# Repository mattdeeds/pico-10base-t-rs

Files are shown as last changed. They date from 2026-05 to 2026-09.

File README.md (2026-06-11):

# pico-10base-t-rs

**Software 10BASE-T Ethernet (PIO bit-bang TX *and* RX) and wireless
router on the Raspberry Pi Pico 2 W**. Uses the dual **Hazard3 RISC-V** cores with pure Rust (`no_std`).
A `~$5` micro talks 10 Mbit Ethernet to a real
network with PIO, DMA, a RS-485 transceiver, and magnetics.

Rust port of [C project](https://github.com/mattdeeds/Pico-10BASE-T), which extended
[kingyoPiyo/Pico-10BASE-T](https://github.com/kingyoPiyo/Pico-10BASE-T) (the
original C/PIO Manchester **TX-only** design) with a **RX** path — Manchester
decode over an RS-485 transceiver. This Rust rewrite runs on `rp235x-hal`, exposes
the NIC as a [smoltcp](https://github.com/smoltcp-rs/smoltcp) `phy::Device`, then
grows into a NAPT router with a cyw43 Wi-Fi AP.

## Two builds

The build features give you either layer with no code changes:

- **A standalone software 10BASE-T NIC** (default build): the bit-bang PHY +
  smoltcp. A static-IP host that does ARP / ICMP / UDP / a tiny HTTP server.
- **A wireless router** (`--features router`): the same 10BASE-T as the WAN, a
  cyw43 2.4 GHz AP as the LAN, with L3 forwarding + NAPT between them, a DHCP
  server, and a status page.

## What to expect (performance)

Full detail + method in **[`docs/performance.md`](docs/performance.md)**. Headlines
(measured on real hardware):

| Path | Throughput | Note |
|---|---|---|
| 10BASE-T **TX** (device→host, TCP) | best **~0.95–1.0 MB/s**, typical ~0.4–0.7 | near line rate when clean; half-duplex collision variance |
| 10BASE-T **RX** (host→device, TCP bulk) | **~310 KB/s** @ 0.2% wire loss | stock MTU; ACK-pacing + decode-out-of-IRQ fixes (2026-06) |
| 10BASE-T latency | **~2.6 ms**, 0% loss | |
| Wi-Fi LAN (cyw43 AP) | **~909 down / ~716 up KB/s** | router build |

> **It's a fun software-PHY NIC and a working router, not a
> fast router.** The bit-bang TX is near line rate; RX bulk runs ~310 KB/s
> (the long-suspected "decode/PHY ceiling" turned out to be a fixable
> DMA-starvation bug — see `docs/rx-bulk-ceiling.md` §10). Latency is great;
> ideal for low-rate / IoT-scale traffic.

## Hardware

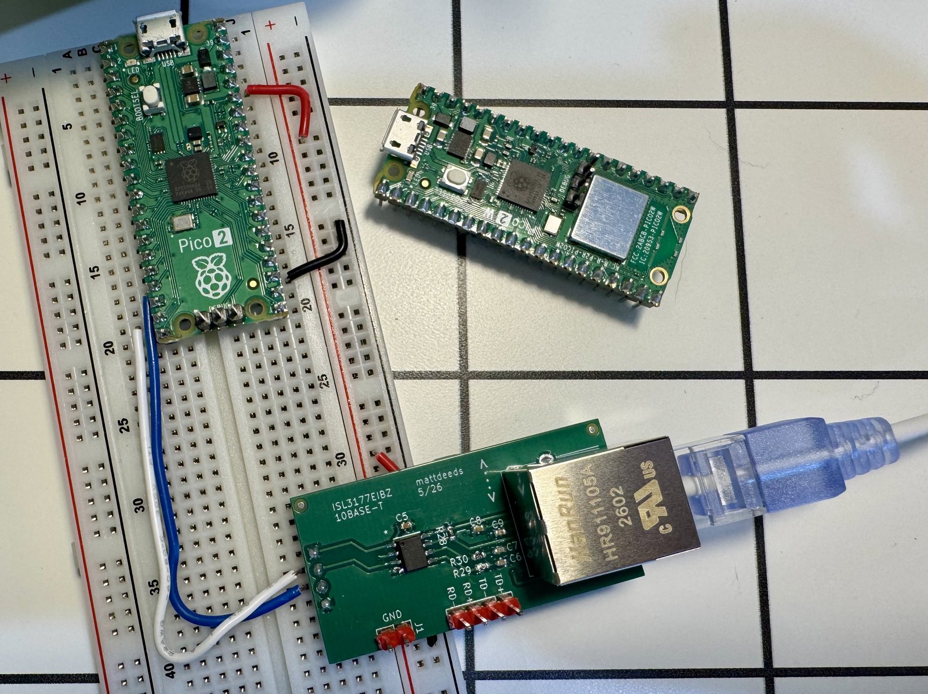
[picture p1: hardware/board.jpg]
The 10BASE-T front-end board (ISL3177E + HR911105A) on a breadboard with a Pico 2, a Pico 2 W alongside, and an Ethernet cable plugged in


- **Raspberry Pi Pico 2 W** (RP2350). The plain 10BASE-T NIC build also runs on a
  non-W Pico 2; the Wi-Fi/router builds need the W (cyw43).
- **External 10BASE-T front end:** an **ISL3177E** transceiver + **HR911105A** RJ45
  magnetics. KiCad board design + gerbers/BOM are in [`hardware/`](hardware/).

| Signal | Pico 2 pin |
|---|---|
| ISL3177E `RO` (receiver out → MCU) | GP13 |
| ISL3177E `DI` (driver in ← MCU) | GP14 |
| Onboard LED (heartbeat, NIC build) | GP25 |
| SWD debug probe | SWCLK / SWDIO / GND |

## Toolchain

- Rust ≥ 1.82, target `riscv32imac-unknown-none-elf`
  (`rustup target add riscv32imac-unknown-none-elf`).
- Flashing: [picotool](https://github.com/raspberrypi/picotool) (USB), or OpenOCD
  over SWD:
  `openocd -f interface/cmsis-dap.cfg -f target/rp2350-riscv.cfg -c "program <elf> verify reset exit"`.

## Build & flash

```bash
# Standalone 10BASE-T NIC (static IP 192.168.37.24) — the default build
cargo build --release
cargo run   --release            # flashes via the .cargo/config.toml runner

# Other variants
cargo build --release --features wan-dhcp    # NIC as a DHCP client (WAN-style)
cargo build --release --features wireless    # cyw43 AP only (no wired side)
cargo build --release --features router      # WAN(10BT) + LAN(Wi-Fi) + NAPT router
```

The device logs status over **USB CDC** (assert DTR to read it): `[R2b]` heartbeat,
`[Rx]` decode stats, and on the router build `[Cyw43]` / `[Wan]` / `[Fwd]` / `[Nat]`
/ `[Perf]` lines.

### Wired host setup (10BASE-T peer)

The device emits Normal Link Pulses only (no auto-negotiation), so force the peer
NIC to 10 Mbit half-duplex:

```bash
sudo ethtool -s <iface> speed 10 duplex half autoneg off
sudo ip addr add 192.168.37.19/24 dev <iface>
```

### Router credentials

The cyw43 AP SSID/passphrase are **compile-time placeholders** in
`src/wireless.rs` (`AP_SSID` / `AP_PASSPHRASE = "change-me-please"`). **They should be changed.**

## How it works

- **PIO0** drives the 10BASE-T PHY: **SM0** = 20 MHz Manchester TX (256-entry
  lookup table → single-ended on GP14), **SM1** = 60 MHz RX sampler (`in pins, 1`,
  3 samples/half-bit), **SM2** = a carrier-detect SM for the half-duplex CSMA/CA
  TX gate.
- **DMA** ferries the RX sampler into a double-buffer; **core 1** owns the
  `DMA_IRQ_0` handler running an **edge-tracking DPLL Manchester decoder** + FCS
  (re-anchors to each mid-bit transition to cancel clock drift).
- **core 0** runs smoltcp (the control plane) and, on the router build, an
  **embassy executor** hosting the cyw43 `Runner`, the LAN/WAN net tasks, and the
  custom L3 forwarding + NAPT data path. **PIO1** is a custom gSPI transport to the
  cyw43 radio.
- An **RP2350 hardware watchdog** auto-reboots + recovers the device if the loop
  ever wedges (a known intermittent hang under sustained full-MTU inbound).

## Repo layout

The package is **a library + a binary**: the transport core is a reusable
library crate that other projects can take as a Cargo dependency (e.g.
[pico-remote-probe](https://github.com/mattdeeds/pico-remote-probe), a
network-attached SWD debug probe, uses it as its NIC); the router application
in `src/main.rs` is the in-tree consumer.

- `src/lib.rs` — the **library**: `eth_tx`, `eth_rx`, `eth_rx_dpll`, `eth_mac`,
  `manchester`, `crc` (the **10BASE-T bit-bang NIC**, PHY + MAC), plus
  `multicore_riscv` (Hazard3 core-1 launch), `pico_reset` (picotool USB reset),
  `pio_util`, and — behind the `cyw43-phy` feature — `cyw43_phy` (a smoltcp
  `phy::Device` over the cyw43 radio, no executor required).
- `src/main.rs`, `src/wireless.rs`, `src/forward.rs`, `src/conntrack.rs`,
  `src/dhcp_server.rs`, `src/wan.rs` — the **router** (cyw43 + forwarding + NAPT).
- `docs/` — a thorough **engineering log** (how this was built + characterized).
  Start with [`docs/README.md`](docs/README.md).
- `tools/` — host-side measurement scripts.

## Limitations

Half-duplex (by MAC policy; the transceiver is FD-*capable* but FD only helps
contended traffic); no auto-negotiation; RX bulk ~310 KB/s (next bounds:
decode CPU time and the DMA half-fill ACK-latency floor — see
`docs/rx-bulk-ceiling.md` §10). A hardware watchdog guards against hangs
(the old full-MTU-inbound wedge stopped reproducing after the 2026-06 RX
restructure, but the watchdog stays).
Just an educational project, please don't replace your home router with this.

## Credits

- [kingyoPiyo/Pico-10BASE-T](https://github.com/kingyoPiyo/Pico-10BASE-T) — the
  original C/PIO 10BASE-T **TX** design (MIT, Copyright © 2022 kingyo). This project
  is a Rust port of the author's own
  [C project](https://github.com/mattdeeds/Pico-10BASE-T), which extended
  kingyoPiyo's work with the **RX** path (Manchester decode over an RS-485
  transceiver).
- [Niccle](https://github.com/timonvo/niccle) — a reference for the
  Manchester RX decode approach and circuit design.
- [embassy](https://github.com/embassy-rs/embassy) `cyw43` driver + firmware blobs
  (Infineon permissive binary license — see `cyw43-firmware/`).
- [smoltcp](https://github.com/smoltcp-rs/smoltcp), [rp235x-hal](https://github.com/rp-rs/rp-hal).

## License

Dual-licensed under either **MIT** ([LICENSE-MIT](LICENSE-MIT)) or
**Apache-2.0** ([LICENSE-APACHE](LICENSE-APACHE)), at your option. The cyw43
firmware blobs in `cyw43-firmware/` carry their own (Infineon) permissive license.

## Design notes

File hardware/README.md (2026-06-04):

# Hardware — 10BASE-T front-end board

KiCad project for the **10BASE-T analog front end** used by this project (and by
its [C ancestor](https://github.com/mattdeeds/Pico-10BASE-T)). It breaks an
**ISL3177E** RS-485 transceiver and an **HR911105A** RJ45 jack (integrated
magnetics) out to single-ended GP13 (RX) / GP14 (TX) on a Raspberry Pi Pico 2, so
the Pico's PIO can both drive and receive a real 10BASE-T differential line.

The circuit is based on the [Niccle](https://github.com/timonvo/niccle) reference
design. This is `v2` — a small prototype/test board, not a product.

> ⚠️ **Do not connect this to PoE equipment.** It's an educational software-PHY
> front end with no isolation guarantees beyond the magnetics.

## How it works

The ISL3177E is an RS-485 transceiver repurposed as a 10BASE-T line driver +
slicer:

- **TX:** Pico `GP14` → `DI` (driver input) → differential `Y`/`Z` → AC-coupling →
  HR911105A magnetics → RJ45 TX pair.
- **RX:** RJ45 RX pair → magnetics → differential `A`/`B` → `RO` (receiver output,
  single-ended Manchester) → Pico `GP13`, where the PIO sampler + software DPLL
  decode it.

See the repo's top-level [`README.md`](../README.md) ("How it works") for the
firmware side and the exact Pico pin map.

## Bill of materials

| Ref | Value | Footprint | Role |
|---|---|---|---|
| U1 | **ISL3177EIBZ** | SOIC-8 | RS-485 transceiver (TX driver + RX slicer) |
| J6 | **HR911105A** | RJ45 (Hanrun, horizontal) | jack + integrated magnetics |
| C5, C8, C9 | 100 nF | 0603 | supply decoupling |
| C6, C7 | 10 nF | 0603 | AC-coupling to the line |
| R28 | 100 Ω | 0603 | differential line termination |
| R29, R30 | 50 Ω | 0603 | source termination |
| J1 | 1×02 header | 2.54 mm | power (3V3 / GND) |
| J2, J3 | 1×04 header | 2.54 mm | signal / Pico connections |

(Source of truth: [`production/bom.csv`](production/bom.csv).)

## Files

- `10BASE-T_Test-v2.kicad_pro` / `.kicad_sch` / `.kicad_pcb` — the KiCad 10 project
  (schematic + PCB). Open `.kicad_pro` in KiCad.
- `production/` — fabrication outputs:
  - `10BASE-T_Test-v2.zip` — Gerbers + drill files (2-layer board), ready to send
    to any board house.
  - `bom.csv` — bill of materials.
  - `positions.csv` — pick-and-place / centroid (for assembly).
  - `designators.csv`, `netlist.ipc` — supporting fab data.

## Fabricating it

Upload `production/10BASE-T_Test-v2.zip` to a PCB fab (JLCPCB, PCBWay, OSH Park,
etc.) as a standard 2-layer board. For assembly, supply `bom.csv` + `positions.csv`.
To regenerate any of these, re-run the export from KiCad (the
[Fabrication Toolkit](https://github.com/bennymeg/Fabrication-Toolkit) settings
used are in `fabrication-toolkit-options.json`).

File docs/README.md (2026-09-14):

# docs/ — engineering log & design notes

This folder is the project's **engineering log**: how the software 10BASE-T NIC and
the router were designed, built, and characterized — including the dead ends and
the honest limits. It's deliberately kept (not pruned) because the "how we got
here" is half the value of a project like this.

## Start here

- **[performance.md](performance.md)** — *what to expect*: measured throughput,
  latency, CPU, and the honest limits. Read this first.
- **[router-plan.md](router-plan.md)** — overall router architecture: the "Option-A"
  decision (keep Hazard3 RISC-V, port the cyw43 transport — no embassy-rp), the
  PIO/DMA/core layout, the data path.

## Key findings (the interesting bits)

- **[rx-bulk-ceiling.md](rx-bulk-ceiling.md)** — the RX-of-bulk investigation. Its
  "PHY limit at ~100 KB/s" verdict was later overturned: the cause was DMA-starved
  sample loss, and RX now runs ~310 KB/s (see [performance.md](performance.md)).
- **[full-duplex-analysis.md](full-duplex-analysis.md)** — the ISL3177E is
  full-duplex-*capable* (half-duplex is a MAC policy). Forced-FD on-wire experiment:
  FD helps only contended traffic and is still RX-decode-bounded → not worth the
  auto-negotiation work.
- **[cpu-dpll-plan.md](cpu-dpll-plan.md)** + **[clock-recovery-decoder-plan.md](clock-recovery-decoder-plan.md)**
  — the RX Manchester decoder: an edge-tracking DPLL on core 1 that cancels clock
  drift; the offline corpus bench; and the §9d "residual is PHY-limited" verdict (since overturned).
- **[pio-dpll-report.md](pio-dpll-report.md)** — retrospective on the *PIO-side*
  decoder attempt (capped ~40% full-MTU → pivoted to the CPU DPLL on core 1).

## The build log (roughly chronological)

- **[pio-decoder-plan.md](pio-decoder-plan.md)** — the PIO clock-recovery decoder plan.
- **[r15-plan.md](r15-plan.md)** — WAN-as-DHCP-client + unifying both interfaces under one executor.
- **[r16-plan.md](r16-plan.md)** — L3 forwarding (LAN↔WAN transit).
- **[r17-plan.md](r17-plan.md)** — NAPT / conntrack (the router milestone).
- **[r18-plan.md](r18-plan.md)** — DNS relay + management status page.
- **[r19-plan.md](r19-plan.md)** — cold-start gateway-ARP fix.
- **[perf-characterization-plan.md](perf-characterization-plan.md)** — the perf track:
  the cyw43 LAN isolation + the gSPI 2→15 MHz fix, the routed-throughput rig.
- **[low-power-plan.md](low-power-plan.md)** — low-power roadmap (scoped, backburnered;
  gated on a power meter).

## Meta

- **[release-checklist.md](release-checklist.md)** — the open-source prep checklist.
- **[log.md](log.md)** — raw notes: history and lessons moved out of code comments.

> Note: some docs reference internal "R-numbers", "gotcha #N", and session notes
> (`RESUME.md`, not published) — that's the raw lab notebook.

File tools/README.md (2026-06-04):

# tools/

Host-side scripts for testing and characterizing the firmware. Most are plain
Python/bash with no dependencies beyond `iperf3`/`nc`/`ethtool` where noted.

## Measurement / telemetry
- **`cdc_read.py`** — read the device's USB-CDC telemetry for N seconds
  (`python3 tools/cdc_read.py 12`). Auto-detects the Pico CDC by product string;
  asserts DTR. The workhorse for reading `[R2b]`/`[Rx]`/`[Perf]`/… lines.
- **`rx-decode-sweep.py`** — RX FCS-fail rate vs frame size (UDP to a closed port =
  pure decode, no TCP). Drives the `docs/rx-bulk-ceiling.md` size curve.
- **`lan_upload.py`** — cyw43 Wi-Fi LAN upload throughput (client → device `:9999`
  sink); pairs with `curl http://<ap>/bulk` for download.

## Offline decoder bench
- **`clock-recovery/`** — develop the RX Manchester decoder without flashing:
  a captured raw-sample corpus + `harness.py` (scores per-byte error bins + FCS-OK)
  + `noise_compare.py` (matched-filter vs single-sample noise robustness). See its
  own README and `docs/clock-recovery-decoder-plan.md`.
- **`dpll-rust/`** — a small standalone Rust crate mirroring the decoder for offline
  iteration.
- **`conntrack_selftest.rs`** — host self-test of the NAPT conntrack logic
  (`rustc -O tools/conntrack_selftest.rs && ./conntrack_selftest`).

## Router / routed-throughput rig (needs root for setup)
- **`wan-test-host.sh`** — turn this host into the device's WAN upstream gateway
  (dnsmasq DHCP+DNS on the wired NIC + nftables masquerade out your uplink).
- **`rig-env.sh`** — shared config for the rig (sourced; override via env). ⚠️ set
  `AP_SSID`/`AP_PSK` to match your firmware AP creds (`src/wireless.rs`).
- **`router-rig-up.sh`** (root) → **`router-measure.sh`** (no root, iperf3 through
  the NAT) → **`router-rig-down.sh`** (teardown); **`router-throughput.sh`** is the
  all-in-one wrapper. See `docs/perf-characterization-plan.md`.
- **`r18-lan-validate.sh`** — LAN join + DNS-through-NAT + mgmt-page check.

## Misc
- **`99-pico-rust.rules`** — udev rules so the Pico CDC + CMSIS-DAP probe are
  accessible without root (`sudo cp tools/99-pico-rust.rules /etc/udev/rules.d/`).

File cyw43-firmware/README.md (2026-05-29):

# CYW43439 firmware blobs (vendored)

Binary blobs for the CYW43439 wireless chip on the Pico 2 W, vendored from the
[embassy](https://github.com/embassy-rs/embassy) project's `cyw43-firmware/`
directory (which in turn sources them from
<https://github.com/georgerobotics/cyw43-driver/tree/main/firmware>).

| File | Purpose |
|---|---|
| `43439A0.bin` | WiFi firmware (231077 B) |
| `nvram_rp2040.bin` | Board NVRAM for the Raspberry Pi Pico-W-family module (used on the Pico 2 W) |
| `43439A0_clm.bin` | CLM (country/regulatory) blob — loaded by `Control::init` |

Loaded 4-byte-aligned via `cyw43::aligned_bytes!`. See `src/wireless.rs`
(`cyw43_new_blocking`) and `docs/router-plan.md` §11. Licensed under the
Infineon permissive binary license — see the `LICENSE-*.txt` here.

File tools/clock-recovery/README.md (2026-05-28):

# Clock-recovery offline bench (Phase 0)

Offline platform for developing the clock-recovery decoder without flashing the
device per iteration. See `docs/clock-recovery-decoder-plan.md` for the full
plan and A1 for why this is needed (open-loop `F+4+6k` sampling drifts off over
a long frame; full-MTU RX is ~1.7% FCS-ok).

## What's here

- `corpus/*.bin` — raw RX **sample** buffers (packed sample bits, LSB-first,
  8 samples/byte) of full-MTU frames captured off the device. Each is one
  active run (~9155 bytes) for a frame whose payload is `payload[i] = i & 0xFF`.
  These carry the *real* ppm drift + jitter, so a decoder tested against them
  faces exactly what the device faces.
- `harness.py` — runs a candidate decoder over the corpus and scores it:
  per-byte payload error rate binned by frame position (shows drift) + FCS-ok
  count (the acceptance metric). Ships with `decode_current`, a faithful model
  of the on-device open-loop decoder.
- `capture.py` — host side of corpus collection (needs the capture firmware).
- `pio_dump.py` — host side of the **Phase 2b live PIO-decoder bring-up** (see
  below). Validates the real PIO decoder's decoded-byte output off the wire, and
  has an offline `--selftest` that needs no hardware.

## Baseline (current open-loop decoder)

```
$ python3 harness.py
... FCS-ok 0/N ...
  bin 0 frame-bytes   42-225     0.0%
  bin 1 frame-bytes  226-409     0.0%
  bin 2 frame-bytes  410-593     0.0%
  bin 3 frame-bytes  594-777     ~0-3%
  bin 4 frame-bytes  778-961    ~14-24%
  bin 5 frame-bytes  962-1145   ~17-50%   <- ~50% = sample point on a bit boundary
  bin 6 frame-bytes 1146-1329   ~35-74%
  bin 7 frame-bytes 1330-1513   ~82-89%
```

Perfect for ~575 bytes, then a monotonic ramp = clock drift.

## Phase 1 result — clock recovery (DONE)

`decode_edge_track` re-anchors to each per-bit Manchester transition (recurs
~6 samples apart at `F+5+6m`) and samples one sample before it (= `F+4+6m`), so
drift can't accumulate. On the corpus it drives **every bin to 0% and FCS-ok to
N/N** (robust across window W=1–3) — see `harness.py` output. This is the
algorithm to take to firmware (Phase 2); the per-bit edge search makes a CPU
port borderline vs the IRQ budget, so PIO-side recovery is the likely
production path (see `docs/clock-recovery-decoder-plan.md`).

## Workflow

1. Develop a candidate `decode_X(buf) -> (F, frame_bytes)` in `harness.py`,
   set `DECODER = decode_X`, run `python3 harness.py`, iterate to flat/N-of-N.
2. Port the validated algorithm into `src/eth_rx.rs` (Phase 2) and re-run the
   on-device acceptance tests (Phase 3).

## Phase 2b — live PIO decoder bring-up (`pio_dump.py`)

`src/eth_rx_pio.rs` is the production decoder: a PIO program (PIO1 SM0) that
re-syncs to every Manchester edge in hardware (the `decode_pio_model` algorithm,
SM @ 150 MHz, `[8]`-cycle boundary-skip). The TEMP scaffolding in `main.rs`
(Phase 2b) runs it **in parallel** with the working RX so the device stays
functional, drains its decoded-byte FIFO into a 2048-byte window, and dumps that
window over UDP broadcast `:1234` in 512-byte chunks
(`dec_id|seq|cap_len | data[512]`).

The decoded bytes ARE the decoded bitstream, LSB-first per byte (PIO `in`
shift-right + autopush(32) + `to_le_bytes`) — the exact bit order
`harness.sample_bit` uses — so `pio_dump.py` reassembles a window, finds the SFD,
extracts the frame, checks FCS, and scores the same per-byte error bins.

```
# Offline first — proves the host pipeline (model -> pack -> reassemble -> FCS)
# end-to-end without flashing. Expect FCS-ok N/N, flat bins, "self-test PASS".
$ python3 pio_dump.py --selftest

# On-wire (after flashing the Phase 2b firmware; SWD-flash the first time per
# docs/pio-decoder-plan.md §8). Blasts known-pattern full-MTU frames at the
# device and validates the dumped windows.
$ python3 pio_dump.py
#   dec_id 0: frame 1518B  sfd@bit 61  inv=False  FCS OK
#   ... FCS-ok N/N, flat bins  => PIO decoder works, D=8 is in the window.
```

Reading the result: **flat bins + FCS-ok** = the PIO decoder produces correct
full-MTU bytes and the `[8]` skip delay lands in the working window. A **drift
ramp** (like the open-loop baseline) = the skip delay is slightly off (resample
straying toward a bit boundary) — nudge the `[8]` in `eth_rx_pio.rs`. **No SFD /
garbage** = polarity or gross timing wrong. The valid `[n]` range is ~6–12
cycles (resample at `n+2`, between the boundary edge ~7.5 and the next mid-bit
~15); `8` targets the centre.

## Re-collecting / expanding the corpus

The corpus here is enough to start Phase 1, but the plan calls for more ppm/
jitter variation (capture across reboots / warm-up). To re-capture you need the
**temporary capture firmware** (kept out of `main` to keep it shippable):

- `src/eth_mac.rs` — add to `EthRxShared`: `cap_buf: [u8; CAP_MAX]`, `cap_len`,
  `cap_id`, `cap_armed` (`CAP_MAX = 10240`). In `process_completed_half`, after
  the `mac_accept` check, when `cap_armed && dst == our_mac && len > 8000`, copy
  `bytes[off..off+len]` into `cap_buf`, set `cap_len`, bump `cap_id`, clear
  `cap_armed`. Add `arm_capture()`, `cap_status() -> (id, len)`,
  `cap_copy(off, &mut [u8]) -> usize`.
- `src/main.rs` — every 20 ms send one chunk over `send_udp_broadcast` with the
  header `cap_id|cap_len|n_chunks|chunk_idx` + up to 512 data bytes, cycling
  `chunk_idx`; re-arm every ~200 chunks (~4 s); `arm_capture()` once at startup.

Then `python3 capture.py` (sends test frames + reassembles chunks into
`corpus/`). Revert the firmware before shipping.

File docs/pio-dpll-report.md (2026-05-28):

# PIO DPLL — what we tried, why it stops at ~40 % full-MTU

A retrospective on the Phase 2b–2d attempt to build a Manchester clock-recovery
decoder entirely in PIO on the RP2350. Companion to `pio-decoder-plan.md`
(detailed plan + iteration log) and the `pio-decoder-phase2b-onwire` memory.

Written 2026-05-28 after deciding to pivot to a CPU DPLL on the 2nd Hazard3
core.

## TL;DR

**Best PIO-only result: ~40 % full-MTU FCS-OK** (v1+180 MHz: `eth_rx_pio.rs`
at commit `d72360f`), with 6/6 FCS-OK at 512 B / flat 0 % bins on successful
decodes. **Ceiling is structural, not a tuning miss**: PIO has no arithmetic
for a real loop-filtered DPLL, the 2-cycle input synchronizer forces a
mutual-exclusion between "polls land on the edge" and "loop = bit period," and
mid-bit vs boundary Manchester edges are both real, validated transitions —
distinguished only by *phase*, which PIO can't track. CPU DPLL on the unused
2nd Hazard3 core is the path to ≥95 %.

## Goal (locked acceptance criteria, see `pio-decoder-plan.md` §11)

- **P1**: Full-MTU (1518 B frame) FCS-OK **≥ 95 %** at low rate, OR — if a
  residual floor remains — that floor is *PHY-limited* (flat per-byte error
  bins, no drift ramp, no slip cascade), not decoder-limited.
- **P2**: No loss-of-lock cascade. A single bit/edge error stays local; no
  frame may show the `0xaa`/`0x55` cascade signature.
- **S1**: small frames (≤512 B) no worse than baseline.
- **S2**: zero CPU decode cost (the Finding-2 payoff).

A1 baseline (open-loop CPU decoder, what we were trying to beat): ~575 B clean
then a drift ramp through 50 % to ~89 % errors at full MTU; full-MTU FCS-OK
~1.7 %.

## What we tried (iterations)

| Phase | Approach | Result | Why it didn't clear the bar |
|---|---|---|---|
| 2b — fixed `[8]` delay (`b863651`) | After mid-bit edge, blind delay D ≈ 0.67 bit, resample level, repeat | Clean to ~554 B (single-edge slip past that) | Wait catches *any* edge after the coast — a jittered boundary edge or noise becomes the new phase reference, slipping the loop |
| 2c — interval classifier (offline + PIO) | Measure inter-edge interval; classify ~T (mid-bit) vs ~T/2 (boundary); track at-mid/after-boundary state | Same slip rate as `[8]` | Inside runs of identical bits the Manchester signal is a clean square wave (edges every T/2); *every* interval is T/2, so interval gives no discrimination. The mid/boundary state alternation is then the entire decode — and a single bad edge flips it forever |
| 2d v1 — sample-by-pin (`5148c8a`) | 7 PIO instr: `nop[2] + in pins,1 [7] + jmp_pin + wait`. Bit value comes from `in pins, 1` (line level) not from state | 56–141 B @150 MHz; **926+ B with ~40 % full-MTU @180 MHz** (`d72360f`) | Sample-by-pin breaks bit-level cascade (a mis-tracked edge doesn't propagate to all subsequent bits via the LOW/HIGH state). But the **wait still has no phase qualification** — a single noise/jittered edge becomes the new phase and the SM slips into the half-bit boundary stream, producing the `0xaa`/`0x55` cascade |
| 2d v2 — windowed counter polling (`02bc710`) | Replace `wait` with `set x` + `jmp x--, poll` for a counter-driven window | Decoded 1 full 512 B payload byte-perfect once! But full-MTU drift +9 cyc/missed-window, desync within bits | Pre-poll (10) + polling fall-through (7) + jmp coast (1) + nop[4] coast (5) + jmp sample (1) = **24 cycles on the no-edge path** vs the **15-cycle bit period at 150 MHz**. The counter overhead doesn't fit |
| 240 MHz overclock + v1 (`8845a38`) | Same v1 PIO, just sysclk 180 → 240 MHz ⇒ 24 SM cyc/bit | Boots clean (ping 1.7–5.7 ms RTT), TX/RX dividers integer (TX÷12, RX÷4), no fractional jitter | Auto-adjusting `wait` still works at the new bit period. Useful infra but the structural blockers below don't change |
| 2d v3 — unrolled hard window (per GPT-5.5 review) | Trade instruction space (we have 25 free slots) for cycles — unroll `set x` + `jmp x--` into explicit `jmp pin, edge` polls; miss-coast via `.wrap` for 0-cyc return | Produced mostly idle `0xff` reads (1608 / 2048 bytes per window). No preamble visible | The math is *mutually exclusive*: to land polls on the synchronizer-delayed expected edge (PIO cyc 18 at 180 MHz) needs pre-poll = 17 cyc, leaving 1 cyc for the entire polling window — no fit. Keeping miss-coast = bit period forces polls to cyc 15-16, *before* the edge, so polls never catch → no acquisition |
| **2-SM clock+data split** (analyzed) | SM1 owns edge detection + windowing + IRQ at validated mid-bit; SM2 waits IRQ + samples at calibrated delay | Not implemented; analysis says won't break the ceiling | Same boundary-edge ambiguity. Glitch validation (delay + recheck after wait) filters noise but **not** boundary edges (which are real, validated line transitions). Distinguishing mid-bit from boundary requires phase tracking → arithmetic → PIO can't |

## The structural blockers (root cause analysis)

**Why no PIO design we tried clears ≥95 % full-MTU.** Three independent
constraints all hit at the same ceiling:

### 1. PIO has no arithmetic — can't do a loop-filtered DPLL

A real DPLL maintains a fractional phase accumulator and nudges it by a small
fraction of the edge error each iteration. The averaging is what gives
*single-edge ride-through* (P2): one bad edge moves phase by a tiny fraction,
not a whole bit period.

PIO has only **decrement** (`jmp x--`/`jmp y--`) — no add, no subtract, no
shift-by-N, no fractional arithmetic. The best PIO can do is *fully* re-anchor
to each detected edge — which is exactly the single-edge-sensitivity v1 has.
The offline-validated `decode_dpll_model` uses Python arithmetic; that
algorithm doesn't port to PIO.

### 2. The 2-cycle input synchronizer creates a structural cycle-budget mutual-exclusion

PIO sees pin transitions 2 SM cycles after the real-world edge (synchronizer
delay, in PADS). For a windowed DPLL where the polling lands on the expected
edge AND the loop period equals the bit period, the math requires *both*:

- Pre-poll cycles (sample + direction-decide) + N polls + return ≤ bit period
- First poll cycle ≥ bit period (so poll sees the synchronizer-delayed edge)

These are mutually exclusive: if first poll is at the bit period, you've
consumed the whole budget with pre-poll, leaving 0 cycles for the polling
window. Going to 180 MHz (18 cyc/bit) or 240 MHz (24 cyc/bit) doesn't change
this — the structural ratio is the same. Synchronizer bypass via
`PIOx.INPUT_SYNC_BYPASS` saves 2 cyc absolute but doesn't change the
relative cycle math inside a self-clocked loop, and adds metastability risk
on the irreversible phase decisions.

### 3. Mid-bit vs boundary edges are distinguished only by phase

In a Manchester signal during a run of identical bits, the line is a clean
square wave at the half-bit rate. *Every* edge is a real, validated line
transition (the line really does flip and stay flipped for ≥ a half-bit).
The only thing distinguishing a mid-bit edge (= data event) from a boundary
edge (= clock-only artifact) is **absolute phase relative to the bit clock**.

- Glitch validation (delay + recheck) filters only *noise glitches* (line
  blips back) — not boundary edges.
- Interval classification (T vs T/2) fails inside identical-bit runs (every
  interval is T/2 — see Phase 2c).
- Per-edge-decision designs (`wait`-based, polling-based) all catch boundary
  edges as if they were mid-bit edges, half-bit-slipping the phase forever
  after (the `0xaa`/`0x55` cascade signature).

The only fix is *absolute phase tracking* — which needs arithmetic (blocker #1).

### 4. Single-edge sensitivity → cascade slips

Once a wrong edge captures the phase reference, the `in pins, 1` sample lands
in the *wrong* half-bit forever after — the SM is decoding the half-bit
boundary stream of the same data. Output is a steady `0xaa`/`0x55` to
end-of-frame. This is what failed P2.

Sample-by-pin (v1's win over the `[8]` edge-tracker) helps because the bit
value comes from the line level, not from a LOW/HIGH state code path that
would also flip. But it doesn't help with phase capture — once phase is
half-a-bit off, sample-by-pin still reads the wrong half.

## What we did achieve

- **10× improvement over the A1 open-loop ceiling.** Open-loop CPU decoder
  capped at ~575 B with a 50 % drift ramp. v1+180 MHz reaches 926–1472 B
  with ~40 % full-MTU FCS-OK and a *flat* 0 % bin profile on every successful
  decode (no drift signature — the DPLL effect *is* real, just below 100 %).
- **Clean small-frame decode**: 6/6 FCS-OK at 512 B with flat 0 % bins.
- **S2 (zero CPU decode cost) achieved** for the bring-up. v1 PIO does all
  the Manchester decoding; CPU sees decoded bytes. (Frames still need SFD +
  FCS in CPU but those are far cheaper than the per-bit sample decode.)
- **Sample-by-pin is a genuine architectural insight.** Worth keeping in any
  future PIO Manchester work — bit-from-line-level beats bit-from-state for
  cascade resistance.
- **240 MHz overclock validated as safe** on this board (flash QMI handles
  60 MHz QSPI SCK; TX/RX dividers become integer; CPU 33 % faster). Useful
  infrastructure regardless of decoder direction.

## Useful artifacts to keep

- `src/eth_rx_pio.rs` — v1 sample-by-pin + wait PIO program (committed at
  `d72360f`). The reference PIO Manchester decoder for this PHY.
- `tools/clock-recovery/harness.py` — offline decoder bench. Contains
  `decode_current` (open-loop reference), `decode_edge_track` (CPU DPLL,
  FCS-OK N/N), `decode_pio_model` (validated for v1), `decode_pio_interval_model`
  (the failed interval classifier — useful negative reference),
  `decode_dpll_model` (the windowed-phase algorithm we couldn't fit in PIO).
- `tools/clock-recovery/pio_dump.py` + `analyze.py` — live on-wire validator
  and dump analyzer. Reusable for any future PIO RX work.
- `tools/clock-recovery/corpus/*.bin` — captured raw sample buffers from the
  real PHY. Carries the wire's real ppm + jitter.
- `docs/pio-decoder-plan.md` — full plan with all iteration logs, cycle math,
  and the GPT-5.5 design review corrections.

## Lessons learned (carry forward)

1. **Statistics: need ≥100 frames per measurement point.** Our N-sweep used
   3–5 windows per point and back-to-back identical-code runs went 40 % → 0 %.
   Most of the apparent N-sweep signal was statistical noise.

2. **Flat bins on successful decodes ≠ P2 met.** P2 is about *failure* mode —
   our failures cascade with `0xaa`/`0x55` to end-of-frame, so P2 was never
   actually satisfied at the v1+180 MHz baseline (one of GPT-5.5's catches).
   Always look at the failure pattern, not just the success rate.

3. **Synchronizer bypass doesn't save cycle budget** in a self-clocked PIO
   loop. The 2-cycle synchronizer is a constant offset, not freed cycles.

4. **PIO `wait` is the wrong primitive when the failure mode is "wrong edge
   captured."** `wait` has no phase qualification; once it completes, you're
   committed. Polling allows windowing but has its own structural-budget
   problems.

5. **Verify on hardware with ≥100 windows before claiming a design works.**
   Cycle math on paper is necessary but not sufficient — small effects
   (synchronizer behaviour, PHY edge jitter) can invalidate a design that
   looks clean.

6. **Get a second opinion when you're hitting a wall.** GPT-5.5's review
   caught two real errors in my reasoning (P2 metric, synchronizer cycle
   accounting) and pushed v3 (which didn't work, but for *informative*
   reasons we now understand structurally).

## Path forward — CPU DPLL on the 2nd Hazard3 core

The validated `decode_edge_track` algorithm (Phase 1, offline FCS-OK N/N on
the corpus) runs on a CPU core. Dedicate the unused 2nd Hazard3 core to the
NIC RX path. Sidesteps PIO's lack of arithmetic and synchronizer constraints;
also addresses A1 Finding 2 (single-core load collapse) via core separation.

Plan in `pio-decoder-plan.md` §9 (Fallback). Bigger refactor than the PIO
attempts (smoltcp glue + IRQ migration + DMA into the second core's RAM
region) but it's the design that has the **arithmetic and state needed for
a real DPLL with loop filter**, which is what ≥95 % full-MTU requires.

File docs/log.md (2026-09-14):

# Engineering log

Raw notes: history, experiments, lessons learned. Code comments describe the
current state only; the "why it got this way" lives here. Sections are by
module. Dates are when the change or finding happened, where known.

Much of this was moved out of source comments on 2026-09-14. Git history
before that date has the original wording.

## Open issues

- **`cpu1=` under-reads core-1 load.** `CORE1_BUSY` wraps only `DMA_IRQ_0`
  (`eth_mac.rs`). Perf step 2 added it when the IRQ ran the whole ≤2.57 ms
  decode. Since the 2026-06-10 restructure (`212662d`), decode runs in
  `drain_rx_images` on core 1's thread, outside the span, so `[Perf] cpu1=`
  counts only capture + re-arm. Fix: also bracket `drain_rx_images`.
- **`EthRxStats::frames_filtered` doc was wrong.** It said "runs that
  peek_dst_mac accepted but couldn't decode". The code counts MAC-filter
  rejects. Doc fixed 2026-09-14; the code was not changed.
- **`StatsDelta::carry` is never incremented.** Carry caps are merged
  separately in `process_completed_half`. Harmless, but dead.
- **Mislabeled CPU readouts.** The mgmt page prints `core1(rx-decode)=` and
  `[Perf]` prints `cpu1=`, but both come from `CORE1_BUSY` (IRQ only; see above).
- **`nb` dependency looks unused.** Nothing in `src/` references it.

## Transport history (RX)

- **Port origin.** `eth_rx.rs` ports `rx_10base_t.pio` and the decoder from
  `eth_rx.c` in the C reference repo (`../Pico-10BASE-T`). The 60 MHz sampler
  (3 samples per half-bit) matches the C version.
- **R6:** RX became IRQ-driven (`DMA_IRQ_0`).
- **R10:** the edge-track DPLL (`eth_rx_dpll`) replaced the open-loop
  locked-once decoder. The stated reason was clock drift: open-loop per-byte
  errors ramped from byte ~575 to ~89% at the tail of full-MTU frames (the
  "A1 ramp-from-575 B" failure mode). The open-loop decoder came back behind
  `decoder-openloop` for the FCS-ceiling A/B against Niccle's fixed-stride
  pipeline. Note: the 2026-06-10 finding below suggests much of the
  full-MTU "cliff" was DMA starvation, not drift.
- **R12c:** RX decode moved to core 1. `RX_SHARED` locks are never held across
  the decode, so core 1's decode can't starve core 0 (the point of the move).
  `Spinlock<0>` is used because `critical_section` reserves `Spinlock<31>`.
- **2026-06-10, `212662d`: decode moved out of the IRQ.** Scan + decode used
  to run inline in `DMA_IRQ_0`, ahead of the DMA re-arm. Under load that took
  longer than one half-fill (~2.18 ms), the chain completed with nothing
  armed, and the 8-word PIO RX FIFO overflowed ~200×/s, silently truncating
  frames in flight. This was misread for weeks as a clock-drift "decode
  cliff". Now the IRQ only captures the image and re-arms (~0.6 ms worst);
  core 1's thread decodes from a 6-slot image ring. Result: RX ~310 KB/s at
  ~0.2% loss at stock MTU. The `rxstall` and `img_drop` counters watch it.
  Lesson: the DMA must always be serviced, even on overload (discard slot),
  or the HAL Transfer desyncs and RX dies permanently.
- **`BUF_WORDS` (16 KB halves):** the half-fill time is a latency floor under
  every RX→response cycle. With decode out of the IRQ there's no decode
  deadline, so smaller halves are viable if the per-half overhead is worth
  it. `poll_into` handles frames longer than a half via carry accumulation.
  Not tested at other sizes since the restructure.
- **`MAX_CARRY_BYTES`:** raised from 12 KB to 16 KB after post-R5 telemetry
  showed some frames getting their preamble clipped at the cap.
- **`find_active_run_from`:** walks every run in an image, not just the
  longest. That fixed loss when two frames landed in the same DMA half.
- **Open-loop packer optimizations:** single pass with no intermediate bit
  `Vec`; the sample bound is hoisted out of the loop; the offset strides by 6
  instead of recomputing `f + 4 + 6k`; unchecked reads over a proven range;
  decode capped at the header-declared length. Dropping a partial trailing
  byte matches the old `avail / 8` truncation.
- **`sample-rate-20mhz`** (FCS-ceiling triage, experiment 5): 1 sample per
  half-bit, matching Niccle's pipeline. This is the Nyquist minimum, so edge
  tracking can't work and the feature forces open-loop.
- **`mss-clamp`** (`docs/rx-bulk-ceiling.md` §5/§9/§10): clamped MTU to 1000
  to dodge the "decode cliff". Obsolete as a lever since 2026-06-10: full-MTU
  RX now beats any clamped value. Kept only as an experiment knob.
- **`INBOX_SLOTS = 4`:** covers two concurrent flows (e.g. ping + UDP echo)
  landing several frames in the same DMA half.
- **`FRAME_SNAP_BYTES = 128`:** dst/src MAC + EtherType + IPv4 header + a few
  payload bytes, matching the `main.rs` hex-dump width.

## DPLL decoder (`eth_rx_dpll.rs`)

- Phase 3b CPU DPLL port of `decode_edge_track` from
  `tools/clock-recovery/harness.py`. Validated against the corpus: FCS-OK N/N
  with flat per-byte error bins.
- The naive port cost ~3–9 ms/frame on the wire, a problem while decode ran in
  the IRQ. Second pass: `get_unchecked` after proving the bound, `find_edge`
  inlined and unrolled for W=1, and a decode-length cap from the IP header.
- Third pass (2026-06-10): the W=1 window for `next_center = tr+6` is 4
  contiguous samples (`tr+4..=tr+7`), and the resynced data bit (`new_tr - 1`)
  always lands inside it. So each bit needs one two-byte load, an XOR, and an
  8-entry table, replacing 5 separate sample reads per bit.
- Window sweep: W=1/2/3 all gave the same ~50% full-MTU FCS-OK, so failures
  weren't jitter beyond ±W. W=1 is the cheapest. (Measured before the
  DMA-starvation fix, so the 50% was mostly sample loss.)
- Tie-break and boundary coasting match Python `find_edge` (strict `<`,
  `hi = min(ns-1, center+W)` clamp).

## MAC (`eth_mac.rs`)

- **`max_burst_size`** (2026-06-10, wired rig, immediate-ACK sink in
  `main.rs`): smoltcp clamps the advertised TCP window to
  `max_burst_size × MSS` (`iface/packet.rs`), so this is the RX-of-bulk
  pipelining knob. It does not limit TX.
  - `Some(1)`: ~135 KB/s. Serialized, one segment per ACK round trip.
  - `Some(2)`: ~183 KB/s. The host pipelines full-MTU segments; ~27% decode
    loss is absorbed by TCP fast retransmit.
  - `Some(4)`: ~178 KB/s. No gain, more loss (~32% FCS-fail).
  - `Some(2)` is BDP-matched for half-duplex 10BASE-T.
- **TX token clamp:** smoltcp's own egress is capped at the IP MTU, but R17
  NAPT forwarded frames pass raw frame lengths up to `MAX_FRAME_BYTES`. The
  old `[u8; MTU]` buffer overflowed on a 1514 B forwarded frame and halted.
- **Perf span in `DMA_IRQ_0`:** perf step 2 bracketed the IRQ so core-1 RX
  load showed in `mcycle`. The NIC build omits it to keep the proven hot
  path unchanged. See the open issue above.

## TX (`eth_tx.rs`)

- **Port origin:** `ser_10base_t.pio` and `udp.c` from the C reference repo.
  `MANCHESTER_TABLE` is copied verbatim from `udp.c`.
- **CRC before PIO writes:** computing the bitwise CRC mid-flight (~27 µs
  between the body and FCS pushes) underran the 8-deep TX FIFO (~6 µs to
  drain). The line stalled mid-frame and the host saw bad FCS.
- **Critical section around FIFO writes:** added at R6, when the RX decoder in
  `DMA_IRQ_0` could preempt the TX loop for ~100 µs. Since R12c that IRQ runs
  on core 1, but the section still blocks other core-0 interrupts. Cost is
  ~50 µs for a max-size frame.
- **IFG padding (12 idle words ≈ 9.6 µs):** without it, back-to-back smoltcp
  egress (queued ARP→ICMP, or ICMP reply then UDP) left < 9.6 µs between
  frames and the host scored the second as bad FCS. This was a regression
  versus polled mode.
- **NLP padding:** if `iface.poll` sends a frame right after the NLP tick, the
  preamble lands in the host's post-NLP/IFG window and fails FCS.
- **Phase 3d carrier sense:** Phase 3c's multicore RX removed the implicit
  carrier sense (gotcha #10), exposing collisions (idle TCP 596 → 45 KB/s).
  A PIO SM now watches RO; the TX gate is in software.
- **Phase 3e CSMA/CA:** after carrier sense, the main residual was a
  synchronized start. The Pico finishes a segment, the wire frees, and the
  Pico's next segment and the host's ACK start together. A random 0–15 µs
  backoff per TCP frame breaks the tie. Curl's TCP segments go through
  `send_raw_frame`, so collisions concentrated there.
- **`raw_frame`** was a `static mut`; now owned by `EthTx` (no aliasing hazard,
  no Rust 2024 hard error).
- **Dividers at 150 MHz sys_clk:** TX ÷7.5 and RX ÷2.5, each ±3.3 ns jitter,
  within 10BASE-T tolerance. Integer at 240 MHz.
- **`full-duplex`:** see `docs/full-duplex-analysis.md` §7. Only correct
  against a peer forced to 10M full duplex.

## Multicore (`multicore_riscv.rs`)

- The first Phase 3a attempt used `rp235x-hal` 0.4's `Multicore::spawn`. It
  pokes `ICB.ACTLR` (`enable_actlr_extexclall`) and reads `PPB.VTOR`. On
  Hazard3 the Cortex-M PPB is powered down, so VTOR reads garbage and the
  ACTLR write faults. Core 0 hung in `read_blocking()`
  (`docs/cpu-dpll-plan.md` §9a).
- RISC-V specifics come from pico-sdk `pico_multicore/multicore.c`. The
  bootrom protocol is `[0, 0, 1, vector_table, sp, entry]` (RP2350 datasheet
  §5.3 / §5.5.5). The trampoline mirrors pico-sdk byte for byte.
- The stack guard (`stack_bottom`) was skipped for the Phase 3a bring-up.
- Core reset reads `frce_off` back, as in HAL `spawn` and pico-sdk
  `multicore_reset_core1`, which also fences buffered APB writes.

## CPU counters (`cycles.rs`)

- Perf characterization step 2 (`docs/perf-characterization-plan.md` §2).
  `FWD_BUSY` is the fraction of core-0 wall clock spent forwarding, not total
  core-0 load (executor, smoltcp, and cyw43 SPI are outside the spans). This
  is the "cycles/sec in the routing path" from `docs/router-plan.md` §8.3.
- LAN-isolation step 4 (§3.5) added `CYW43_SPI_BUSY` and `LAN_NET_BUSY`.
  `spi0 + net0` ≈ core-0 load in a LAN-only test. The gSPI busy-poll was the
  prime suspect (decision matrix row 3 → gSPI DMA, §4-G); the 2→15 MHz gSPI
  fix came out of this.
- `permille_over` divides by measured µs because on the first LAN run core 0
  saturated, `Timer::after(1ms)` slipped, the `n % 1000` window stretched to
  several seconds, and a fixed 1 s divisor read >100%.
- `enable_mcycle` was verified not to fault on RP2350. `mcycle` wraps every
  ~18 s at 240 MHz, ~28 s at 150 MHz.

## cyw43 adapter (`cyw43_phy.rs`)

- R14.3. cyw43's `NetDriver` implements only the async
  `embassy_net_driver::Driver`. The sync `try_rx_buf`/`try_tx_buf` API lives on
  the producer-side `ch::Runner`, which cyw43's `Runner` owns and never
  exposes. This corrected `docs/router-plan.md` §12.1, which assumed otherwise.
- No `embassy-net` dependency: one smoltcp stack serves both interfaces.
- `CYW43_TX_BUSY` (LAN-isolation step 3, §3.5): a high count under `/bulk`
  download means cyw43 TX buffering or the gSPI Runner is the wall, not the
  radio. Near-zero TX-busy with low throughput points at the air.
- No RX-drop counter: cyw43's `runner.rs` drops inbound frames silently
  (`try_rx_buf()→None`, only a defmt `warn!`). At the smoltcp boundary
  `receive()→None` just means idle. RX loss is inferred: low sink KB/s with
  low `net0`/`spi0` means the radio; with core 0 pinned means we can't drain.
- `link_up` was folded back from pico-remote-probe's copy when the module
  moved into the library.

## DHCP server (`dhcp_server.rs`)

- R14.4. smoltcp ships only a DHCP client; the server reuses smoltcp's
  `DhcpRepr`/`DhcpPacket` codec (`proto-dhcpv4`) instead of hand-rolled BOOTP.
- R18 added the DNS option. No DNS relay needed: R17 NAPT forwards LAN→WAN
  UDP, so queries to the offered resolver are NAT'd like any flow
  (`docs/router-plan.md` §6.4). The default 8.8.8.8 lets resolution work
  before the WAN lease lands.
- `POOL_LEN` is public so the R18 mgmt page can't silently undersize its body.

## WAN client (`wan.rs`)

- R15a: blocking `main_10bt` loop (`--features wan-dhcp`). R15b: the
  executor's `wan_task` (`--features router`), beside the cyw43 LAN. Same
  functions drive both. Design: `docs/r15-plan.md` §5/§6.
- Ping to 8.8.8.8 and resolving `example.com` were the R15 acceptance checks
  (#3 is DNS). NAPT/forwarding came later (R16/R17).

## Small modules

- **`pico_reset.rs`:** R0–R8 flashing needed a manual BOOTSEL press or OpenOCD
  (RESUME.md gotcha #4). picotool sends a Class-type request
  (`bmRequestType=0x21`) to the vendor interface. TinyUSB's vendor driver
  dispatches both types, so pico-sdk works either way; usb-device routes
  strictly, so we accept Class and Vendor.
- **`crc.rs`:** bitwise, no table. At <1K frames/s it costs ≈100 µs/s at
  150 MHz.
- **`lib.rs`:** the DPLL was productized in Phase 3b; `cyw43_phy` (R14.3) is
  behind the narrow `cyw43-phy` feature so consumers skip the full wireless
  stack.

## Conntrack (`conntrack.rs`)

- R17. The incremental checksum helpers (`add1c`, `checksum_incr`) were
  verified offline against full recompute before landing: a known IPv4
  vector, 250k random rewrites, and one's-complement carry edges
  (`docs/r17-plan.md` §5).

## Forwarding (`forward.rs`)

- R16 added L3 forwarding (design: `docs/r16-plan.md`). smoltcp silently
  drops frames to our gateway MAC with a foreign dst IP, and its neighbor
  cache is private, so forwarding lives beside the two `Interface`s.
- R17 added NAPT in the same device. `WAN_CT` is a static, not an
  `Option<Conntrack>` field, so the LAN device carries no cost.
- Neighbor learning uses ARP as well as IPv4 sources because the useful IPv4
  traffic (ping replies) has off-subnet source IPs.
- R19 cold-start fix: the first forwarded LAN→WAN frame was dropped
  (`[Fwd] drop`) while `WAN_NEIGH` was empty. `wan_task` now ARPs the gateway
  as soon as a lease provides one, then once a second until learned (robust to
  a reply lost on the half-duplex wire), then stops.
- `critical_section` also covers the TIMER0 IRQ (time driver).

## Firmware entry (`main.rs`)

- Build history: R4.4 smoltcp, R4.6 UDP echo, R7 HTTP server, R12c/R12e
  production loop, R14.1 split `main_10bt` out so `wireless` can replace the
  data path, R15a `wan-dhcp`, R15b router dispatch. Host test recipes for the
  static IP live in RESUME.md.
- **Watchdog** (`docs/rx-bulk-ceiling.md` §6): the device wedged under
  sustained full-MTU inbound (link drops, no NLPs, CDC silent, only SWD could
  recover it). A 6 s hardware watchdog fed from the core-0 loop or an executor
  task gives ~12× margin over legitimate stalls (TX critical section ~50 µs,
  cyw43 gSPI bursts ~ms). The root cause of the hang is still open.
- **240 MHz overclock** (Phase 2d v3): integer PIO dividers remove fractional
  jitter. Flash corruption at the higher QMI SCK is recoverable via SWD.
  `clock-150mhz` was FCS-ceiling triage experiment 6.
- `CORE1_TICKS` (Phase 3a) proved core 1 launched and that SRAM is coherent
  across cores: plain atomic store/load (`sw`/`lw`), no lr/sc reservations.
- **Bulk-test 32 KB send window** (Phase 3e): residual carrier-sense-gap
  collisions (no true collision detect) trigger fast retransmit (~ms) instead
  of an RTO stall (~200 ms), which was what drove throughput variance.
- **fd-bench sink immediate ACK** (branch `rx-ack-pacing`): with the small
  advertised window, the 10 ms delayed-ACK timer dominated the per-segment
  cycle (~15 ms → ~96 KB/s). Worse, its fixed phase sat on Linux's tail-loss
  probe timer (`max(2·srtt, 10 ms)`): host probe retransmits and our delayed
  ACKs collided on the half-duplex wire, a 27–33% FCS-fail floor that fell to
  3–5% (1-segment window) once ACKs went immediate. Coalescing
  (`ack_delay = 1 ms`) was strictly worse (~54–78 KB/s, 43% fail): a
  timer-fired ACK lands mid-stream of the next inbound segment.
- **USB serial = chip ID** (gotcha #4): with a static string, `picotool -f`
  rebooted the chip into BOOTSEL but couldn't match the BOOTSEL device and gave
  up.
- **`http-bulk-test`** (FCS-ceiling triage, experiment 4): 1 MB over HTTP to
  compare against Niccle's 620 kB/s at "0 invalid CRC". The 0x55 payload
  matches `/tmp/blast_udp_full_mtu.py` so per-byte error scans share a basis.
  An old comment claimed an 8 KB TX buffer; it is 32 KB.
- fd-bench's loop-iteration counter separates a loop/`max_burst` rate cap
  (iters/s ≈ frames/s) from a TCP-level cap. The `mcycle` counters stay
  router-only.

## Wireless (`wireless.rs`)

- **R13 "Option A":** keep Hazard3 + `rp235x-hal` and bridge to embassy with a
  time driver, the RISC-V executor, and our own PIO1 gSPI (no `embassy-rp`, no
  `cyw43-pio`). The module was first written as a compile-only milestone
  before the Pico 2 W arrived.
- **Bring-up sequence (R13):**
  1. Bit-bang probe of TEST_RO (expect 0xFEEDBEAD), logged over the existing
     10BT CDC/UDP telemetry.
  2. PIO1 probe, since a CPU bit-bang can't match the timing the chip's input
     synchronizer expects.
  3. The PIO probe also read floating data on a MicroPython-verified board, so
     a pin self-test confirmed the pads could be driven.
  4. Gotcha #11: a floating CLK/DATA during WL_ON power-up can latch the CYW43
     into the wrong gSPI mode. Holding the bus idle before power-up (as
     embassy does) was "the one thing we got wrong vs the driver".
  5. Step 2: real `cmd_read`/`cmd_write`. Step 3: bring-up via `block_on`.
  6. R14.1: a persistent executor with a continuous Runner, which `block_on`
     couldn't provide once it returned.
- **gSPI clock:** bring-up ran at 2 MHz (PIO 4 MHz). The LAN-isolation run
  (`docs/perf-characterization-plan.md` §3.5) showed that 2 MHz bus (≈250 KB/s
  raw), not the radio, capped throughput (download 168 KB/s). Raised to 15 MHz
  gSPI (30 MHz PIO; ÷8 at 240 MHz, ÷5 at 150 MHz): download 168 → 909 KB/s,
  upload 30 → 716 KB/s. embassy runs the same 2-cycle program at ~33 MHz;
  30 MHz gSPI is an optional next step.
- `wait_for_event` still actively polls; the host-wake IRQ isn't wired (idle
  `spi0` ~72%).
- **`cdc_write_all`** (R16): `serial.write` returns a partial count. The longer
  `[Wan]` line overflowed the ~128 B usbd-serial IN buffer and truncated
  counters. This was also the long-standing "CDC drops bytes under load".
- **Measured rate windows:** on the first LAN run core 0 saturated,
  `usb_task`'s 1 ms cadence slipped, and fixed-1 s rates over-read
  (`spi0` > 100%).
- Milestones: R14.2 AP, R14.3 LAN `Interface` (acceptance: a client at
  192.168.4.2 pings .1), R14.4 DHCP, R14.5/R18 mgmt page, R15b router, R16
  forwarding, R17 NAPT, R18 DNS offer, R19 gateway pre-ARP.
- The mgmt HTTP 32 KB TX buffer at a 5 ms poll gives a ~6.4 MB/s ceiling,
  above any 2.4 GHz rate, mirroring the 10BT `http-bulk-test` window.
- The standalone `wireless` image doesn't start 10BASE-T
  (`docs/router-plan.md` §11/§12). Gotcha #5: the host must assert DTR to see
  CDC output. Gotcha #9: NLP keepalive.

- **Removed 2026-09-14:** the unused R13 bring-up code: the bit-bang probe
  (`probe_cyw43`, `bitbang_cmd_read`, `PHASE`, `gpio_read`), the PIO probe
  (`probe_cyw43_pio`, `pio_cmd_read32`), the pin self-test (`pin_selftest`,
  `CYW43_PIN_LO/HI`), the `CYW43_PROBE*` statics, `cmd_word`, `swap16`,
  `PIN_PWR`, and `cyw43_bringup_blocking` (the `block_on` bring-up) with its
  `embassy-futures` dependency. Also the `[Cyw43]` block in `main.rs`'s
  `log_status`, which could never run. Recover them from git history before
  that date.

## Build features (`Cargo.toml`)

- **`diag`:** off by default to keep the log short and the binary small. The
  `[R2b]` heartbeat and `[Rx]` summary always print.
- **`decoder-openloop`** (FCS-ceiling triage, post-R10): swaps the DPLL for the
  pre-R10 open-loop decoder at the same call site, for on-wire comparison with
  Niccle's fixed-stride pipeline. The default binary is byte-identical.
- **`sample-rate-20mhz`** (experiment 5): tests whether 60 MHz oversampling
  exposes transient noise that a 20 MHz fixed-stride pipeline can't see.
- **`clock-150mhz`** (experiment 6): rules out supply-noise or VREG-margin side
  effects of the overclock. Combined with the decoder features it maps the
  6-cell decoder × clock matrix.
- **`http-bulk-test`** (experiment 4): replaces the R8 info page with a 1 MB
  stream to compare against Niccle's 620 kB/s at "0 invalid CRC". If throughput
  matched while our FCS counter read 30–70% fail, hypothesis #4 (their counter
  masks silent SFD-lock failures) would make the gap paper-only.
- **`full-duplex`:** the ISL3177E is full-duplex capable; half duplex is a MAC
  policy. A duplex mismatch is worse than half duplex.
- **`fd-bench`** (`docs/full-duplex-analysis.md` §7.3, Tier 2): push bulk into
  the device while `http-bulk-test` streams out, to measure the concurrent
  aggregate (H3) and the core-1 decode ceiling (H4). Used for both the
  HD-bidir control and the FD-bidir run.
- **`mss-clamp`** (`docs/rx-bulk-ceiling.md` §5): kept inbound frames under the
  supposed ~600 B clock-drift decode cliff. That cliff was later found to be
  DMA starvation.
- **`wan-dhcp`** (R15a) and **`router`** (R15b): `wan-dhcp` leaves the static-IP
  NIC build and its R4–R8 host recipes unchanged. Design: `docs/r15-plan.md`.
- **`cyw43-phy`:** exists so pico-remote-probe's `wifi` build can reuse the
  adapter with its own runtime.
- **`wireless`** (R13): "Option A", keeping Hazard3 and porting the cyw43 SPI
  transport (`docs/router-plan.md` §4/§5). `embassy-executor` is decoupled
  from `embassy-time` and has the riscv32 backend Hazard3 needs.
- **`embassy-time` `generic-queue-16`:** a fixed-capacity queue that works with
  any waker, independent of the executor's timer storage. It is the robust
  choice for a hand-rolled driver outside embassy-rp.
- **`embassy-net-driver` 0.2.0** must match cyw43 0.7.0 exactly, or the
  `Driver` trait is a different type (R14.3 wraps it with a no-op waker).

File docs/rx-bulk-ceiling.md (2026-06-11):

# RX-of-bulk decode ceiling — characterization

**One-liner:** the device receives bulk TCP at only **~100 KB/s** (vs ~970 KB/s for
TX) because at full-MTU **~30 % of inbound frames fail FCS from clock drift**, which
collapses the host's TCP congestion window to 1–2 segments (`ss`: cwnd 10→1–2,
ssthresh→2, thousands of retransmits, RTT a healthy 3 ms). It is **loss-limited**,
**not** loop/`max_burst` (the main loop runs ~107 K iters/s), RTT, inbox, or DMA.
A **secondary receive-window ceiling** (~1–2 segments in flight) surfaces once loss
is removed. **The intuitive MSS-clamp fix was tested and REFUTED** (§5) — small
frames decode clean but hit the window ceiling at *lower* throughput (34 KB/s).

**Status:** characterization + MSS-clamp + frame-rate-ceiling + decode-fix
experiments done (2026-06-03). Follow-on from the full-duplex experiment
(`docs/full-duplex-analysis.md` §7.9 / H4), which surfaced the ~102 KB/s figure.
**The decode loss is PHY-limited (§8) — the firmware decoder is near its floor;
the durable fix is a hardware PHY**, not more decoder work
(`docs/cpu-dpll-plan.md` §9d).

> **DECISION (2026-06-03): ACCEPTED — track closed.** RX-of-bulk stays ~100 KB/s;
> this is a PHY limit, not a firmware bug worth more decoder effort. The device is
> solid for low-rate / small-frame traffic; bulk RX is the documented ceiling. The
> durable fix (a real Ethernet PHY) is **deferred to a future board revision**, not
> scheduled. Still open (firmware, separate): the sustained-full-MTU **hang** (§6) →
> add the RP2350 watchdog. The optional load-dependence re-check (§7) was not run —
> we accepted the PHY-limited verdict on the existing §9d + §8 evidence.

---

## 1. Why this matters

The FD experiment found device **TX of bulk ≈ 970 KB/s** but **RX of bulk
≈ 102 KB/s** — a ~9× asymmetry, and the binding constraint on bidirectional
throughput (the upload direction, never benchmarked before). TX is cheap
(Manchester-encode + PIO out); RX is the expensive path (60 MHz PIO sample → DMA →
core-1 DPLL decode + FCS). This characterizes *what* caps RX.

## 2. Method

- Build: `--features "http-bulk-test fd-bench diag"` (NIC build; `diag` lights up
  the `[Mac]` line with `inbox_drop`/`inbox_hwm`/`carry_cap`; `fd-bench` adds the
  port-9999 TCP sink + `[Sink]` rate). No new firmware — existing counters.
- Host = the 10BT NIC `enp1s0f0` (10M, duplex matched to firmware), device static
  `192.168.37.24`. Bulk upload = `dd | nc … :9999`. Pure-decode size sweep =
  `tools/rx-decode-sweep.py` UDP to a **closed port (1239)** → frames are decoded +
  FCS-counted on core 1 *before* smoltcp drops them (no socket, no ICMP in this
  build) → isolates RX decode from TCP/ACK/echo entirely.
- Read `[Rx] dec/ok/fail`, `[Mac] inbox_drop/hwm/carry_cap`, `[Sink] rx KB/s` over
  CDC.

## 3. Findings

### 3.1 It is decode FCS-failure, not handoff or DMA

Sustained bulk upload (device RX, ~100 KB/s):
`[Rx] dec≈190/s ok≈137/s fail≈53/s` (**~28 % FCS fail on full-MTU TCP**), with
`[Mac] inbox_drop=0  inbox_hwm=1  carry_cap=0`.

| Hypothesis | Verdict |
|---|---|
| **D** core-0 can't drain the inbox | ❌ ruled out — `inbox_drop=0`, `inbox_hwm=1` |
| **E** decode-per-DMA-half > 2.18 ms half-fill | ❌ ruled out — `carry_cap=0` (wire ~idle at 100 KB/s) |
| **C** TCP window / ACK cadence | ❌ not the cause — pure-UDP decode (no TCP) fails the same |
| **B** FCS-fail / clock-drift at full-MTU | ✅ **confirmed** (see 3.2) |

### 3.2 The size cliff (pure RX decode, random payload)

| frame size | 64 | 512 | 700 | 850 | 1000 | 1150 | 1300 | 1472 |
|---|---|---|---|---|---|---|---|---|
| **RX FCS-fail %** | ~4 | ~3 | 29 | 49 | 41 | 16\* | 42 | **72** |

\* clock-offset (δ) noise — see 3.3. **Knee ≈ 600–700 B.** Clean below it,
catastrophic above. This is the textbook clock-drift signature: bit errors
accumulate with frame length, so P(≥1 bit error → FCS fail) climbs with size — the
same mechanism `docs/clock-recovery-decoder-plan.md` §1 models (50 % errors at
~byte 1050 for δ≈60 ppm; this device's knee sits a bit earlier → higher current δ).

### 3.3 Caveats

- **Payload content matters.** An all-`0x55` payload (preamble-like) inflated the
  mid-size points (64→7.7 %, 512→35 %) vs **random** payload (64→~4 %, 512→~3 %).
  The random/representative curve above is the one to trust; `0x55` is an artifact.
- **δ-variance noise.** Each ~4 s window samples a different instantaneous oscillator
  offset (temperature/warm-up), so near-threshold fail% swings run-to-run
  (e.g. 1150 B read 16 % between 1000 B@41 % and 1300 B@42 %). Trend is robust; point
  values are noisy.
- **Rate matters too.** Sustained UDP full-MTU at ~400 pps read ~72 % vs ~28 % under
  real TCP bulk — tighter inter-frame spacing likely starves the decoder's per-frame
  re-acquire. Both confirm "full-MTU fails badly"; the exact % is size × rate × δ.

## 4. Why this caps RX-of-bulk at ~100 KB/s — `ss`-grounded

Diagnosed with the host TCP state (`ss -tino` of the upload connection) + an
on-device main-loop counter (`[Sink] loop=/s`). Two facts kill the candidate
explanations and pin the real one:

- **Not the loop / `max_burst_size`.** The main loop runs **~140 K iters/s idle,
  ~107 K/s under upload** — with `max_burst_size = Some(1)` that's ~107 K frames/s
  of capacity, ~700× the actual ~150 frames/s. The earlier "~150 frames/s is a
  per-poll rate cap" hypothesis is **refuted**.
- **Not RTT.** `ss` RTT is **2–5 ms** throughout (healthy LAN).

**Full-MTU (the real case) is LOSS-limited.** During a full-MTU upload, `ss` shows
the host's **cwnd collapse 10 → 1–2, ssthresh 64076 → 2, with thousands of
retransmits** — the textbook signature of a high-loss path. The 32 % FCS decode
failures (§3) make TCP treat the link as congested; cwnd pins at 1–2 segments →
~100 KB/s. **Decode reliability is the binding constraint for full-MTU RX-of-bulk.**

**A second, lower ceiling lurks underneath: receive-window / in-flight.** With the
MSS clamp (small frames, 0 % loss) `ss` shows **cwnd 10 (idle), 0 retrans, but only
unacked 1–2** — the host has cwnd headroom yet keeps ~1–2 segments outstanding, i.e.
the device's advertised window (or app pacing) caps in-flight depth. That's why the
clamp's clean-decode run still only reached 34 KB/s.

## 5. Mitigations — MSS clamp TESTED and REFUTED

**TCP MSS clamp (the intuitive "cheap fix") does NOT work — it makes throughput
worse.** `mss-clamp` feature lowers `eth_mac::MTU` → smaller advertised MSS → peer
sends sub-knee frames; bulk upload into the :9999 sink:

| device MTU | on-wire frame | RX FCS-fail | upload goodput | `ss` limit |
|---|---|---|---|---|
| 500  | ~526 B | ~0 % | **34 KB/s** | rwnd/in-flight (cwnd idle) |
| 1000 | ~1026 B | ~1–13 % | **68 KB/s** | mixed |
| 1500 | ~1526 B | ~32 % | **99 KB/s** | loss (cwnd collapse) |

Clamping removes decode loss but trades it for the receive-window ceiling at *lower*
absolute throughput (smaller frames). **Conclusion: do not clamp MSS.**

Real levers, in priority order:
1. **Fix full-MTU decode — but it's PHY-limited (firmware near-exhausted; see §8).**
   Eliminating the FCS loss would stop the cwnd collapse, but `cpu-dpll-plan.md` §9d
   already showed the residual is **analog PHY noise** (flat per-byte error profile,
   ~5.8e-5/bit), and the §8 offline experiment confirms a noise-robust (matched-
   filter) bit decision gives no net gain. **The durable fix is hardware** (a real
   Ethernet PHY / better analog front-end), not the firmware decoder.
2. **Then raise the receive-window / in-flight depth.** Once loss is gone, the
   ~1–2-segment in-flight cap (rwnd or app pacing) becomes the limit — investigate
   smoltcp's advertised window vs the 32 KB sink buffer (and whether window scaling
   is off). Only worth chasing after lever 1.
3. **Not the loop** — `max_burst_size`/main-loop is not a bottleneck (107 K/s); do
   not spend effort there.

## 6. Robustness bug found (separate)

A **sustained full-MTU inbound stream hung the device** — first seen under a
max-rate UDP flood, then **again during a full-MTU TCP bulk upload** (the MTU-1500
baseline run): link dropped (no NLPs → host `Link detected: no`), CDC went silent,
but USB stayed enumerated and SWD still worked; a reflash/reset recovered it
cleanly. Rate-limiting (~400 pps UDP) and small frames (the clamp runs) avoided it,
so it correlates with **sustained full-MTU inbound volume**, not a specific size.
No `inbox_drop`/`carry_cap` preceded it → the hang is elsewhere (decode/IRQ
livelock or a panic). DoS-shaped, but full-MTU bulk RX is normal traffic, so this
matters.

**RECOVERY DONE (2026-06-03): RP2350 hardware watchdog added** (`main.rs`
`WDT_TIMEOUT_US` = 6 s; fed from the core-0 poll loop on the NIC build and a
dedicated `watchdog_feed_task` on the router/wireless executor). The device now
**self-reboots + recovers** if the loop/executor wedges, instead of needing a
manual SWD reflash. Validated on-device: (a) **no false-trip** — `t`/`hb` climb
continuously past the timeout under idle + heavy flood/upload stress (NIC and
router builds); (b) **fires + recovers** — a deliberate-stall test build (stop
feeding after 15 s) rebooted ~6 s later (USB re-enumerated, `t` reset to 1). The
intermittent hang itself did **not** reproduce across three flood/upload attempts
this session, so it wasn't observed being recovered directly — but the watchdog is
armed and the firing path is proven. **Still OPEN: root-cause the hang** (it's a
recovery, not a fix) + a reliable repro (backlog §4-F).

## 7. Next steps

- **Decode is PHY-limited (§8) — the durable fix is HARDWARE** (a real Ethernet PHY
  / better analog front-end). The firmware edge-track decoder is near its floor.
- **One rigorous check before fully closing the firmware door:** the on-device fail
  rate varies (≈50 % at light load §9d vs 28–72 % this session) — if part is
  *load-dependent* (not pure PHY) it'd be firmware-addressable. Confirm by re-running
  the §9d per-byte-error dump **under sustained bulk load** (instrumentation
  recoverable from commits `ab72c89..f0253c8`); a flat profile = pure PHY, a
  ramp/cliff = a firmware-fixable load component.
- **Receive-window / in-flight depth** (§4) — secondary; only matters once loss is
  gone (i.e. after a PHY fix). Cheap to check smoltcp's window vs the 32 KB buffer.
- **The sustained-full-MTU hang (§6): RP2350 watchdog DONE** (recovery validated).
  Still open: a reliable repro + root-cause (the watchdog recovers it, doesn't fix it).
- **Ruled out, don't pursue:** `max_burst_size`/main-loop (107 K iters/s), RTT
  (3 ms), MSS clamp (§5), and a naive matched-filter decision (§8).

## 8. Decode-fix investigation — PHY-limited (firmware near-exhausted)

The full-MTU FCS loss that drives the §4 cwnd collapse is **analog PHY noise**, not
a decoder bug:

- **Prior (`cpu-dpll-plan.md` §9d):** the edge-track DPLL is offline-validated
  perfect (FCS N/N on the corpus) and fits the IRQ budget. On-device it gets ~50 %
  full-MTU; a failed-frame **per-byte error dump was FLAT** (~0.1–1.1 %, ~5.8e-5/bit),
  matching iid noise statistics — verdict *"as good as it can get against this PHY."*
- **This session (offline `tools/clock-recovery/noise_compare.py`):** tested the one
  untried firmware lever — a **matched-filter (integrate-both-half-bits) bit
  decision** vs the current single-sample (`tr-1`) — by injecting per-sample noise
  into the corpus. At the operating point it gives **no net gain** (p=3e-4: edge 33 %
  vs MF 31 %) and is *worse* on clean for some frames (66 % vs 100 %) because half-bit
  integration needs precise half-bit phase that varies frame-to-frame, while `tr-1`
  sits robustly at the half-bit centre. (iid noise is an upper bound — real
  correlated/baseline-wander noise helps the MF even less.)

**Conclusion:** firmware decode is near its floor. The remaining firmware avenue (a
full NCO-phase-tracked matched filter) is complex and §9d predicts marginal returns.
The high-value lever for full-MTU RX is a **hardware PHY** — ties to the
`docs/full-duplex-analysis.md` "real PHY" option and any board respin.

## 9. RX-of-bulk: ACK pacing + window + MTU sweep — 96 → ~200 KB/s (2026-06-10)

Branch `rx-ack-pacing`. Three coordinated changes, each A/B'd on the wired rig
(`/tmp/rx_bench.sh`-style: `cat /dev/zero | nc <dev> 9999`, flow control =
device RX rate, 3-5 runs per config; FCS% from `[Rx]` lines with dec>50):

| config | mean RX | FCS-fail |
|---|---|---|
| baseline: `Some(1)` + 10 ms delayed-ACK | 93–96 KB/s | 27–33 % |
| immediate ACK, `Some(1)` | 129–141 | 3–5 % |
| immediate ACK, `Some(2)` (full MTU) | 163–198 | ~27 % |
| immediate ACK, `Some(4)` (full MTU) | 163–186 | ~32 % |
| **immediate ACK, `Some(2)`, `mss-clamp` MTU=1000** | **174–208** | **1–3 %** |

1. **`set_ack_delay(None)`** on the :9999 sink (main.rs). At a 1-segment
   advertised window smoltcp's immediate-ACK rule (>1 MSS unacked) can never
   fire, so every segment paid the full 10 ms delayed-ACK timer — and that
   fixed 10 ms phase sits exactly on Linux's tail-loss-probe timer
   (`max(2·srtt, 10 ms)` = 10 ms at our sub-5 ms srtt), so host probe
   retransmits and our delayed ACKs repeatedly transmitted into each other on
   the half-duplex wire. Most of the "27–33 % decode loss" at baseline was
   actually this collision storm (device decoded 2–3× more frames than
   goodput). Immediate ACKs ride the post-frame quiet gap. ACK *coalescing*
   (1 ms delay ≈ ACK every 2nd segment) is strictly worse (54–78 KB/s, 43 %):
   a timer-fired ACK lands mid-stream of the next inbound segment.
2. **`max_burst_size = Some(2)`** (eth_mac.rs). smoltcp clamps the advertised
   window to `max_burst_size × MSS` (iface/packet.rs; RX-window-only — TX
   verified unaffected at 505–941 KB/s). With ACK pacing fixed, 2 segments
   in flight lets the host pipeline; `Some(4)` adds loss with no gain
   (PR #1 regressed mainly because it opened the window *without* fixing
   ACK pacing).
3. **`mss-clamp` MTU 500 → 1000** (eth_mac.rs). The decode cliff (§5/§8) is
   sharp and sits just above 1004 B on-wire: 1004 B → ~1 % fail, 1104 B →
   12 %, 1204 B → ~25 %, 1504 B → ~30 %. MTU=1000 rides just under it.
   §5's refutation of MTU=500 still stands — and is now explained: at the
   old serialized 15 ms/segment regime, small segments just meant less data
   per cycle; under pipelining, tripling the frame/ACK rate explodes
   post-frame-gap contention (44 % fail). Bigger-but-sub-cliff wins.

The §4 "track CLOSED at ~100 KB/s" verdict is superseded: ~200 KB/s with the
clamp feature on, ~180 KB/s at stock MTU. The decode cliff itself (§8,
PHY-limited) still stands and is the binding constraint again.

### 9.1 Tried and rejected: DMA-half latency attacks

The per-segment cycle still carries the DMA half-fill latency (a frame can't
decode until the 16 KB / 2.18 ms half containing its end completes — also why
idle RTT is ~2.5 ms). Three attempts to cut it, all benched, none kept:

- **8 KB halves** (with carry accumulated across swaps — that fix IS kept in
  `poll_with`): decode (~1.7 ms for a 1 kB frame) runs inline in `DMA_IRQ_0`,
  so the half-fill time is also the decode deadline; 1.09 ms halves overran
  it and clipped the following back-to-back segment. 128–157 KB/s @ 50 %
  fail. Don't shrink `BUF_WORDS` without first moving decode out of the
  re-arm path.
- **Core-1 busy-poll live decode** (scan the in-flight half via the DMA write
  cursor, decode each frame as its run terminates): cut idle RTT to ~1.1 ms
  but regressed bulk. Root cause of the regression was never pinned —
  the UDP "discriminator" used to chase it was confounded (see below).
- **In-IRQ live scan piggyback** (one early scan at the end of each
  `DMA_IRQ_0`): clean, but a wash (161–198 KB/s) — at `Some(2)`/MTU-1000 both
  in-flight segments usually land in the *same* half and decode together, so
  the boundary case it accelerates is rare. Removed; not worth the unsafe
  cursor-aliasing complexity.

Next lever for the cycle time is **decode CPU cost** (~1.7 ms/kB-frame on the
240 MHz Hazard3): the DPLL inner loop, not more TCP/window tuning.

### 9.2 Methodology gotchas (so the next session doesn't repay this tuition)

- **UDP-to-closed-port is NOT a "no device TX" RX test**: smoltcp answers
  every datagram with ICMP port-unreachable (~160/s measured) and those
  replies collide with subsequent inbound frames. A whole bisect tree
  ("busy core 1 corrupts sampling") was built on this confound before the
  `tx_icmp` counter exposed it. Use **UDP broadcast** (no ICMP reply,
  `tx_icmp=0`) for a true zero-TX RX test.
- **Open question (pre-existing, NOT from this session's changes):** even on
  production builds, an unsynchronized 250 f/s × 996 B UDP broadcast blast
  fails ~50 % FCS while flow-controlled TCP at the same frame size fails ~1 %.
  Candidates: NLP TX landing mid-frame, the 4 ms cadence vs 2.18 ms half
  cadence, host NIC burst behavior. Worth its own investigation.

## 10. The "decode cliff" was DMA-starvation sample loss — decode out of the IRQ → ~310 KB/s at stock MTU (2026-06-10)

Follow-up to §9, chasing decode CPU time. The optimization work surfaced a far
bigger find: **the full-MTU FCS-fail "cliff" (§3-§5, §8) was never clock
drift or analog noise — it was silent sample loss from the RX DMA being
starved while the decode ran in front of the re-arm.**

### 10.1 The mechanism (instrumented, not inferred)

- PIO FDEBUG `RXSTALL` (RX FIFO overflow, checked per half) fired **~200×/s**
  under a 250 f/s broadcast blast on the pre-fix code, and 0 at idle.
- `mcycle` timing showed the `DMA_IRQ_0` handler peaking at **2.9-4.6 ms,
  exceeding the 2.18 ms half-fill period** under load. The double-buffer
  chain then completed with nothing armed; the 8-word PIO RX FIFO (4.3 µs)
  overflowed; whole stretches of samples vanished mid-frame.
- A truncated frame followed by genuine idle is exactly what captured failing
  runs showed (clean periodic Manchester, then early cut, then idle).
- The loss concentrated on *straddling* frames because a frame straddles a
  half boundary ⟺ the (long) handler runs during its flight. Flow-controlled
  TCP at 16 KB halves accidentally phase-locks frame arrivals to the half
  cadence (host sends right after our ACKs, which fire right after a half
  completes) — few straddlers, so the loss hid for months and only blast
  tests / large frames / small halves exposed it.

This retroactively re-explains most of the §3-§5 matrix: the sharp
1004→1504 B "cliff" tracks when a 2-segment TCP burst outgrows what fits
inside one half between handler runs, not a per-frame decode property. §8's
"PHY-limited" verdict is superseded for this failure mode (the offline corpus
always decoded clean — consistent with sample loss, not noise). The
sustained-full-MTU device wedge (§6) also stopped reproducing after the fix
below (plus an overload path that must still service the DMA — see
`eth_mac::process_completed_half`).

### 10.2 The fix: bounded IRQ, decode in thread context

- `EthRx::poll_into` (was `poll_with`): the IRQ now only builds the
  processing image — `carry ++ settled-half`, one continuous sample stream,
  no stitched/in-place split — into a slot of a 6-deep image ring, updates
  the carry, and **re-arms the DMA, all in bounded ~0.6 ms**.
- Core 1's thread loop (`eth_mac::drain_rx_images`, between WFIs) scans +
  decodes the ring with **no deadline coupling to the DMA** at all.
- Overload (ring full) degrades to counted whole-image drops (`img_drop` on
  the diag log) via a discard slot — the DMA is *always* serviced; skipping
  service desyncs the HAL Transfer's channel accounting and kills RX
  permanently (found the hard way).
- Two supporting fixes from the same investigation: the trailing
  not-yet-terminated run is excluded from the scan (it used to decode as a
  truncated head, fail FCS, and decode again via the carry — inflating
  fcs_fail by the straddle rate); and the DPLL hot loop reads each bit's
  4-sample edge window + data bit from ONE two-byte load (~2× decode
  speed, bit-exact vs the old decoder over 200k fuzz inputs + corpus).

### 10.3 Results (wired rig, immediate-ACK + 2-seg window from §9)

| metric | before (§9 best) | after |
|---|---|---|
| RX-of-bulk, stock MTU 1500 | ~180 KB/s @ ~30% FCS-fail | **~310 KB/s @ 0.2%** |
| RX-of-bulk, mss-clamp 1000 | ~200 KB/s @ ~1% | ~300-324 KB/s @ 0.2% |
| 250 f/s broadcast blast | ~52% FCS-fail | **0.7-1.6%** |
| RXSTALL (FIFO overflows) | ~200/s under load | 0 |
| sustained full-MTU blast | device wedge (watchdog) | no wedge observed |

`mss-clamp` is now obsolete as a performance lever (kept as an experiment
knob). Health counters to watch on the diag build: `rxstall` (must stay 0 —
any nonzero means samples were lost) and `img_drop` (decode backlog).

Remaining levers if more RX speed is wanted: decode CPU cost is still the
cycle's biggest term (~1-1.5 ms/frame keeps the ring shallow under blast);
smaller DMA halves are now viable again (the decode-deadline coupling is
gone) and would cut the ~2.2 ms ACK-latency floor; and the §9 ACK/window
tuning could be revisited against the now-clean link.

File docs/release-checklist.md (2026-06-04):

# Release / open-source prep checklist

**Progress:** Phase 1 ✅ (`b2c8d99`) · Phase 2 ✅ (`f910d0b`) · Phase 3 ✅ (`6ef58b8`) ·
Phase 4 ✅ (committed `cdc_read.py`/`lan_upload.py` + `tools/README.md`; scrubbed the
old AP creds from `rig-env.sh`/`r18-lan-validate.sh`; CI deferred — optional) ·
Phase 5 ✅ (fresh-clone build of all 4 configs passes; Cargo.lock now committed for
reproducibility; tagged v0.1.0). **Remaining: owner flips the repo public.**

Wrapping the project for public sharing (2026-06-03). Decisions locked:

- **Structure:** one binary, feature-gated — default build = standalone software
  10BASE-T NIC; `--features router` = full wireless router on top. No crate split
  (documented layering instead; a future "extract the PHY as a crate" is optional).
- **Performance:** fresh on-device re-run of the 10BASE-T headline numbers →
  `docs/performance.md` + a README table; cite the established cyw43-LAN / routed
  numbers with dates/conditions.
- **License:** dual **MIT OR Apache-2.0** (Rust standard). Upstream
  kingyoPiyo/Pico-10BASE-T is **MIT, Copyright (c) 2022 kingyo** — compatible;
  preserve its notice (this is a port).
- **Dev docs:** keep all 14 (the engineering log is a selling point) + add an index.

## Phase 1 — legal / safety (blocking)
- [ ] `LICENSE-MIT` (our copyright + upstream kingyo attribution) + `LICENSE-APACHE`.
- [ ] `Cargo.toml` metadata: license, repository, authors, keywords, categories, readme.
- [ ] **Scrub hardcoded AP creds** (`wireless.rs` `AP_SSID`/`AP_PASSPHRASE`) → obvious
      placeholders + "change me" warning. (Was a real WPA2 passphrase.)
- [ ] cyw43 blobs: confirm the Infineon permissive-binary license stays + is referenced
      (already in `cyw43-firmware/`).
- [ ] Credits: kingyoPiyo/Pico-10BASE-T (port source) + Niccle (reference) in README.

## Phase 2 — final performance characterization
- [ ] Fresh on-device (10BT NIC, the centerpiece): TX, RX-bulk, small/idle, full-MTU
      FCS reliability, latency, CPU. (Current host↔Pico-10BT rig.)
- [ ] Cite (recent committed runs): cyw43 LAN down/up (909/716, §3.5), routed/NAPT,
      the full-duplex finding, the decode/PHY ceiling, the watchdog.
- [ ] One digestible `docs/performance.md` ("what to expect") + README summary table +
      honest caveats + how-to-reproduce.

## Phase 3 — README + docs index
- [ ] Rewrite `README.md`: what it is → the two layers → hardware + wiring → build/flash
      + toolchain → performance summary → architecture overview → limitations → credits
      → license.
- [ ] `docs/README.md` index framing the 14 dev-log docs as "how we got here"; point to
      the key ones (architecture, performance, full-duplex, rx-bulk-ceiling).
- [ ] Decide RESUME.md fate (internal session-pointer — keep as dev notes or tuck).

## Phase 4 — tooling tidy
- [ ] Commit the `/tmp` measurement scripts that matter (`cdc_read.py`, the upload/blast
      helpers) into `tools/` with a `tools/README.md` so the characterization reproduces.
- [ ] Keep `full-duplex` / `fd-bench` / `mss-clamp` features (off by default), documented
      as "measurement/experiment features."
- [ ] Optional: CI (GitHub Actions) building all 4 feature configs.

## Phase 5 — publish
- [ ] Fresh-clone build test (toolchain instructions actually work).
- [ ] Tag `v0.1.0`.
- [ ] Flip the repo public (owner action).

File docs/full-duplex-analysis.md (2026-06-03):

# Full-duplex 10BASE-T — feasibility analysis

**One-liner:** the board is **full-duplex-capable hardware** running a
**half-duplex MAC by policy**. Going full-duplex is a firmware + link-negotiation
exercise, **not** a board respin. The headline win is killing the half-duplex
collision/RTO collapse on bidirectional TCP (gotcha #10), not a clean 2× of line
rate.

**Status:** analysis only — nothing implemented. Written 2026-06-03 after a
hardware-fact correction (see §2). Sits in the §4 backlog next to radio
modularization (`docs/perf-characterization-plan.md` §4-B).

---

## 1. Why this matters

Today the 10BASE-T (WAN) link runs **half-duplex**: TX carrier-senses the RX line
and defers, then does CSMA/CA random backoff (`eth_tx.rs` — `wait_carrier_idle`
:237, `csma_acquire` :208). That's the correct MAC behaviour for a link both ends
treat as half-duplex, but it's also the root of the dominant bidirectional-TCP
limiter: **gotcha #10** — the Pico's TX colliding with the host's ACKs, each
collision costing a TCP RTO (`docs/cpu-dpll-plan.md:665`; the 596 → 45 kB/s cliff
that Phase 3d/3e carrier-sense + CSMA/CA only partially patch).

Full-duplex removes collisions *by definition*. The question is what it would take.

---

## 2. Hardware verdict: full-duplex-CAPABLE (corrected)

**Prior misconception (now corrected).** An earlier read assumed "ISL3177E =
RS-485 transceiver = single shared differential pair = half-duplex, hears its own
TX." That is **wrong for this part.**

Per the Renesas/Intersil datasheet, the ISL317xE family — ISL3170E, ISL3171E,
ISL3173E, ISL3174E, ISL3176E, **ISL3177E** — is **configured for full duplex
(separate Rx-input and Tx-output pins)**: a separate driver pair and receiver
pair (four bus pins), *not* a shared A/B node. Mouser's line description confirms:
"RS-422/RS-485 … FL DUPLX." Combined with the **HR911105A** RJ45 magnetics
(standard separate TX and RX transformer windings), the analog front end supports
**simultaneous bidirectional** signalling.

**The collision problem is NOT evidence of a shared physical medium.** In
half-duplex 10BASE-T a "collision" is a *MAC-policy definition* — transmitting
while RX carrier is present — even on a link whose TX and RX pairs are physically
independent. Gotcha #10 happens because *both ends run half-duplex CSMA/CD*, not
because the wire forces it. The pairs never physically interfere; the half-duplex
peer simply declares a collision and jams/aborts → lost frame → RTO.

Corroborating evidence the pairs are separate: the carrier-detect SM watches RO
(GP13) to sense the **peer's** carrier (`eth_tx.rs:149`). If RO echoed the Pico's
own TX, that gate would read "busy" on every one of its own frames and be
nonsensical. It senses the peer ⇒ separate pairs.

> **One thing still worth confirming from the schematic** (not in-repo): that the
> board wires the driver pair and receiver pair to *separate* magnetics windings
> (near-certain given an FD transceiver + standard module). Only `DI`←GP14 and
> `RO`→GP13 reach the MCU (`README.md:30-31`); DE/RE are tied permanently enabled,
> so the driver always drives the TX pair and the receiver always listens on the
> RX pair — exactly the full-duplex wiring.

---

## 3. What's already in place (digital datapath)

The silicon side is ~80% ready — TX and RX are fully disjoint resources:

| Resource | TX | RX |
|---|---|---|
| PIO state machine | PIO0 **SM0** (`eth_tx.rs:119`) | PIO0 **SM1** (`eth_rx.rs`) |
| GPIO | GP14 (DI) | GP13 (RO) |
| Clock | 20 MHz Manchester | 60 MHz sampler |
| DMA | none | CH0/CH1 double-buffer |
| CPU | **core 0** (`send_raw_frame`) | **core 1** (`DMA_IRQ_0` decode) |

`main.rs:303` notes "SM3 + PIO1 are free." The chip can clock out a frame on
SM0/GP14 while SM1/GP13 samples an inbound frame into DMA and core 1 decodes it —
concurrently, on a different core. Nothing in the datapath serializes the two
directions.

**Cross-core concurrency is already safe.** TX wraps its FIFO writes in
`critical_section::with` (`eth_tx.rs:310`), but the rp-hal critical-section impl
masks only the *local* core's interrupts + holds `Spinlock<31>`. Core 1's RX
decode IRQ keeps running during a TX frame, and RX shared state uses `Spinlock<0>`
(`eth_mac.rs:142`) — a different lock, no contention. TX-on-core-0 and
RX-decode-on-core-1 do not block each other today.

---

## 4. What full-duplex actually requires

| Requirement | Status | Effort |
|---|---|---|
| Analog: separate TX/RX pairs | ✅ already capable (FD transceiver + separate-winding magnetics) | none |
| Disjoint PIO SMs / DMA / cores | ✅ already (SM0 TX, SM1 RX, core 0/1) | none |
| Cross-core TX↔RX-decode concurrency safe | ✅ already (CS masks core 0 only; RX uses `Spinlock<0>`) | none |
| Drop CSMA/CD MAC policy | gate carrier-sense + `csma_acquire` behind a `full-duplex` mode | easy |
| **Both ends agree full-duplex** | ❌ we emit only NLPs → peer defaults to HALF | **the real work** |
| Sustain bidirectional rate | bounded by core-1 RX decode (existing limit), not by FD | see §5 |

### 4.1 The real blocker: duplex agreement

We send **Normal Link Pulses** every 16 ms (`main.rs:566`) and nothing else. NLPs
carry no duplex info, so a switch/NIC parallel-detects us as **10BASE-T half**.
Run FD on our side without the peer agreeing and you get a **duplex mismatch**
(one end late-collisions, the other FCS-errors → *worse* than half-duplex). Two
paths:

1. **Forced config (pragmatic — do this first to prove it).** Force both ends to
   10M-FD: on a Linux peer `ethtool -s <if> speed 10 duplex full autoneg off`, or a
   managed switch port set to "10 full." Zero negotiation code; lets us measure FD
   immediately behind the firmware mode flag.
2. **FLP auto-negotiation (proper, interoperable).** Replace NLPs with Fast Link
   Pulse bursts advertising 10BASE-T-FD and parse the partner's 16-bit link code
   word. This is the only genuinely new subsystem: generate/decode the FLP
   clock+data pulse train (PIO or software), implement the negotiation state
   machine. Moderate effort; required to interoperate with an unconfigured switch.

`docs/r15-plan.md:318` already flags that real switches usually won't negotiate
with us at all today — auto-neg (path 2) is what fixes that more generally.

### 4.2 Firmware MAC mode (easy)

Gate the half-duplex policy behind a `full-duplex` feature / runtime mode that
no-ops:
- `wait_carrier_idle()` (`eth_tx.rs:237`) — transmit regardless of RX carrier.
- `csma_acquire()` (`eth_tx.rs:208`) — no backoff.
- the carrier-detect SM2 (`eth_tx.rs:149`) — no longer needed to gate TX; frees a
  state machine (keep only if you still want RX-activity stats).

**Keep** the IFG padding + TP_IDL (`eth_tx.rs:331-345`): 802.3 still mandates
≥ 9.6 µs inter-frame gap between *your own* frames even in full-duplex.

Make it a *mode*, not a deletion — the half-duplex MAC must stay for hubs / shared
segments / un-negotiated links.

---

## 5. The real ceiling: core-1 RX decode (not FD itself)

Full-duplex does **not** add RX decode load — RX cost is set by the inbound rate
regardless of duplex. TX is on a different core and cheap (FIFO writes + a
precomputed CRC). So FD lets each direction run at its *own* per-direction limit,
simultaneously:

- **TX:** near line rate (10 Mbps), as today.
- **RX:** bounded by core-1 decode reliability at full MTU — the standing limiter
  (the PIO-DPLL retro capped ~40% full-MTU; the CPU-DPLL on core 1 is the current
  approach; ≤ 2.57 ms worst-case decode IRQ; ambient decode already ~42% busy).

So the aggregate is **additive over today's "one direction at a time,"** but it is
*not* a clean 2× of line rate — the RX decode ceiling that already exists is
inherited unchanged. FD widens the pipe to "TX-at-line-rate **and**
RX-at-decode-limit at once," which is a real gain for the router's bidirectional
workload (download = RX data + TX ACKs; upload = TX data + RX ACKs).

Clock drift is **orthogonal** to duplex mode — it persists on a full-duplex link
too (`docs/clock-recovery-decoder-plan.md` §1). FD is not a workaround for the
decoder's clock-recovery requirement.

---

## 6. What full-duplex actually buys

1. **Eliminates the half-duplex collision/RTO collapse** (gotcha #10) — the
   documented dominant bidirectional-TCP limiter. No collisions in FD by
   definition, so the 596 → 45 kB/s cliff and the RTO stalls disappear. This is
   the headline win, larger in practice than raw bandwidth.
2. **Concurrent bidirectional throughput** at per-direction limits (§5) instead of
   the half-duplex alternation + CSMA/CA backoff overhead.
3. **Lower TX latency** — no carrier-sense deferral / backoff before each frame.

Not bought: a 2× line-rate ceiling (capped by RX decode), nor any fix to clock
drift or full-MTU decode reliability.

---

## 7. Forced-FD experiment spec

Prove §2 (half-duplex is policy, not a hardware wall) and quantify the gain by
forcing both ends to 10M-FD and flipping a firmware FD mode that disables
carrier-sense/CSMA. Grounded in the default-NIC build (static `192.168.37.24/24`;
`http-bulk-test` already provides the download source; `CORE1_BUSY` already
accumulates at `eth_mac.rs:342`; RX `fcs_fail` is the device-side collision proxy).
Two tiers so the core hypothesis costs near-zero new code.

### 7.0 Hypotheses

| # | Hypothesis | Pass signal |
|---|---|---|
| **H1** | Collisions are MAC-policy, not physical | FD build → host `colls` ≈ 0, device `fcs_fail` drops to no-collision floor |
| **H2** | FD removes turnaround/backoff on a single flow | FD download kB/s ≥ HD, no RTO variance |
| **H3** | FD enables concurrent bidirectional throughput | FD (down+up at once) aggregate ≫ HD aggregate |
| **H4** | The real ceiling is core-1 decode, not FD | `cpu1` saturates / `fcs_fail` climbs under sustained RX before line rate |

### 7.1 Topology & prerequisites

```
[Linux host NIC] ──RJ45 (10BASE-T)── [HR911105A] ── ISL3177E ── Pico 2 (GP13/14)
   192.168.37.x                                                  192.168.37.24
```

- **Use the NIC that the R4–R8 recipes already link at 10BASE-T.** Verify it
  advertises full: `ethtool <if> | grep -A2 "Supported link modes"` lists
  `10baseT/Full`.
- **Top risk / hard prerequisite:** many modern NICs won't go to 10M at all.
  Confirm a working 10M-FD-capable port (known-good NIC, USB-100M dongle, or a
  managed switch port set "10 full") *before writing firmware.*
- Forcing autoneg **off** can disable auto-MDIX — if link won't come up, try a
  crossover cable or `ethtool -s <if> mdix on`.

### 7.2 Firmware — Tier 1 (the MAC-mode gate; only variable under test)

`Cargo.toml [features]`:
```toml
full-duplex = []   # disables carrier-sense + CSMA/CA; ONLY safe vs a forced-10-FD
                   # peer (mismatch = worse than HD); default off → NIC binary byte-identical
```
Three gates in `src/eth_tx.rs` (transmit unconditionally in FD mode):
- `csma_acquire()` in `send_raw_frame` → `#[cfg(not(feature = "full-duplex"))]`
- `wait_carrier_idle()` in `send_udp_broadcast` → same gate
- `wait_carrier_idle()` in `send_nlp` → same gate

**Keep** NLPs (link integrity for the forced-10 link), IFG/TP_IDL padding, and the
carrier-detect SM2 (harmless; leave it to minimize diff). Total Tier-1 delta ≈ 3
one-line `cfg` gates.

### 7.3 Firmware — Tier 2 (concurrent-bidirectional measurement, gated)

Behind `full-duplex` (or an `fd-bench` sub-feature) so production stays untouched:
- **Upload sink:** TCP listener on **port 9999**, read-drains + counts into a
  `FD_SINK_RX` static, re-listens per connection — copy the wifi `serve_lan_sink`
  pattern. Needs +1 `SocketStorage` (5→6) + a `[0u8; 32*1024]` rx buffer.
- **Download source:** reuse existing `http-bulk-test` (1 MB on :80, 32 KB TX win).
- **Telemetry on the NIC heartbeat:** add `cpu1=` via
  `cycles::permille_over(CORE1_BUSY delta, elapsed_us)` + a `last_emit_us` (the
  measured-window normalization from the [Lan] fix — do **not** assume a 1 s
  window), plus `tx/rx KB/s` from the byte counters and `fcs_ok/fcs_fail`.

### 7.4 Build matrix (duplex MUST match the build)

| Run | Firmware | Host duplex | Tests |
|---|---|---|---|
| **A — HD control** | `--features http-bulk-test` | `autoneg on` (or forced 10-HD) | baseline |
| **B — FD treatment** | `--features "http-bulk-test full-duplex"` | forced 10-FD | H1, H2 |
| **C — FD bidir** (Tier 2) | B + sink | forced 10-FD | H3, H4 |

A duplex mismatch (FD firmware ↔ HD host) is garbage, not a result. **Flash
gotcha:** build the variant you flash *last* and verify the binary before each run.

### 7.5 Host setup

```bash
IF=enpXsY
sudo ip addr flush dev $IF; sudo ip addr add 192.168.37.1/24 dev $IF; sudo ip link set $IF up
# Run A (HD):  sudo ethtool -s $IF autoneg on
# Run B/C (FD): sudo ethtool -s $IF speed 10 duplex full autoneg off
ethtool $IF | grep -E "Speed|Duplex|Link"   # expect 10Mb/s, Full, Link detected: yes
```

### 7.6 Measurement

Proven `/proc/net/dev` method (gotcha-#10 work logged ~30 colls/curl in HD):
```bash
read_ctr(){ grep "$IF:" /proc/net/dev; ethtool -S $IF 2>/dev/null | grep -iE "colli|crc|abort|carrier"; }
# H2 single flow (data down + ACKs up):
read_ctr; curl -s -o /dev/null -w "down=%{speed_download}\n" http://192.168.37.24/; read_ctr
# H3 concurrent bidir (Tier 2):
curl -s -o /dev/null -w "down=%{speed_download}\n" http://192.168.37.24/ &
dd if=/dev/zero bs=64k count=512 2>/dev/null | pv -b | nc -q1 192.168.37.24 9999; wait
```
Device side (CDC): `fcs_ok`/`fcs_fail` deltas (H1, H4), `cpu1=` under load (H4).
Always cross-check device `tx/rx KB/s` against the host number (the [Lan]-fix lesson).

### 7.7 Acceptance / decision gate

- **H1 confirmed** (host colls→0, device fcs_fail→floor) ⇒ §2 proven on-wire; the
  headline result on its own.
- **H3 large** ⇒ **justifies building FLP auto-negotiation** (§4.1 path 2).
- **H3 marginal** (decode-capped per H4, or unidirectional workload) ⇒ FD stays a
  documented option; **do not** build auto-neg. Record numbers and stop.

### 7.8 Risks & gotchas

1. Host NIC can't do 10M-FD — the gating risk; verify first (§7.1).
2. Link won't come up with autoneg off — MDIX/crossover fallback.
3. Duplex mismatch — strictly pair build↔host; mismatch is garbage.
4. Production byte-drift — `full-duplex` off by default; confirm the default NIC
   binary is unchanged.
5. `fcs_fail` has two sources — collisions *and* the clock-drift full-MTU tail.
   Separate them: idle fcs_fail (drift only) vs under-contention (drift +
   collisions); FD should null only the contention delta.

**Effort:** Tier 1 ≈ ½ day (3 gates + host recipe; tests H1/H2 with no new
measurement code). Tier 2 ≈ +½ day (sink + cpu1 telemetry; tests H3/H4).

### 7.9 Results — RAN IT (2026-06-03)

Ran Tier 1 + Tier 2 on-device: `enp1s0f0` (supports `10baseT/Full`) ↔ Pico 10BT,
host duplex forced via `ethtool` to match the firmware mode each run. Builds:
`http-bulk-test [+ fd-bench] [+ full-duplex]`, SWD-flashed; download = host `curl`
of the 1 MB `/bulk`, upload = host `dd | nc … :9999` into the sink, collisions =
`/proc/net/dev` deltas, device RX from the `[Rx]`/`[Sink]` CDC lines.

**Single flow (download, ~unidirectional), per 10 MB:**

| | HD (host Half) | FD (host Full) |
|---|---|---|
| download avg (range) | 619 (341–998) | 567 (335–981) |
| host TX collisions | 5 | **0** |
| device RX `fcs_fail` | ~5–6 /s | ~2–10 /s (**unchanged**) |

**Concurrent bidirectional (download + bulk upload at once):**

| | HD (host Half) | FD (host Full) |
|---|---|---|
| download avg (range) | **434** (147–917) | **736** (204–1004) |
| host TX collisions | 8 | **0** |
| upload solo ceiling | — | ~102 KB/s (steady, `dec≈140/s`) |

**Verdict:**
- **H1 ✅ confirmed on-wire** — forcing both ends to 10-Full drove host collisions
  to **0** and carried full transfers. The board IS full-duplex-capable; HD was a
  MAC policy. §2 validated empirically.
- **H2 ❌ no single-flow gain** — 619→567 (noise). With CSMA/CA already in the HD
  build, collisions were already rare (~0.5/MB), so removing them moves nothing on
  a ~unidirectional flow.
- **H3 ✅ qualified — FD helps the *contended* case** — under concurrent up+down,
  FD download **736 vs 434 (+70 %)** with **0 vs 8** collisions: in HD the heavy
  upload collides with the download and craters it; FD avoids that (this is §6's
  predicted win, invisible to the single-flow H2). **But bounded:** the upload
  (device RX of bulk) is **RX-decode-capped at ~102 KB/s regardless of duplex** and
  stalls under concurrency in *both* modes, so FD protects the download from
  collision-collapse rather than unlocking a 2× aggregate.
- **H4 ✅✅ strongly — RX decode is THE ceiling.** Device `fcs_fail` is identical
  HD↔FD (~5/s → it's clock-drift, not collisions), and **device RX-of-bulk tops out
  ~102 KB/s — ~9× below device TX (~970)**. That TX/RX asymmetry is a notable
  standalone characterization finding (the upload path, never measured before).
  **Now characterized in `docs/rx-bulk-ceiling.md`:** cause is full-MTU FCS-fail
  (clock drift) — clean ≤512 B, cliff to ~72 % at 1472 B; not inbox/DMA/window.

**Decision (§7.7 gate): do NOT build FLP auto-negotiation now.** FD's throughput
value is real but confined to the contended / multi-client case, requires FLP
auto-neg (a real new subsystem) to be practical, and is bounded by the RX-decode
ceiling. The higher-leverage move is **fixing RX decode** (the existing CPU-DPLL
track) — it lifts the ~102 KB/s upload ceiling *and* helps every case. Keep FD
documented as a contended-case lever; the experiment harness (`full-duplex` +
`fd-bench` features) stays in-tree, off by default, for re-running later.

---

## 8. Open items / to verify

- **Schematic** — confirm the driver pair and receiver pair go to separate
  magnetics windings (§2; near-certain, not in-repo).
- **NEXT during simultaneous TX** — verify the receiver isn't desensitized by
  near-end crosstalk while driving (real magnetics handle it; confirm FCS-OK under
  a real bidirectional test in step 1 above).

---

## 9. Where it sits on the value/effort curve

**Settled by the §7.9 experiment.** The forced-FD proof-of-concept was the
high-information / low-cost move, and it ran: FD is real (H1) and helps the
contended bidirectional case (H3, +70 % download under concurrent load, zero
collisions) — but it gives nothing on single flows (H2) and is bounded by the
RX-decode ceiling (H4: device RX-of-bulk ~102 KB/s, ~9× below TX).

**Net: FD is a *secondary* lever, not the next move.** Pursuing it for throughput
would mean building FLP auto-negotiation (a real subsystem) for a win that only
materialises under concurrent/multi-client load and is still capped by RX decode.
The **primary lever is RX decode** (the existing CPU-DPLL track): it lifts the
~102 KB/s upload ceiling *and* improves every case, FD or not. Radio
modularization (§4-B) remains *not* justified (the cyw43 LAN ceiling was the gSPI
clock, since fixed). Keep the `full-duplex` + `fd-bench` experiment harness in-tree
(off by default) so FD can be revisited cheaply once RX decode is faster — at which
point FD's contended-case win would actually have headroom to matter.

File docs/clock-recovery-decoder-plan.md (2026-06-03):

# Clock-recovery decoder — design plan

Status: **Phase 0 + 1 algorithm DONE** (2026-05-27); Phase 2 = PIO-side
production implementation, planned in **`docs/pio-decoder-plan.md`**. Unblocks full-MTU RX, the #1 router-foundation
blocker found in A1. See RESUME.md "Router project — A1 link characterization"
and the `project-vision-router` memory. The offline bench lives in
`tools/clock-recovery/` (corpus + `harness.py` + `capture.py`).

**Phase 1 result:** the **edge-relative re-anchoring** algorithm (track each
per-bit Manchester transition, sample one sample before it) **fully cancels the
drift** on the corpus — every position bin flat 0%, **FCS-ok N/N** (vs the
open-loop baseline's ~0→89% tail, FCS 0/N), robust across search-window
W = 1–3. Algorithm validated; see `harness.py::decode_edge_track`.

**Phase 2 caveat (drives the CPU-vs-PIO decision):** edge-track does a small
per-bit edge search (a few extra sample reads/bit). Rough estimate: ~2–4× the
current per-bit decode cost → a full-MTU CPU decode (~12 k bits) lands around
~1.6–3.3 ms, i.e. *borderline-to-over* the 2.18 ms IRQ half-fill budget. So the
CPU port needs an on-device cost measurement, and this strongly favours
**Candidate C (PIO-side recovery)** for production — the PIO does exactly this
(`wait` for each transition, sample just before) in hardware at zero CPU cost,
which *also* fixes A1 Finding 2 (single-core load collapse). The offline-
validated algorithm maps directly onto a PIO `wait`-on-edge program.

## 1. Problem (from A1, confirmed)

`decode_frame` locks sampling phase **once** at the SFD, then reads each data
bit open-loop at a rigid stride `sample = F + 4 + 6·k` (6 samples/bit at the
60 MHz sampler). There is **no feedback**, so the unavoidable ppm mismatch
between the host's 10BASE-T bit clock and our RP2350-derived sampler makes the
sample point walk off the bit center, linearly, as the frame goes on.

Per-byte error-position test (full-MTU known pattern, 120 pps):

| frame bytes | 42–593 | 594–777 | 778–961 | 962–1145 | 1146–1329 | 1330–1513 |
|---|---|---|---|---|---|---|
| byte-error rate | **0.0%** | 2.8% | 24% | **50%** | 74% | 89% |

Perfect for ~575 B, then a clean monotonic ramp through 50% (sample point on a
bit boundary, reading randomly) to 89%. Flat would mean PHY noise; this is the
textbook clock-drift signature.

**Quantitative model.** If the true bit period is `P = 6/(1+δ)` samples (δ = ppm
offset), the open-loop error after `k` bits is `(6 − P)·k ≈ 6δ·k` samples. Half
a bit (3 samples → 50% errors) is reached at `k ≈ 3/(6δ)` bits. The observed 50%
at ~byte 1050 (≈8400 bits) ⇒ **δ ≈ 60 ppm** — squarely inside 10BASE-T's
±100 ppm spec. So this is a *normal* clock offset, not a defect: the decoder
fundamentally needs clock recovery. **Firmware-fixable; not the analog PHY, and
orthogonal to duplex mode — drift would persist on a full-duplex link too** (the
board's ISL3177E transceiver is full-duplex-*capable*; FD is a MAC/negotiation
choice, not a hardware swap, and doesn't address clock recovery — see
`docs/full-duplex-analysis.md`).

## 2. Goal & success criteria

Restore reliable full-MTU RX by continuously cancelling drift.

Primary acceptance (all measured offline first, then on-device):
- **Per-byte error bins flat** across all positions at the small-frame floor
  (drive the 778–1513 B bins from 24–89% down to ≈ the 64-B baseline).
- **Full-MTU (1518 B) FCS-ok ≥ ~95%** at low rate (today ~1.7%); ideally close
  to the 64-B figure (~98%).
- **No regression** in small-frame reliability or the gotcha-#10 on-wire stress.
- Decode cost re-measured; IRQ worst-case impact understood (see Finding 2 /
  §6 risks — the loop must stay cheap or move to PIO/2nd core).

## 3. Design principle

Replace open-loop striding with **closed-loop phase tracking** anchored to the
Manchester **mid-bit transition**, which is *guaranteed present every bit*
(every 100 ns). Re-aligning to it each bit (or filtering toward it) cancels
accumulated drift by construction. With 6× oversampling, edges are locatable to
±1 sample (±16.7 ns) — ample to keep the sample centered against ~tens-of-ns
drift accumulated over hundreds of µs.

Convention reminder (from the current decoder): `F` = first H→L = start of
HB[0]; data bit `k` value = level of the 2nd half-bit, sampled at `F + 4 + 6k`;
the mid-bit transition (HB[0]→HB[1]) is at `F + 3 + 6k`; a bit-boundary
transition at `F + 6(k+1)` appears only between equal-valued consecutive bits.
Clock recovery tracks **mid-bit** edges and must ignore/handle boundary edges.

## 4. Phase 0 — Offline bench & sample corpus  ✅ DONE (2026-05-27)

Built and committed in `tools/clock-recovery/`: temporary capture firmware
dumped full-MTU run samples over UDP; collected a corpus of full-MTU
captures (`corpus/*.bin`, payload `i&0xFF`); `harness.py` runs a candidate
decoder and scores per-byte error-position bins + FCS-ok. The current open-loop
decoder reproduces offline exactly: **0% for ~575 B, ramp to ~82–89%, FCS-ok
0/N** — the validated baseline for Phase 1. Capture firmware reverted from
`main` (re-creation documented in the tools README). Original design below.

A decoder rewrite iterated on-device is slow (flash cycle per try) and
non-reproducible (the wire varies run-to-run). Capturing real samples once and
iterating offline makes it deterministic and fast — this is the key enabler.

- **Capture mode (temp firmware):** when a full-MTU known-pattern test frame is
  detected, copy its raw active-run samples (~9 KB) into a static buffer and
  dump over UDP in sequenced ≤512-B chunks (device→host TX of small frames
  is reliable — verify during capture). Host reassembles and saves with the
  known transmitted payload.
- **Corpus:** many full-MTU frames plus a few mid/small sizes, ideally across a
  couple of power cycles / warm-up states so the ppm offset and jitter vary
  (so a tuned loop generalizes, doesn't overfit one capture).
- **Offline harness (host):** run candidate decoders over the corpus and emit
  the same per-byte error-position profile + FCS-ok, with the **current**
  algorithm as the baseline (must reproduce the ~89% tail — sanity check).
  Iterate algorithms in seconds.
- **Deliverable:** reproducible corpus + harness reproducing the A1 tail, ready
  to score improvements. Carries over to *every* candidate (CPU or PIO).
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

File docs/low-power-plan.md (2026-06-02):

# Low-power — characterization plan (roadmap E)

**Status: GATED on a power meter.** The phase goal is *characterize first* —
measure where the power actually goes before changing the always-on data path.
That needs an inline draw measurement we don't have wired yet. This doc is the
turnkey plan to execute the moment the meter is connected; **no functional code
changes land until a measurement justifies them** (the explicit "characterize
first, avoid blind optimization" decision).

`router-plan.md` §6 + §7 call low-power "a known unresolved tension": a 10BASE-T +
WiFi-AP router is fundamentally always-on and always-listening, so the big
consumers are load-bearing. The realistic aim is **reduce active draw**, not deep
sleep.

---

## 1. Goal & acceptance

**Goal:** a measured power breakdown of the running router — idle and under load —
attributing draw to the major subsystems, so we know the floor and which levers
are worth pursuing.

**Acceptance:** a filled-in version of the §4 matrix (mA at each config), a ranked
lever list backed by measured deltas, and a recommendation of which (if any) to
implement. NOT "make it use less power" yet — that's the *next* sub-phase, driven
by this data.

---

## 2. Measurement setup (the prerequisite)

The board is USB-powered today, so the low-friction path is an **inline USB power
meter** (USB-A pass-through, reads V/I/W) or a USB-PD analyzer between the host and
the Pico. Alternatives: bench PSU with current readout on VSYS, or a current-sense
resistor + DMM in series with VSYS (more precise, can isolate rails).
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

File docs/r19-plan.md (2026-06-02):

# R19 — robustness: cold-start gateway-ARP (the `[Fwd] drop≈4` fix)

**Goal:** eliminate the constant cold-start `[Fwd] drop≈4` — the handful of
forwarded LAN→WAN frames dropped at the start of a session before the WAN
neighbor table has learned the gateway's MAC.
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

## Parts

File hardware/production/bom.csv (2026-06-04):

Designator | Footprint | Quantity | Value | LCSC Part #
C5, C8, C9 | 0603 | 3 | 100nF
C6, C7 | 0603 | 2 | 10nF
J1 | PinHeader_1x02_P2.54mm_Vertical | 1 | Conn_01x02_Pin
J2, J3 | PinHeader_1x04_P2.54mm_Vertical | 2 | Conn_01x04_Pin
J6 | RJ45_Hanrun_HR911105A_Horizontal | 1 | RJ45_Hanrun_HR911105A_Horizontal
R28 | 0603 | 1 | 100R
R29, R30 | 0603 | 2 | 50R
U1 | SOIC_177EIBZ_REN | 1 | ISL3177EIBZ

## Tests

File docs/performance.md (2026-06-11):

# Performance — what to expect

Measured on real hardware. The short version: the **bit-bang 10BASE-T TX is near
line rate**, but two things shape real throughput — the link is **half-duplex**
(so single-flow TCP collides with its own ACKs and varies a lot), and **10BASE-T
RX runs ~310 KB/s at stock MTU with ~0.2% wire loss** — the former ~100 KB/s
"decode/PHY ceiling" was root-caused (2026-06-10) to DMA-starvation sample
loss plus ACK mis-pacing, and fixed; see `rx-bulk-ceiling.md` §9-§10.
Latency is excellent. This is a fun, capable, *educational* software-PHY NIC and a
working small router — not a fast router.

## TL;DR

| Path | Direction | Throughput | Notes |
|---|---|---|---|
| **10BASE-T** (wired, the bit-bang) | TX, device→host (TCP) | **best ~0.95–1.0 MB/s**, typical single-flow ~0.4–0.7 MB/s | near line rate when clean; half-duplex collision variance + occasional RTO stalls |
| **10BASE-T** | RX, host→device (TCP bulk) | **~310 KB/s** | stock MTU, ~0.2% wire loss; immediate-ACK + 2-seg window + decode-out-of-IRQ (`rx-bulk-ceiling.md` §9-§10) |
| **10BASE-T** | round-trip latency | **~2.6 ms** (0% loss) | ping, 30/30 |
| **Wi-Fi LAN** (cyw43 AP, router build) | download (device→client) | **~909 KB/s** | after the gSPI 2→15 MHz fix |
| **Wi-Fi LAN** (cyw43 AP) | upload (client→device) | **~716 KB/s** | |
| **Routed LAN↔WAN** (NAPT) | bidirectional | bounded by the 10BT half-duplex link (TX ~1 MB/s, RX ~310 KB/s) | not the wire or CPU; see §Router |
| **CPU** | core 1 (RX decode) | **~40 %** at idle | cost of the always-on 60 MHz sampler decoding ambient wire traffic |

Line rate for reference: 10 Mbit/s ≈ 1.25 MB/s raw, ≈ 1.18 MB/s of TCP payload.

## Test setup (and how to reproduce)

- **Board:** Raspberry Pi Pico 2 W (RP2350, Hazard3 RISC-V), `clk_sys` 240 MHz.
- **10BASE-T front end:** ISL3177E transceiver + HR911105A RJ45 magnetics
  (GP14 = DI/TX, GP13 = RO/RX). See the README wiring table.
- **Wired peer:** a Linux host NIC linked at 10BASE-T (`enp1s0f0`), forced to
  10 Mb/s half-duplex; device static `192.168.37.24`.
- **Builds:** the wired numbers use `--features "http-bulk-test fd-bench diag"`
  (adds a 1 MB HTTP source on :80, a TCP sink on :9999, and the `[Rx]` decode
  stats over USB CDC). The Wi-Fi/router numbers use `--features router`.
- **Tools:** `tools/` (the measurement scripts) + the device's USB-CDC telemetry
  (`[R2b]`/`[Rx]`/`[Sink]`/`[Perf]` lines; assert DTR to read them).

## Detail

### 10BASE-T TX (device → host) — fast PHY, half-duplex-limited
The Manchester bit-bang TX runs at the full 10 Mbit/s line clock, so a *clean* 1 MB
HTTP download lands at **~0.95–1.0 MB/s** (near the ~1.18 MB/s payload ceiling).
But the link is **half-duplex** with a CSMA/CA (not CSMA/CD) MAC: the device's data
segments collide with the peer's TCP ACKs, so single-flow TCP throughput is
**bimodal** — clean transfers ~0.94–1.0 MB/s, collision-stalled ones ~0.25–0.5 MB/s,
and the occasional RTO storm times out entirely. Typical single-flow average lands
~0.4–0.7 MB/s. (Carrier-sense + randomized backoff keep this from collapsing the way
naive multicore TX did — see `docs/cpu-dpll-plan.md` gotcha #10.)

### 10BASE-T RX (host → device) — ~310 KB/s after the 2026-06 fixes
Sustained bulk RX runs **~310 KB/s at stock MTU 1500 with ~0.2% wire loss**
(was ~100 KB/s at ~30% full-MTU FCS-fail). Two rounds of fixes, both in
`rx-bulk-ceiling.md`:
- **§9 — ACK pacing + window:** the 10 ms delayed-ACK timer sat exactly on
  Linux's tail-loss-probe timer (collision storm), and the 1-segment
  advertised window serialized the link. Immediate ACKs + a 2-segment window.
- **§10 — the "decode cliff" was DMA starvation, not clock drift:** decode ran
  in the DMA IRQ in front of the re-arm; under load it overran the half-fill
  period and the PIO RX FIFO overflowed (~200×/s), silently truncating frames.
  Decode now runs in core-1 thread context from a 6-slot image ring; the IRQ
  only captures + re-arms in bounded time. Health counters: `rxstall` (must
  stay 0) and `img_drop` (decode backlog) on the diag `[Stitch]` line.

Remaining bounds: decode CPU time (~1-1.5 ms/frame) and the ~2.2 ms DMA
half-fill ACK-latency floor (smaller halves are viable again now that the
decode deadline coupling is gone).
### Latency — excellent
`ping` over the wired link: **min/avg/max 2.1 / 2.6 / 3.0 ms, 0 % loss** (30 pkts).

### Wi-Fi LAN (cyw43 AP, router build)
After raising the custom PIO gSPI transport clock from the 2 MHz bring-up value to
15 MHz, the cyw43 2.4 GHz AP does **~909 KB/s down / ~716 KB/s up** — on par with the
wired NIC, no longer the router bottleneck (the radio was never the limit; the
bring-up SPI clock was). See `docs/perf-characterization-plan.md` §3.5.

### Router (LAN ↔ WAN, NAPT)
The full routed/NAT path (Wi-Fi client ↔ Pico ↔ 10BT WAN) is **not** CPU- or
forwarding-limited (core-0 forwarding fast-path is ~idle, drops ~0). It's bounded by
the **slower link and half-duplex contention** on the 10BT side —
i.e. the per-link ceilings above, with the 10BT RX path bounding any
WAN→LAN-heavy (download) flow. Best for low-rate / IoT-scale traffic.

### CPU
Core 1 owns the RX decode (the `DMA_IRQ_0` Manchester + FCS pipeline). It sits at
**~40 % even at idle**, just decoding ambient 10BASE-T wire traffic — the cost of the
always-on 60 MHz sampler + per-DMA-half wake. Core 0 (the executor / forwarding) is
near-idle without load.

## Honest limitations

- **RX bulk ~310 KB/s** — next bounds are decode CPU time and the DMA
  half-fill latency floor; see `docs/rx-bulk-ceiling.md` §10.
- **Half-duplex only** by MAC policy. The transceiver is *full-duplex-capable*, but
  FD only helps contended/multi-client traffic (measured before the 2026-06 RX
  fixes — worth re-testing against the now-clean link); not
  worth the auto-negotiation work — see `docs/full-duplex-analysis.md`.
- **No auto-negotiation** — emits link pulses (NLPs) only; a switch parallel-detects
  it as 10BASE-T half-duplex (which is what we want).
- **Sustained full-MTU inbound can wedge the device** (intermittent). An RP2350
  **hardware watchdog** auto-reboots + recovers it (~6 s); root-cause is still open.
- Educational / hobby project. Great for learning software PHYs and as a slow but
  real 10BASE-T NIC / small router; not a production-grade fast router.

## See also (the engineering log)
`docs/rx-bulk-ceiling.md` (RX ceiling), `docs/full-duplex-analysis.md` (FD),
`docs/cpu-dpll-plan.md` + `docs/clock-recovery-decoder-plan.md` (the RX decoder),
`docs/perf-characterization-plan.md` (cyw43 LAN + routed), `docs/router-plan.md`
(router architecture).

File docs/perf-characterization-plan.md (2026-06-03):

# Performance characterization (+ the post-router backlog)

The router is feature-complete + robust through R19a. Low-power (roadmap E) is
**scoped but backburnered** (`docs/low-power-plan.md`, gated on a power meter).
The active track is now **characterizing the router's performance** — and the
expanded backlog of post-router directions is captured at the end of this doc.

---

## 1. Goal

Measure the **full routed / NAT'd path** — WiFi client → Pico NAPT → 10BASE-T
WAN — which has **never been measured**. The R11/R12 numbers (596–987 kB/s) were
the 10BT NIC *in isolation*, not transit through the AP + NAPT.

The headline question: **where is the routed-throughput ceiling?** — the cyw43
2.4 GHz 11n radio, the 10BT WAN, a saturated Hazard3 core, or conntrack. That
answer decides whether the **radio-modularization** work (below) is worth it: the
user's motivation for it is *higher throughput*, so it only pays off if
measurement shows the cyw43 radio is actually the bottleneck.

---

## 2. Instrumentation — the prerequisite (build before measuring)

### Step 1 — data-plane counters ✅ DONE (`0285e31`, on `main`, flashed)
`src/forward.rs`:
- per-direction egressed bytes (`FWD_BYTES_TO_WAN`/`_TO_LAN`) → throughput
- `FWD_DROP` split by cause (`count_drop` helper): `qfull` / `nonh` / `nat` /
  `txbusy` / `other` — so load tests show *why* it drops
- per-direction egress-queue high-water (`FWD_QHWM_L2W`/`_W2L`, vs `CHAN_DEPTH=4`)

Surfaced as: a 1 Hz `[Perf]` CDC line in `usb_task` (per-second up/dn KB/s, pps,
queue/conntrack high-water, drop breakdown) **and** the mgmt page
(`serve_status_http` — byte totals, drop breakdown, queue hwm; body cap bumped to
`POOL_LEN*40+512`, `http_tx` 2048→2560). The mgmt page is the reliable readout (the
5th CDC line adds interleaving pressure).

On-device: `[Perf]` renders, all counters read sanely at idle (0). **Real numbers
need traffic** (the harness, §3).

### Step 2 — `mcycle` CPU utilization ✅ DONE (code complete, builds clean; on-device idle-validation pending a flash)
New `src/cycles.rs` (router-only): `mcycle()` (CSR `0xB00`), `enable_mcycle()`
(clears `mcountinhibit` CSR `0x320` — called per-core: core 0 in `main`'s router
arm, core 1 at the top of `core1_entry`), and a `CycleSpan` RAII guard that
brackets a scope and adds its `mcycle` delta (wrap-safe) to an accumulator.
- **core 1**: a `CycleSpan` around `process_completed_half` in the `DMA_IRQ_0`
  handler (`eth_mac.rs`) → `CORE1_BUSY` ≈ core-1 RX-decode utilization.
- **core 0**: a `CycleSpan` at the top of `ForwardingDevice::receive` (classify/
  skim) and `egress` (NAPT/TTL/L2-rewrite) in `forward.rs` → `FWD_BUSY` = the
  *fraction of core-0 wall-clock spent forwarding* (NOT total core-0 load — the
  executor/smoltcp/cyw43-SPI cost is outside the brackets; that's the
  "cycles/sec in the routing path" number `router-plan.md` §8.3 wants).

`usb_task` samples both accumulators once a second, divides each delta by
`SYS_CLK_HZ` (240 MHz, or 150 with `clock-150mhz`), and publishes per-mille into
`CPU1_PERMILLE`/`CPU0_PERMILLE` — surfaced as `cpu1=NN.N% cpu0=NN.N%` on the
`[Perf]` CDC line **and** a `CPU:` row on the mgmt page (the reliable readout).
Instrumentation is router-gated, so the production NIC build's hot path is
byte-unchanged. No external hardware needed (unlike low-power).

**Caveat for validation:** at idle, busy-cycles ≈ 0 *regardless* of whether the
counter is enabled — so an idle read only confirms the fields render + read sane.
Confirming the counters actually move (and the numbers mean something) needs
traffic, i.e. the §3 run. Low 32 bits wrap ~18 s at 240 MHz / ~28 s at 150 MHz →
always `wrapping_sub` deltas.

---

## 3. The measurement run (gated on the rig)

Needs: `tools/wan-test-host.sh` up (Pico holds a WAN lease); `iperf3` is already
installed. The rig is split **route-1 style** so the recurring measurement needs
no root (shared config in `tools/rig-env.sh`):
- **`sudo tools/router-rig-up.sh`** — *one-time root*: associate this host's Wi-Fi
  client to the Pico AP, lease an IP, install the `/32` route to `$SRV` via the
  Pico (route-safe — never touches the eno1 default / SSH). Leaves it associated +
  writes the client IP to `/tmp/pico-rig.env`.
- **`tools/router-measure.sh`** — *NO root, repeatable* (Claude can drive this):
  iperf3 server + client over the routed/NAT'd path (TCP down/up + UDP) + before/
  after mgmt-page snaps (`Forward|Bytes|Queue|NAT:|CPU:`).
- **`sudo tools/router-rig-down.sh`** — *root*: remove the route + deassociate.

`tools/router-throughput.sh` remains an all-as-root convenience wrapper
(rig-up → measure → rig-down). Untested end-to-end until the first live run —
refine then.

Record, idle vs under each load:
- routed **TCP** up (client→WAN) + down (WAN→client) kB/s
- **UDP** pps + loss knee (raise `-b` until loss climbs) → the pps ceiling
- the `[Perf]` counters: queue hwm (backpressure?), drop breakdown (where), ct hwm
- **CPU util** (step 2): which core, if any, pins at 100%

Cross-check against the in-isolation 10BT ceiling (~1 MB/s idle) and the cyw43
2.4 GHz practical ceiling. **Deliverable:** a table + a named bottleneck + a
recommendation (does the radio swap help? is core 0 saturated → rebalance? is it
the 10BT half-duplex? conntrack?).

Then multi-client (the user's #3): N clients associated, measure aggregate +
per-client fairness, conntrack pressure (`cthwm` vs `CT_CAP=64`), AP stability.

---

## 3.5 — Isolating the cyw43 LAN link (NEXT — the first routed run pointed here)

**First routed run, 2026-06-03** (rig = this host as Wi-Fi client `wlx` + WAN
gateway `enp1s0f0`, iperf3 server on a separate `192.168.0.80` via `eno1`):

- A **rig routing loop** had to be fixed first — the `/32 SRV-via-Pico` route
  (for the client) also caught the packets this host *forwards as the gateway*
  (the Pico's NAT'd frames), bouncing them back to the Pico to be re-NAT'd in a
  loop (this one host is both client AND gateway). Fixed with **source policy
  routing** (`ip rule from $LEASE_IP lookup 100`) in the rig scripts. See
  `perf-char-step3-rig-loop` memory. The forwarding code is byte-identical to the
  validated R19a — it was never the bug.
- Post-fix the routed path works: ICMP 4/4, clean TCP handshake, `[Nat] out≈in`.
  **Routed TCP upload ≈ 349 Kbit/s (~44 KB/s)**, lossy (SACK recovery, ~13
  retr/3s). **TCP download (WAN→LAN bulk) stalls and *wedged* the cyw43 LAN**
  (client lost the AP; the Pico stayed up `ap=1 net=1`, no panic) — a separate
  robustness item.
- **Key: the Pico was nearly idle** — `core0(forward)=0.2%`, `core1≈34%` (the
  ambient-10BT-decode baseline), forward drops negligible during the clean run
  (`nh +3 qf +1`; the large `nh`/`macmiss=192.168.4.1` was stale loop-era
  residue). So the ~13× gap vs the bare-10BT 596–987 kB/s is **NOT** the Hazard3
  cores or the NAPT/forward path. The loss is in the **cyw43 Wi-Fi LAN or the
  10BT WAN link**, uncounted by `FWD_DROP`.

**Why isolate the LAN:** the routed path conflates LAN(wifi)+forward+WAN(10BT);
the 10BT alone does 596–987 kB/s, so the prime suspect is the cyw43 RX/TX path.
44 KB/s is *suspiciously* low for 2.4 GHz 11n — must distinguish "cyw43's real
ceiling" from "a loss/buffering bug under burst." **The LAN-only rig is far
simpler than §3:** no WAN host, no `$SRV`, no `/32`, no NAPT — just `wlx` ↔ the
Pico AP, traffic terminating *on the Pico* (none of the loop/double-NAT fragility).

**Instrumentation — BUILT 2026-06-03** (compiles all 4 configs + clippy clean,
only the 2 pre-existing warnings; production NIC build byte-unchanged — the new
code lives only in the `wireless`/`router` modules; the per-core CPU% (step 4) is
router-gated since it uses the router-only `cycles`). New readouts: a **`[Lan]`
CDC line** (`tx=KB/s rx=KB/s txbusy=N rxframes=N` + router `spi0=% net0=%`) and
mgmt-page rows (`LAN perf:` totals + `LAN cpu0:` split). **The device must be
reflashed with this router build** before the rig run (it's the current
`release/` ELF; the [[flash-wrong-feature-build-gotcha]] verify = `strings <ELF> |
grep -F "[Lan]"`).
1. **LAN bulk *source*** (download = Pico→client, cyw43 TX) — DONE: a `GET /bulk`
   route in `wireless::serve_status_http` streams `LAN_BULK_BYTES` (8 MB) of 0x55
   filler via a persistent `LanHttp::Bulk{remaining, header_sent}` state (mirrors
   `main.rs`'s `serve_http_bulk`). The `:80` TX buffer was bumped 2.5→32 KB so the
   stream stays cyw43-TX-limited, not net_task-5ms-cadence-limited (32 KB/5 ms ≈
   6.4 MB/s ceiling). Counts `LAN_BULK_TX_BYTES`. Drive:
   `curl http://192.168.4.1/bulk >/dev/null` and read the steady-state `[Lan] tx=`
   (Ctrl-C once it settles — 8 MB needn't finish).
2. **LAN *sink*** (upload = client→Pico, cyw43 RX) — DONE: a TCP listener on
   **port 9999** in `net_task` (`serve_lan_sink`) read-drains + counts every byte
   (no echo) into `LAN_SINK_RX_BYTES`, re-listening per connection. 32 KB RX
   buffer so the advertised window doesn't throttle. Drive (iperf3-free):
   `head -c 64M /dev/zero | nc 192.168.4.1 9999` and read `[Lan] rx=`.
3. **cyw43 TX-backpressure counter** — DONE (`CYW43_TX_BUSY` in `src/cyw43_phy.rs`,
   incremented on `transmit()→None`). ⚠️ **Reframed after reading the cyw43
   source:** there is **no observable RX-drop counter**. `Cyw43Phy::receive()→None`
   is dominated by *idle polls* (the cyw43 `NetDriver::receive` returns `None`
   whenever no RX frame is ready — hundreds/sec — and *also* when the TX half is
   full; it can't be decomposed at the `phy` boundary), so counting it would be
   noise, not drops. The *real* cyw43 RX drop happens **inside** cyw43's `Runner`
   (`runner.rs`: `try_rx_buf()→None ⇒ silently drop + a defmt warn!` we don't
   capture) — upstream of us, uncounted. So `transmit()→None` is the one genuine
   TX-backpressure signal (high under `/bulk` ⇒ cyw43 TX is the wall), and the
   **RX-side discriminator is sink-throughput-vs-`spi0`/`net0`** (step 4), not a
   device counter: low sink kB/s + low core-0 ⇒ the air/radio; low sink kB/s +
   pinned core 0 ⇒ we can't drain fast enough and cyw43 drops upstream. (This
   replaces the "high RX-drop counter ⇒ buffering bug" matrix row with a
   throughput+CPU read — same decision, different evidence.)
4. **CPU during LAN-only load** — DONE: two router-gated `CycleSpan`s on core 0,
   since step-2 `FWD_BUSY` only brackets forwarding (≈0 here). `CYW43_SPI_BUSY`
   wraps the busy-poll gSPI transport (`PioSpiCyw43::cmd_read`/`cmd_write`, the
   cyw43 Runner's real cost) → `spi0%`; `LAN_NET_BUSY` wraps `net_task`'s per-poll
   body (smoltcp + handlers + `Cyw43Phy` channel ops) → `net0%`. `spi0+net0` ≈
   core-0 utilisation under a LAN test; `spi0` high ⇒ the busy-poll transport is
   CPU-bound (matrix row 3 → gSPI DMA, §4-G).

**LAN-isolation run — RESULTS (2026-06-03, `--features router`, SWD-flashed; host
`wlx` joined the AP, source-bound to the lease IP `192.168.4.10` so traffic takes
table-100 → `wlx`, i.e. the cyw43 LAN, NOT the 10BT WAN):**

| Direction | Throughput (client-measured) | core-0 `spi0` | `net0` | `cpu1` | notes |
|---|---|---|---|---|---|
| **idle** (no traffic) | — | **80–98%** | ~0.4% | ~40% (ambient 10BT) | `spi0` pegged *with zero traffic* |
| **download** (`/bulk`, cyw43 **TX**) | **~168 KB/s** | ~90–95% | ~2% | ~40% | `txbusy` climbing (real TX backpressure) |
| **upload** (`:9999` sink, cyw43 **RX**) | **~30 KB/s** | ~90% | ~1% | ~40% | `txbusy` frozen (RX-heavy; Pico only ACKs) |

**Verdict — the ceiling is our gSPI TRANSPORT, not the 2.4 GHz radio (matrix row
3 → §4-G, NOT radio modularization §4-B):**
- **`spi0`≈80–98% even at idle** — the cyw43 `Runner` *active-polls* the chip over
  gSPI continuously (its `wait_for_event` uses the default poll impl; the
  host-wake IRQ line is **not wired** — see `PioSpiCyw43`). Core 0 is near-pegged
  by the transport before any data moves.
- **The gSPI clock is ~2 MHz** (`build_gspi_sm`, "slow + safe for bring-up", never
  raised; embassy's `cyw43-pio` runs ~33 MHz). 2 MHz half-duplex = **~250 KB/s raw
  bus ceiling** — and download (168 KB/s) sits right under it. The radio was never
  the limiter; the bus was.
- **Asymmetry (TX 168 ≫ RX 30):** inbound frames wait for the active-poll cycle to
  notice them (no host-wake IRQ ⇒ RX latency), and each TCP ACK is a half-duplex
  gSPI write stealing from reads. Both point back at the transport.
- **Measurement-bug found + fixed mid-run:** the 1 Hz telemetry assumed each
  `n%1000` window = 1.000 s, but core-0 saturation slips `usb_task`'s cadence, so
  the first run over-read (`spi0=607%`, `cpu1=249%`, `tx=1137KB/s`). Fixed by
  normalising every rate/% to the **measured** elapsed µs (`cycles::permille_over`);
  re-run device `tx=174KB/s` now agrees with client `168KB/s`. (Also fixes the
  pre-existing step-2 `cpu1/cpu0` under load.)

**▶ The actionable lever is §4-G transport work, in priority order:** (1) **raise
the gSPI clock** 2 MHz → toward ~33 MHz (≈16×, the single biggest win — lifts the
raw ceiling), (2) **wire the cyw43 host-wake IRQ** so the Runner stops active-polling
(frees core 0 + cuts RX latency), (3) **gSPI DMA** (offload the busy-poll). Radio
modularization (§4-B) is **NOT** justified by this data — the air was never reached.

**gSPI clock bump — CONFIRMED 2026-06-03** (`build_gspi_sm` `GSPI_PIO_HZ`
4 MHz → 30 MHz, i.e. gSPI **2 → 15 MHz**, ÷8 at 240 MHz; cyw43 handshake still
passes — `new=1 init=1 ap=1 net=1`, WAN/ping healthy, no instability):

| Direction | 2 MHz gSPI | **15 MHz gSPI** | gain |
|---|---|---|---|
| download (cyw43 TX) | 168 KB/s | **909 KB/s** | **5.4×** |
| upload (cyw43 RX) | 30 KB/s | **716 KB/s** | **24×** |
| idle `spi0` | ~90% | ~72% | — |

Both directions now ~700–900 KB/s — on par with the bare 10BT NIC (596–987 KB/s)
and within the WAN's ~1.1 MB/s envelope, so **the cyw43 LAN is no longer the router
bottleneck.** Proof-positive that the *transport clock* (not the radio) was the
ceiling. Headroom remains: 15 MHz raw = 1.875 MB/s, so we're at ~48% (TX) / ~38%
(RX) of raw — the rest is the active-polling overhead + half-duplex ACKs. Next
levers: push gSPI → 30 MHz (÷4, optional — already beats the WAN), then **wire the
host-wake IRQ** to reclaim the idle `spi0`≈72% (the Runner still active-polls — a
core-0 + low-power win, no longer throughput-limiting). Uncommitted working tree.

**Independent baseline (would further rule out the `wlx` adapter / air):** iperf3
the host's `wlx` against a *known-good* AP (a normal router, same channel/distance).
Not yet run — but the idle `spi0`≈90% + the 2 MHz bus ceiling already pin the limit
on the transport regardless, so this is now confirmatory, not load-bearing.

**Decision matrix (the radio-modularization gate, §4-B):**

| Isolated LAN result | Interpretation | Action |
|---|---|---|
| ≫ 44 KB/s (multi-Mbit), low txbusy | routed slowness is the LAN↔WAN *interaction* (10BT half-duplex backpressure / MSS), not the radio | don't swap the radio; chase the interaction (MSS clamp §4-E, core balance §4-G) |
| download (`/bulk`) ≈ low, **high `txbusy`**, core 0 not pinned | cyw43 *TX* buffering/backpressure is the wall | software fix (bigger TX queue / gSPI DMA §4-G) before any hardware |
| up/down ≈ low, low txbusy, **core 0 pinned (`spi0`/`net0` high)** | the busy-poll cyw43 SPI transport is CPU-bound (can't drain fast enough → cyw43 drops RX upstream) | gSPI DMA (§4-G) / core rebalance |
| up/down ≈ low, low txbusy, **core 0 idle**, ≈ the wlx-vs-good-AP ceiling too | the 2.4 GHz radio / air link is the real ceiling | **radio modularization (§4-B) is justified** |

**Also characterize the download-wedge** (WAN→LAN bulk stalled + dropped the AP):
cyw43 TX backpressure (the `transmit()`→`None` ⇒ drop-the-RX-frame path in
`forward.rs::receive`), the `WAN_TO_LAN` channel (depth 4) saturating, or the AP
dropping the client under load? The LAN bulk *source* test (#1) exercises cyw43 TX
in isolation — if it also stalls/wedges, the TX path is implicated, not the WAN.

---

## 4. Broader backlog (brainstorm 2026-06-02, with decisions)

The user's three + additions. Decisions captured: **radio-modular is
throughput-motivated**; **start instrumentation-first** (this track).

**A. Performance characterization (#1 + #3)** — THIS track. Single-client
(throughput/latency/pps/CPU) then multi-client (fairness/scaling/conntrack).

**B. Radio/AP modularization (#2) — throughput-motivated.** A `WirelessLan` trait
(init / start_ap / address / `phy::Device`) decoupling `net_task` + the router from
cyw43, so a faster module can drop in (the transport `SpiBusCyw43` is already
abstracted; this is the layer above). **Only worth building if §3 shows the cyw43
2.4 GHz 11n radio is the ceiling.** Candidate replacements: SDIO/ESP32-C6 (WiFi 6),
5 GHz modules. Sequence *after* characterization confirms the need.

**C. Observability** (enabler, overlaps step 2): per-core CPU%, a `/metrics`
endpoint, the routed-throughput harness (started, `tools/router-throughput.sh`).

**D. Make it a real product:** mgmt UI as a control plane (the HTTP server ignores
the request line today — add routing `/stats` `/clients` `/conntrack` + actions:
kick client, clear conntrack, change AP config); config persistence in flash (SSID/
passphrase/channel + leases survive reboot; today hardcoded consts + RAM-only pool);
security hardening (mgmt page is unauthenticated + LAN-open, dev creds in source,
NAT wide open).

**E. NAT / protocol correctness** (can bite under real traffic): TCP MSS clamping
(half-duplex 10BT + large-frame tail makes full-MSS fragile — R17.x); ICMP-error
embedded-header rewriting (R17 punted → breaks PMTUD/traceroute); a real DNS relay
(vs today's NAT-passthrough → enables logging/filtering/caching).

**F. Reliability:** WAN link-loss / lease-loss recovery (a dead upstream just
stalls today); RP2350 hardware watchdog; backpressure / conntrack-pressure
(R19+); the optional ARP hold-and-retry for a true worst-case-0 (R19a deferral).

**G. Architecture / perf** (falls out of §3): core-balance rebalance (move the
forwarding fast-path or cyw43 Runner to core 1 if core 0 saturates); gSPI DMA
(replace the busy-poll cyw43 transport — cuts core-0 load + a low-power win).

**Dependency spine:** instrumentation → characterize (single → multi-client) → the
revealed bottleneck drives the next move (core rebalance / gSPI DMA / radio swap /
conntrack-pressure). The "real product" track (D) is independent + parallelizable.

---

## 5. Status / restart pointer

- **Step 1 instrumentation: DONE** (`0285e31`), flashed, idle-validated.
- **Step 2 (`mcycle` CPU util): DONE** (on `main`), all 4 configs/clippy
  clean, SWD-flashed + idle-validated (fields render; `cpu1≈42% cpu0≈0.3%` at idle —
  core 1 already busy decoding ambient 10BT, see the surprise finding above). The
  counters can only be *meaningfully* exercised under load (§3).
- **Step 3 (first routed run): DONE 2026-06-03** — fixed the rig loop (source
  policy routing, in the committed rig scripts), got the routed path working, and
  took the first numbers (§3.5). Headline: **routed TCP up ≈ 44 KB/s, Pico CPU
  idle (`core0=0.2%`) ⇒ link-limited, not CPU/forward-limited.** The bottleneck is
  the cyw43 LAN or the 10BT link.
- **Step 4 — LAN-isolation instrumentation: BUILT + RUN 2026-06-03** (uncommitted
  working tree). `/bulk` source + `:9999` sink + `CYW43_TX_BUSY` + `spi0`/`net0`
  core-0 spans → a `[Lan]` CDC line + mgmt rows; all 4 configs + clippy clean.
  **Flashed + measured** (§3.5 results table): download **168 KB/s**, upload **30
  KB/s**, core-0 `spi0`≈90% (even ~90% at idle). **Verdict: the ceiling is the
  ~2 MHz busy-poll gSPI transport, NOT the radio** → §4-G (raise gSPI clock / wire
  host-wake IRQ / gSPI DMA), **not** radio modularization §4-B. Also fixed a
  rate-normalisation bug (1 Hz window stretches under core-0 load → over-read;
  now normalised to measured µs via `cycles::permille_over`).
- **gSPI clock bump — DONE + CONFIRMED 2026-06-03** (`GSPI_PIO_HZ` 4→30 MHz =
  gSPI 2→15 MHz): download **168→909 KB/s** (5.4×), upload **30→716 KB/s** (24×);
  handshake/WAN/ping all healthy. The cyw43 LAN is no longer the router bottleneck
  (now ~on par with the bare 10BT NIC). See the §3.5 results table.
- **▶ NEXT:** (a) optional — push gSPI 15→30 MHz (÷4) for more headroom (already
  beats the WAN, so low urgency); (b) **wire the cyw43 host-wake IRQ** so the
  Runner stops active-polling — idle `spi0` is still ~72% (wasted core 0 + a
  low-power cost), no longer throughput-limiting; (c) commit the LAN-isolation
  instrumentation + the gSPI bump + the rate-normalisation fix (held for the
  user). Optional confirmatory: iperf3 `wlx` vs a known-good AP — not load-bearing.
- **Push held at the user's request.** Per git, local `main` is 2 ahead of
  `origin/main` (`1d1a1a1`): `a58d51f` (instr step 2) + the rig-split tooling
  (this). The older "`b32042d`/`0285e31` unpushed" note looks stale — `origin/main`
  already contains both (confirm with `git fetch`).

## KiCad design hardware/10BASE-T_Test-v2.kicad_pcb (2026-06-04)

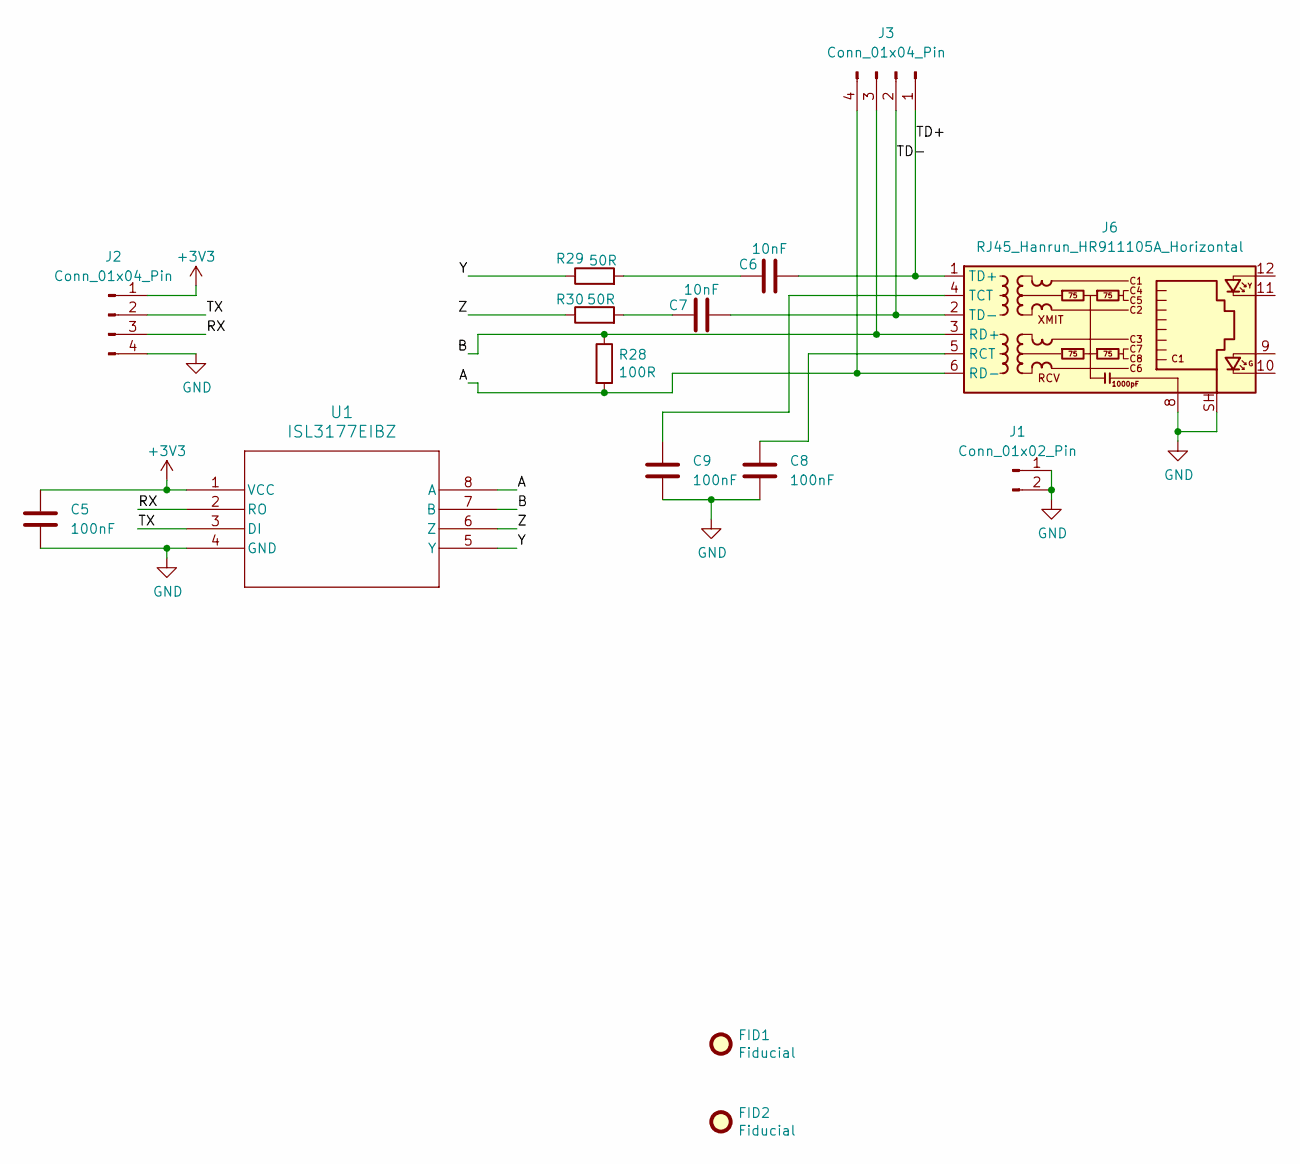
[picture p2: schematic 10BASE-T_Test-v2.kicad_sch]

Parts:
C5, C8, C9: 100nF; C_0603_1608Metric
C6, C7: 10nF; C_0603_1608Metric
FID1, FID2: Fiducial; Fiducial_1mm_Mask2mm
J1: Conn_01x02_Pin; PinHeader_1x02_P2.54mm_Vertical
J2, J3: Conn_01x04_Pin; PinHeader_1x04_P2.54mm_Vertical
J6: RJ45_Hanrun_HR911105A_Horizontal
R28: 100R; R_0603_1608Metric
R29, R30: 50R; R_0603_1608Metric
U1: ISL3177EIBZ; SOIC_177EIBZ_REN

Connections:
+3V3: C5.1, J2.1, U1.1 (VCC)
/A: J3.4, J6.6 (RD-), R28.2, U1.8 (A)
/B: J3.3, J6.3 (RD+), R28.1, U1.7 (B)
/RX: J2.3, U1.2 (RO)
/TD+: C6.2, J3.1, J6.1 (TD+)
/TD-: C7.2, J3.2, J6.2 (TD-)
/TX: J2.2, U1.3 (DI)
/Y: R29.1, U1.5 (Y)
/Z: R30.1, U1.6 (Z)
GND: C5.2, C8.2, C9.2, J1.1, J1.2, J2.4, J6.8, J6.SH, U1.4 (GND)
unnamed: C6.1, R29.2
unnamed: C7.1, R30.2
unnamed: C8.1, J6.5 (RCT)
unnamed: C9.1, J6.4 (TCT)

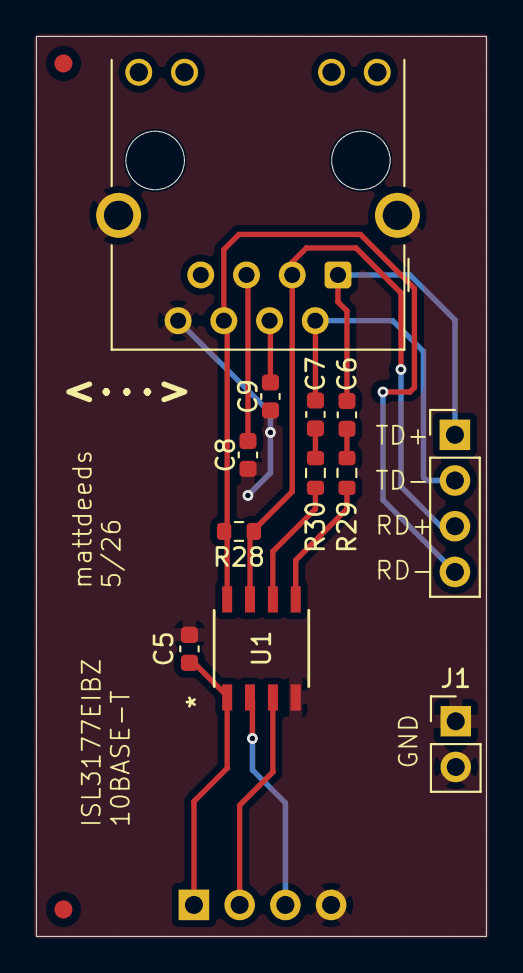
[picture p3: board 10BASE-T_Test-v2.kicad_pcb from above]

Board: 2 copper layers, 25.0 x 50.0 mm, 15 parts (1 on the bottom side), 14 nets.

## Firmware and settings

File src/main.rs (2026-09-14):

//! Pico-10BASE-T firmware: 10BASE-T NIC, wireless AP, or router.
//!
//! Default build: software 10BASE-T NIC with smoltcp (ARP, ICMP, UDP echo,
//! HTTP) and USB CDC logs. `wireless` and `router` hand core 0 to embassy.
//! C reference: `../Pico-10BASE-T/`.

#![no_std]
#![no_main]
// `wireless` builds (router included) leave 10BT code unused; allow it.
#![cfg_attr(
    feature = "wireless",
    allow(dead_code, unused_variables, unused_mut, unused_imports)
)]

// Transport modules come from the library crate.
use pico_10base_t_rs::{eth_mac, eth_rx, eth_tx, multicore_riscv, pico_reset};
// `pio_util` is used by `wireless` for the gSPI divider.
#[cfg(feature = "wireless")]
use pico_10base_t_rs::{cyw43_phy, pio_util};
// Per-core CPU counters (router only).
#[cfg(feature = "router")]
use pico_10base_t_rs::cycles;
// cyw43 LAN: gSPI transport, executor, and tasks.
#[cfg(feature = "wireless")]
mod wireless;
// LAN DHCP server.
#[cfg(feature = "wireless")]
mod dhcp_server;
// WAN DHCP client, ping, and DNS.
#[cfg(any(feature = "wan-dhcp", feature = "router"))]
mod wan;
// L3 forwarding and NAPT device (router only).
#[cfg(feature = "router")]
mod forward;
// NAPT conntrack table (router only).
#[cfg(feature = "router")]
mod conntrack;

use panic_halt as _;

use core::fmt::Write;
use core::sync::atomic::{AtomicU32, Ordering};
use embedded_hal::digital::OutputPin;
use heapless::String;
use rp235x_hal as hal;
use hal::dma::DMAExt;
use hal::fugit::{HertzU32, RateExtU32};
use hal::gpio::FunctionPio0;
use hal::pio::PIOExt;
use hal::singleton;
use hal::Clock; // brings .freq() into scope
use hal::pll::{setup_pll_blocking, common_configs::PLL_USB_48MHZ, PLLConfig};
#[cfg(feature = "clock-150mhz")]
use hal::pll::common_configs::PLL_SYS_150MHZ;
use hal::xosc::setup_xosc_blocking;
use hal::clocks::ClocksManager;
use smoltcp::iface::{Config, Interface, SocketHandle, SocketSet, SocketStorage};
use smoltcp::socket::{tcp, udp};
use smoltcp::time::Instant;
use smoltcp::wire::{EthernetAddress, HardwareAddress};
// Static IP types, used only without `wan-dhcp`.
#[cfg(not(feature = "wan-dhcp"))]
use smoltcp::wire::{IpAddress, IpCidr, Ipv4Address};
// WAN DHCP client sockets (`wan-dhcp`).
#[cfg(feature = "wan-dhcp")]
use smoltcp::socket::{dhcpv4, dns, icmp};
#[cfg(feature = "wan-dhcp")]
use smoltcp::phy::{ChecksumCapabilities, Device as _};
use usb_device::{class_prelude::*, prelude::*};
use usbd_serial::SerialPort;

const HW_PIN_TXD: u8 = 14; // ISL3177E DI
const HW_PIN_RXD: u8 = 13; // ISL3177E RO

/// Our 10BASE-T (WAN) MAC: RX filter and smoltcp address.
const OUR_MAC: [u8; 6] = [0x12, 0x34, 0x56, 0x78, 0x9A, 0xBC];

/// Tell the Boot ROM about our application.
#[link_section = ".start_block"]
#[used]
pub static IMAGE_DEF: hal::block::ImageDef = hal::block::ImageDef::secure_exe();

/// Pico 2 board has a 12 MHz crystal.
const XTAL_FREQ_HZ: u32 = 12_000_000u32;

/// Watchdog timeout (HAL max ~8.38 s). Reboots the chip if core 0 stalls.
/// Fed every [`WDT_FEED_MS`], ~12× margin over normal stalls.
pub const WDT_TIMEOUT_US: u32 = 6_000_000;
/// Watchdog feed interval for the executor builds' dedicated feeder task.
pub const WDT_FEED_MS: u64 = 500;

/// 240 MHz overclock (VCO 1200 / 5). Integer PIO dividers: TX ÷12, RX ÷4.
#[cfg_attr(feature = "clock-150mhz", allow(dead_code))]
const PLL_SYS_240MHZ: PLLConfig = PLLConfig {
    vco_freq: HertzU32::MHz(1200),
    refdiv: 1,
    post_div1: 5,
    post_div2: 1,
};

/// PLL choice: 240 MHz, or stock 150 MHz with `clock-150mhz` (fractional dividers).
#[cfg(not(feature = "clock-150mhz"))]
const PLL_SYS_SELECTED: PLLConfig = PLL_SYS_240MHZ;
#[cfg(feature = "clock-150mhz")]
const PLL_SYS_SELECTED: PLLConfig = PLL_SYS_150MHZ;

/// Core-1 liveness counter: core 1 increments it, core 0 logs it.
static CORE1_TICKS: AtomicU32 = AtomicU32::new(0);

/// Core 1's stack (16 KB), aligned for the launch trampoline.
/// Sized for decode: a 1600-byte frame `Vec` plus trap and call frames.
#[repr(align(16))]
struct Core1Stack([usize; 4096]);
static mut CORE1_STACK: Core1Stack = Core1Stack([0; 4096]);

/// Core 1 entry: take `DMA_IRQ_0`, then decode queued images after each wake.
extern "C" fn core1_entry() -> ! {
    // Enable core-1 `mcycle` for CPU counters (router build).
    #[cfg(feature = "router")]
    cycles::enable_mcycle();
    // Safety: core 0 installed the RX engine before launching this core.
    unsafe {
        hal::arch::interrupt_unmask(hal::pac::Interrupt::DMA_IRQ_0);
        hal::arch::interrupt_enable();
    }
    let mut n: u32 = 0;
    loop {
        hal::arch::wfi();
        // The IRQ captured an image and re-armed. Decode here, with no deadline.
        eth_mac::drain_rx_images();
        n = n.wrapping_add(1);
        CORE1_TICKS.store(n, Ordering::Relaxed);
    }
}

#[hal::entry]
fn main() -> ! {
    let mut pac = hal::pac::Peripherals::take().unwrap();

    let mut watchdog = hal::Watchdog::new(pac.WATCHDOG);
    // PLL_SYS: see `PLL_SYS_SELECTED`.
    let xosc = setup_xosc_blocking(pac.XOSC, XTAL_FREQ_HZ.Hz()).unwrap();
    watchdog.enable_tick_generation((XTAL_FREQ_HZ / 1_000_000) as u16);
    let mut clocks = ClocksManager::new(pac.CLOCKS);
    let pll_sys = setup_pll_blocking(
        pac.PLL_SYS,
        xosc.operating_frequency(),
        PLL_SYS_SELECTED,
        &mut clocks,
        &mut pac.RESETS,
    )
    .unwrap();
    let pll_usb = setup_pll_blocking(
        pac.PLL_USB,
        xosc.operating_frequency(),
        PLL_USB_48MHZ,
        &mut clocks,
        &mut pac.RESETS,
    )
    .unwrap();
    clocks.init_default(&xosc, &pll_sys, &pll_usb).unwrap();

    let sio = hal::Sio::new(pac.SIO);
    let pins = hal::gpio::Pins::new(
        pac.IO_BANK0,
        pac.PADS_BANK0,
        sio.gpio_bank0,
        &mut pac.RESETS,
    );
    // TIMER0 out of reset. The wireless time driver owns ALARM0; don't arm alarms.
    let timer = hal::Timer::new_timer0(pac.TIMER0, &mut pac.RESETS, &clocks);

    // ── Router image: WAN (10BASE-T, core-1 RX) + cyw43 LAN under one executor.
    // No GP25 LED: GP25 is the gSPI CS.
    #[cfg(feature = "router")]
    {
        let _ = &timer; // the time driver reads TIMER0 directly
        // Enable core-0 `mcycle` for the forwarding counters.
        cycles::enable_mcycle();
        let sys_clk_hz = clocks.system_clock.freq().to_Hz();

        // WAN: GP14/GP13 to PIO0. Pin handles must outlive the executor.
        let _tx_pin: hal::gpio::Pin<_, FunctionPio0, _> = pins.gpio14.into_function();
        let _rx_pin: hal::gpio::Pin<_, FunctionPio0, _> = pins.gpio13.into_function();
        let mut fifo = sio.fifo;
        let (mac, core1_ok) = setup_eth_mac(
            pac.PIO0, pac.DMA, &mut pac.PSM, &mut fifo, &mut pac.RESETS, sys_clk_hz,
        );

        // LAN: GP24/GP29 to PIO1, WL_ON = GP23, CS = GP25. Bus idles through power-up.
        let _cyw_data: hal::gpio::Pin<_, hal::gpio::FunctionPio1, _> = pins.gpio24.into_function();
        let _cyw_clk: hal::gpio::Pin<_, hal::gpio::FunctionPio1, _> = pins.gpio29.into_function();
        let (mut pio1, pio1_sm0, _, _, _) = pac.PIO1.split(&mut pac.RESETS);
        let pwr = pins.gpio23.into_push_pull_output();
        let spi = wireless::PioSpiCyw43::new(&mut pio1, pio1_sm0, sys_clk_hz);

        wireless::run_router(
            mac, core1_ok, pwr, spi, pac.USB, pac.USB_DPRAM, clocks.usb_clock, &mut pac.RESETS,
            watchdog,
        );
    }

    // ── Wireless-only image: cyw43 LAN under the executor; 10BASE-T not started.
    #[cfg(all(feature = "wireless", not(feature = "router")))]
    {
        let _ = &timer; // keep TIMER0 out of reset
        let _cyw_data: hal::gpio::Pin<_, hal::gpio::FunctionPio1, _> = pins.gpio24.into_function();
        let _cyw_clk: hal::gpio::Pin<_, hal::gpio::FunctionPio1, _> = pins.gpio29.into_function();
        let (mut pio1, pio1_sm0, _, _, _) = pac.PIO1.split(&mut pac.RESETS);
        let sys_clk_hz_w = clocks.system_clock.freq().to_Hz();
        let pwr = pins.gpio23.into_push_pull_output();
        let spi = wireless::PioSpiCyw43::new(&mut pio1, pio1_sm0, sys_clk_hz_w);
        wireless::run(pwr, spi, pac.USB, pac.USB_DPRAM, clocks.usb_clock, &mut pac.RESETS, watchdog);
    }

    // ── 10BASE-T NIC image (default build). Exactly one arm is compiled per build.
    #[cfg(not(feature = "wireless"))]
    main_10bt(
        pac.PIO0, pac.DMA, pac.PSM, pac.USB, pac.USB_DPRAM, pac.RESETS, sio.fifo, clocks, pins, timer,
        watchdog,
    );
}

/// Build the 10BASE-T path: TX, carrier detect, and RX on PIO0, then launch
/// core 1 for RX. Returns the `EthMac` and whether core 1 launched.
///
/// GP13/GP14 must already be `FunctionPio0`. Call once. Order matters:
/// `EthRx::new` → `install_rx` → `launch_core1_riscv` (enables the IRQ).
fn setup_eth_mac(
    pio0: hal::pac::PIO0,
    dma: hal::pac::DMA,
    psm: &mut hal::pac::PSM,
    sio_fifo: &mut hal::sio::SioFifo,
    resets: &mut hal::pac::RESETS,
    sys_clk_hz: u32,
) -> (eth_mac::EthMac, bool) {
    // PIO0: SM0 TX, SM1 RX sampler, SM2 carrier detect. SM3 and PIO1 are free.
    let (mut pio0, sm0, sm1, sm2, _sm3) = pio0.split(resets);
    let eth_tx = eth_tx::EthTx::new(&mut pio0, sm0, sm2, HW_PIN_TXD, HW_PIN_RXD, sys_clk_hz);

    // DMA ch0/ch1 fill two static 16 KB half-buffers from the RX FIFO.
    let dma = dma.split(resets);
    let rx_buf_a = singleton!(: [u32; eth_rx::BUF_WORDS] = [0; eth_rx::BUF_WORDS]).unwrap();
    let rx_buf_b = singleton!(: [u32; eth_rx::BUF_WORDS] = [0; eth_rx::BUF_WORDS]).unwrap();
    let rx_carry =
        singleton!(: [u8; eth_rx::MAX_CARRY_BYTES] = [0; eth_rx::MAX_CARRY_BYTES]).unwrap();
    let eth_rx = eth_rx::EthRx::new(
        &mut pio0, sm1, HW_PIN_RXD, sys_clk_hz, dma.ch0, dma.ch1, rx_buf_a, rx_buf_b, rx_carry,
    );

    // Install RX before launching core 1. The launch is bounded, so a dead
    // core 1 returns an error instead of hanging.
    let _ = eth_mac::install_rx(eth_rx, OUR_MAC);
    let core1_stack = unsafe { &mut (*core::ptr::addr_of_mut!(CORE1_STACK)).0 };
    let core1_launch_ok =
        unsafe { multicore_riscv::launch_core1_riscv(psm, sio_fifo, core1_stack, core1_entry).is_ok() };

    // EthMac owns TX only; RX state is static.
    (eth_mac::EthMac::new(eth_tx), core1_launch_ok)
}

/// Default NIC build: smoltcp on a blocking core-0 poll loop. Never returns.
#[cfg(not(feature = "wireless"))]
#[allow(clippy::too_many_arguments)] // dispatch boundary — resources handed in by `main`
fn main_10bt(
    pio0: hal::pac::PIO0,
    dma: hal::pac::DMA,
    mut psm: hal::pac::PSM,
    usb: hal::pac::USB,
    usb_dpram: hal::pac::USB_DPRAM,
    mut resets: hal::pac::RESETS,
    mut sio_fifo: hal::sio::SioFifo,
    clocks: hal::clocks::ClocksManager,
    pins: hal::gpio::Pins,
    timer: hal::Timer<hal::timer::CopyableTimer0>,
    mut watchdog: hal::Watchdog,
) -> ! {
    let mut led = pins.gpio25.into_push_pull_output();

    // GP14 = DI, GP13 = RO, both PIO0. Handles must outlive the loop.
    let _tx_pin: hal::gpio::Pin<_, FunctionPio0, _> = pins.gpio14.into_function();
    let _rx_pin: hal::gpio::Pin<_, FunctionPio0, _> = pins.gpio13.into_function();
    let sys_clk_hz = clocks.system_clock.freq().to_Hz();
    let (mut mac, core1_launch_ok) =
        setup_eth_mac(pio0, dma, &mut psm, &mut sio_fifo, &mut resets, sys_clk_hz);

    let our_mac = EthernetAddress(OUR_MAC);
    let mut iface_config = Config::new(HardwareAddress::Ethernet(our_mac));
    iface_config.random_seed = timer.get_counter().ticks();
    let now0_inst = Instant::from_micros(timer.get_counter().ticks() as i64);
    let mut iface = Interface::new(iface_config, &mut mac, now0_inst);
    // Static IP matching the C reference. `wan-dhcp` leaves it to the DHCP client.
    #[cfg(not(feature = "wan-dhcp"))]
    iface.update_ip_addrs(|addrs| {
        addrs
            .push(IpCidr::new(IpAddress::Ipv4(Ipv4Address::new(192, 168, 37, 24)), 24))
            .unwrap();
    });

    // Socket slots: 5 by default, 6 with fd-bench, 8 with wan-dhcp.
    #[cfg(all(not(feature = "wan-dhcp"), not(feature = "fd-bench")))]
    let mut sockets_storage: [SocketStorage; 5] = [SocketStorage::EMPTY; 5];
    #[cfg(all(not(feature = "wan-dhcp"), feature = "fd-bench"))]
    let mut sockets_storage: [SocketStorage; 6] = [SocketStorage::EMPTY; 6];
    #[cfg(feature = "wan-dhcp")]
    let mut sockets_storage: [SocketStorage; 8] = [SocketStorage::EMPTY; 8];
    let mut sockets = SocketSet::new(&mut sockets_storage[..]);

    // UDP echo socket on port 1234.
    let mut udp_rx_meta = [udp::PacketMetadata::EMPTY; 8];
    let mut udp_rx_payload = [0u8; 2048];
    let mut udp_tx_meta = [udp::PacketMetadata::EMPTY; 8];
    let mut udp_tx_payload = [0u8; 2048];
    let udp_rx_buffer = udp::PacketBuffer::new(&mut udp_rx_meta[..], &mut udp_rx_payload[..]);
    let udp_tx_buffer = udp::PacketBuffer::new(&mut udp_tx_meta[..], &mut udp_tx_payload[..]);
    let udp_socket = udp::Socket::new(udp_rx_buffer, udp_tx_buffer);
    let udp_handle: SocketHandle = sockets.add(udp_socket);

    // HTTP server on port 80. `http-bulk-test` streams 1 MB instead.
    let mut tcp_rx_storage = [0u8; 1024];
    #[cfg(not(feature = "http-bulk-test"))]
    let mut tcp_tx_storage = [0u8; 1024];
    // Bulk test: a 32 KB send window keeps enough segments in flight that
    // residual collisions trigger fast retransmit, not an RTO stall.
    #[cfg(feature = "http-bulk-test")]
    let mut tcp_tx_storage = [0u8; 32 * 1024];
    let tcp_rx_buffer = tcp::SocketBuffer::new(&mut tcp_rx_storage[..]);
    let tcp_tx_buffer = tcp::SocketBuffer::new(&mut tcp_tx_storage[..]);
    let tcp_socket = tcp::Socket::new(tcp_rx_buffer, tcp_tx_buffer);
    let tcp_handle: SocketHandle = sockets.add(tcp_socket);

    // fd-bench: TCP upload sink on port 9999, run alongside the :80 download.
    #[cfg(feature = "fd-bench")]
    let mut sink_rx_storage = [0u8; 32 * 1024];
    #[cfg(feature = "fd-bench")]
    let mut sink_tx_storage = [0u8; 2048];
    #[cfg(feature = "fd-bench")]
    let sink_handle: SocketHandle = sockets.add({
        let mut sink = tcp::Socket::new(
            tcp::SocketBuffer::new(&mut sink_rx_storage[..]),
            tcp::SocketBuffer::new(&mut sink_tx_storage[..]),
        );
        // Immediate ACKs ride the gap after each data frame. A 10 ms delayed ACK
        // collided with Linux's tail-loss probe on the half-duplex wire.
        sink.set_ack_delay(None);
        sink
    });

    // WAN DHCP client sockets. Buffers live on this never-returning stack.
    #[cfg(feature = "wan-dhcp")]
    let dhcp_handle: SocketHandle = sockets.add(dhcpv4::Socket::new());

    #[cfg(feature = "wan-dhcp")]
    let mut icmp_rx_meta = [icmp::PacketMetadata::EMPTY; 8];
    #[cfg(feature = "wan-dhcp")]
    let mut icmp_rx_payload = [0u8; 512];
    #[cfg(feature = "wan-dhcp")]
    let mut icmp_tx_meta = [icmp::PacketMetadata::EMPTY; 8];
    #[cfg(feature = "wan-dhcp")]
    let mut icmp_tx_payload = [0u8; 512];
    #[cfg(feature = "wan-dhcp")]
    let icmp_handle: SocketHandle = sockets.add(icmp::Socket::new(
        icmp::PacketBuffer::new(&mut icmp_rx_meta[..], &mut icmp_rx_payload[..]),
        icmp::PacketBuffer::new(&mut icmp_tx_meta[..], &mut icmp_tx_payload[..]),
    ));

    // DNS query slots. Servers come from the DHCP lease.
    #[cfg(feature = "wan-dhcp")]
    let mut dns_queries: [Option<dns::DnsQuery>; 2] = [None, None];
    #[cfg(feature = "wan-dhcp")]
    let dns_handle: SocketHandle = sockets.add(dns::Socket::new(&[], &mut dns_queries[..]));

    #[cfg(feature = "wan-dhcp")]
    let mut wan = crate::wan::WanState::new();
    // The device's TX checksum capabilities — used to emit/parse ICMP echoes.
    #[cfg(feature = "wan-dhcp")]
    let wan_checksum: ChecksumCapabilities = mac.capabilities().checksum;

    // Broadcast UDP endpoint, matching the C reference host setup.
    let endpoint = eth_tx::UdpEndpoint {
        src_mac: OUR_MAC,
        dst_mac: [0xFF; 6], // broadcast
        src_ip: [192, 168, 37, 24],
        dst_ip: [192, 168, 37, 19],
        src_port: 1234,
        dst_port: 1234,
    };
    // USB CDC: appears on the host as /dev/ttyACM0.
    let usb_bus = UsbBusAllocator::new(hal::usb::UsbBus::new(
        usb,
        usb_dpram,
        clocks.usb_clock,
        true,
        &mut resets,
    ));
    let mut serial = SerialPort::new(&usb_bus);
    // Reset interface so `picotool -f` can reboot us to BOOTSEL.
    let mut reset_iface = pico_reset::PicoResetInterface::new(&usb_bus);

    // Serial = chip ID, as BOOTSEL reports it, so picotool can track the reboot.
    let mut serial_str: String<16> = String::new();
    match hal::rom_data::sys_info_api::chip_info() {
        Ok(Some(info)) => {
            let _ = write!(serial_str, "{:08X}{:08X}", info.wafer_id, info.device_id);
        }
        _ => {
            let _ = write!(serial_str, "0000000000000000");
        }
    }

    // 2e8a:000a is pico-sdk's stdio_usb CDC ID, which picotool recognizes.
    let mut usb_dev = UsbDeviceBuilder::new(&usb_bus, UsbVidPid(0x2e8a, 0x000a))
        .strings(&[StringDescriptors::default()
            .manufacturer("pico-10base-t-rs")
            .product("Pico-10BASE-T (Rust)")
            .serial_number(serial_str.as_str())])
        .unwrap()
        .max_packet_size_0(64)
        .unwrap()
        .device_class(2) // USB CDC
        .build();

    // NLPs at 16 ms intervals; UDP broadcast at 200 ms; heartbeat log at 1 s.
    let now0 = timer.get_counter().ticks();
    let mut next_nlp = now0;
    let mut next_udp = now0 + 200_000;
    let mut next_log = now0 + 1_000_000;
    // wan-dhcp: ping and DNS once a second.
    #[cfg(feature = "wan-dhcp")]
    let mut next_ping = now0 + 1_000_000;
    let mut nlps_sent: u32 = 0;
    let mut udp_sent: u32 = 0;
    let mut log_tick: u32 = 0;
    let mut led_state = false;

    let mut payload_buf: String<64> = String::new();
    let mut line: String<160> = String::new();

    #[cfg(feature = "http-bulk-test")]
    let mut http_bulk_state = HttpBulkState::Idle;

    // fd-bench: state for the per-second `[Sink]` line.
    #[cfg(feature = "fd-bench")]
    let mut fd_prev_sink: u32 = 0;
    #[cfg(feature = "fd-bench")]
    let mut fd_last_us: u64 = now0;
    // Loop iterations/s separates a loop-rate cap from a TCP cap.
    #[cfg(feature = "fd-bench")]
    let mut fd_loop_iters: u32 = 0;

    // Arm the watchdog; fed at the top of each iteration.
    watchdog.start(hal::fugit::MicrosDurationU32::micros(WDT_TIMEOUT_US));

    loop {
        watchdog.feed();
        #[cfg(feature = "fd-bench")]
        {
            fd_loop_iters = fd_loop_iters.wrapping_add(1);
        }
        usb_dev.poll(&mut [&mut serial, &mut reset_iface]);
        // Reboot on request here, after the SETUP STATUS stage completed.
        if let Some(kind) = reset_iface.take_pending_reboot() {
            hal::reboot::reboot(kind, pico_reset::RebootArch::Normal);
        }
        let now = timer.get_counter().ticks();

        // RX decodes on core 1; nothing to poll here.

        // smoltcp ingress (inbox) and egress.
        let now_inst = Instant::from_micros(now as i64);
        iface.poll(now_inst, &mut mac, &mut sockets);

        // WAN client work after iface.poll: lease, ping replies, DNS results.
        #[cfg(feature = "wan-dhcp")]
        {
            crate::wan::dhcp_apply(&mut iface, &mut sockets, dhcp_handle, dns_handle, &mut wan);
            crate::wan::ping_drain(&mut sockets, icmp_handle, &mut wan, &wan_checksum);
            crate::wan::dns_harvest(&mut sockets, dns_handle, &mut wan);
        }

        // UDP echo :1234 and HTTP :80.
        serve_udp_echo(&mut sockets, udp_handle);
        #[cfg(not(feature = "http-bulk-test"))]
        serve_http(&mut sockets, tcp_handle, log_tick, nlps_sent, udp_sent);
        #[cfg(feature = "http-bulk-test")]
        serve_http_bulk(&mut sockets, tcp_handle, &mut http_bulk_state);
        // fd-bench: drain the port-9999 upload sink (counts bytes, re-listens).
        #[cfg(feature = "fd-bench")]
        serve_fd_sink(&mut sockets, sink_handle);

        // NLP every 16 ms — IEEE 802.3 link-integrity keepalive.
        if now >= next_nlp {
            next_nlp = next_nlp.wrapping_add(16_000);
            mac.send_nlp();
            nlps_sent = nlps_sent.wrapping_add(1);
        }

        // UDP broadcast every 200 ms — mirrors the C reference's payload.
        if now >= next_udp {
            next_udp = next_udp.wrapping_add(200_000);
            payload_buf.clear();
            let _ = write!(
                payload_buf,
                "Hello World!! Raspico 10BASE-T Rust !! n={}",
                udp_sent
            );
            mac.send_udp_broadcast(&endpoint, payload_buf.as_bytes());
            udp_sent = udp_sent.wrapping_add(1);
        }

        // Once leased: ping and start a DNS query each second.
        #[cfg(feature = "wan-dhcp")]
        if now >= next_ping {
            next_ping = next_ping.wrapping_add(1_000_000);
            if wan.addr.is_some() {
                crate::wan::ping_send(&mut sockets, icmp_handle, &mut wan, &wan_checksum);
                crate::wan::dns_start(&mut iface, &mut sockets, dns_handle, &mut wan);
            }
        }
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

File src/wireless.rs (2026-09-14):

//! cyw43 (Pico 2 W) LAN on `rp235x-hal`, plus the router's executor tasks.
//!
//! Shims to the embassy/cyw43 world:
//! 1. **Time driver** — `embassy-time-driver` on TIMER0 (µs counter, ALARM0 IRQ).
//! 2. **Executor** — `embassy-executor` on `platform-riscv32`, run from main.
//! 3. **gSPI transport** — [`PioSpiCyw43`] on PIO1, instead of `cyw43-pio`.
//!
//! Design: `docs/router-plan.md` §4/§5.

use core::cell::RefCell;
use core::fmt::Write as _;
use core::sync::atomic::{AtomicU32, Ordering};
use core::task::Waker;

use critical_section::Mutex;
use embassy_executor::{Executor, Spawner};
use embassy_time::{Duration, Timer};
use embassy_time_driver::Driver;
use embassy_time_queue_utils::Queue;
use heapless::String;
use rp235x_hal as hal;
use smoltcp::iface::{Config, Interface, SocketSet, SocketStorage};
use smoltcp::socket::{tcp, udp};
use smoltcp::time::Instant;
use smoltcp::wire::{EthernetAddress, HardwareAddress, IpAddress, IpCidr, Ipv4Address, Ipv4Cidr};
use usb_device::{class_prelude::*, prelude::*};
use usbd_serial::SerialPort;

use crate::cyw43_phy::Cyw43Phy;
use crate::dhcp_server::DhcpServer;
use hal::pac::PIO1;
use hal::pio::{
    PIOBuilder, PinDir, PinState, Running, Rx, ShiftDirection, StateMachine, Stopped, Tx,
    UninitStateMachine, SM0,
};

/// WL_ON (GP23) push-pull output, concrete so the Runner task can name it.
pub type WlOnPin =
    hal::gpio::Pin<hal::gpio::bank0::Gpio23, hal::gpio::FunctionSioOutput, hal::gpio::PullDown>;

// =====================================================================
// 0. gSPI pins, raw GPIO helpers, and the PIO1 state machine
// =====================================================================
//
// Pico 2 W CYW43 pins: GP23 = WL_ON, GP24 = DATA, GP25 = CS, GP29 = CLK.

const PIN_DATA: u32 = 24;
const PIN_CS: u32 = 25;
const PIN_CLK: u32 = 29;

// Raw SIO GPIO access, without claiming typed HAL pins.
#[inline]
fn gpio_set(n: u32) {
    unsafe { (*hal::pac::SIO::ptr()).gpio_out_set().write(|w| w.bits(1 << n)) };
}
#[inline]
fn gpio_clr(n: u32) {
    unsafe { (*hal::pac::SIO::ptr()).gpio_out_clr().write(|w| w.bits(1 << n)) };
}
#[inline]
fn gpio_oe(n: u32, output: bool) {
    let sio = unsafe { &*hal::pac::SIO::ptr() };
    if output {
        sio.gpio_oe_set().write(|w| unsafe { w.bits(1 << n) });
    } else {
        sio.gpio_oe_clr().write(|w| unsafe { w.bits(1 << n) });
    }
}

/// Route a pin to SIO and clear pad isolation (RP2350 pads boot isolated).
fn gpio_to_sio(n: u32) {
    let io = unsafe { &*hal::pac::IO_BANK0::ptr() };
    let pads = unsafe { &*hal::pac::PADS_BANK0::ptr() };
    pads.gpio(n as usize).modify(|_, w| {
        w.ie().set_bit();
        w.od().clear_bit();
        w.iso().clear_bit()
    });
    io.gpio(n as usize)
        .gpio_ctrl()
        .write(|w| unsafe { w.funcsel().bits(5) }); // 5 = SIO
}

// gSPI SM: each transaction pushes [write_bits-1, read_bits-1, words...].
// Clocks writes out MSB-first (latched on CLK rise), turns DATA around, then
// samples reads while CLK is high. Timing matches embassy's cyw43-pio.
// CLK = GP29 (side-set), DATA = GP24. CS is SIO; WL_ON is cyw43's `pwr` pin.

/// Build the PIO1 gSPI SM with the bus idle (CLK, DATA low); returned stopped.
/// Doesn't touch CS or WL_ON.
fn build_gspi_sm(
    pio: &mut hal::pio::PIO<PIO1>,
    sm: UninitStateMachine<(PIO1, SM0)>,
    sys_clk_hz: u32,
) -> (
    StateMachine<(PIO1, SM0), Stopped>,
    Tx<(PIO1, SM0)>,
    Rx<(PIO1, SM0)>,
) {
    // Program format: see the section comment (docs/router-plan.md §11 #1).
    let program = pio::pio_asm!(
        ".side_set 1",
        ".wrap_target",
        "    out x, 32      side 0", // X = write_bits-1  (autopull from FIFO)
        "    out y, 32      side 0", // Y = read_bits-1
        "    set pindirs, 1 side 0", // DATA = output
        "wloop:",
        "    out pins, 1    side 0", // drive DATA bit (MSB first), CLK low
        "    jmp x-- wloop  side 1", // CLK high → chip latches on rising edge
        "    set pindirs, 0 side 0", // turnaround: DATA = input, CLK low
        "    nop            side 0", // CLK stays LOW through turnaround
        "rloop:",
        "    in pins, 1     side 1", // CLK high → sample chip's DATA
        "    jmp y-- rloop  side 0", // CLK low; loop
        ".wrap",
    );
    let installed = pio.install(&program.program).unwrap();

    // 30 MHz PIO = 15 MHz gSPI (2 cycles per bit). embassy runs ~33 MHz.
    const GSPI_PIO_HZ: f32 = 30_000_000.0;
    let (div_int, div_frac) = crate::pio_util::clock_divider(sys_clk_hz, GSPI_PIO_HZ);
    let (mut sm, rx, tx) = PIOBuilder::from_installed_program(installed)
        .out_pins(PIN_DATA as u8, 1)
        .set_pins(PIN_DATA as u8, 1)
        .in_pin_base(PIN_DATA as u8)
        .side_set_pin_base(PIN_CLK as u8)
        .out_shift_direction(ShiftDirection::Left) // MSB first
        .in_shift_direction(ShiftDirection::Left) // MSB first
        .autopull(true)
        .pull_threshold(32)
        .autopush(true)
        .push_threshold(32)
        .clock_divisor_fixed_point(div_int, div_frac)
        .build(sm);
    // Bus idle: CLK and DATA driven low until start().
    sm.set_pindirs([
        (PIN_CLK as u8, PinDir::Output),
        (PIN_DATA as u8, PinDir::Output),
    ]);
    sm.set_pins([
        (PIN_CLK as u8, PinState::Low),
        (PIN_DATA as u8, PinState::Low),
    ]);
    (sm, tx, rx)
}

// =====================================================================
// 1. embassy-time driver on RP2350 TIMER0
// =====================================================================
//
// A 1 MHz tick matches TIMER0's µs counter. ALARM0 drives wakeups.

/// Time-driver alarm IRQ.
const ALARM_IRQ: hal::pac::Interrupt = hal::pac::Interrupt::TIMER0_IRQ_0;

struct RpTimeDriver {
    /// The 16-slot generic timer queue (waker storage). Guarded by a
    /// `critical_section` mutex so the IRQ and task contexts can't race.
    queue: Mutex<RefCell<Queue>>,
}

embassy_time_driver::time_driver_impl!(
    static TIME_DRIVER: RpTimeDriver = RpTimeDriver {
        queue: Mutex::new(RefCell::new(Queue::new())),
    }
);
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

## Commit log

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2026-05-26 Eliminate residual host RX errs after R6 with IFG padding on every TX path
    R6 IRQ-driven RX traded 0 host RX errs (R5 polled) for 8/30s under
    concurrent stress. The TX critical_section in send_raw_frame fixed the
    obvious IRQ-preempts-mid-frame case but left a subtler bug: any TX path
    that ends in TP_IDL without padding the line with ≥ 9.6 µs of IDLE lets
    the next frame's preamble land inside the host NIC's expected IFG and
    score it bad-FCS. In polled mode this never showed up because mac.poll's
    decode time naturally introduced > 100 µs of dead air between back-to-
    back smoltcp egresses; in IRQ mode that dead time is gone.
    Fix: push 12 all-zero FIFO words (≈ 9.6 µs of PIO IDLE dispatc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
    [eth_tx.rs]
2026-05-27 R7: IRQ-side MAC filter via cheap peek_dst_mac
    Decode just the 6 dst-MAC bytes (no Vec alloc, ~1–2 µs) before deciding
    whether to pay for the full Manchester decode + CRC + inbox push. Skips
    stranger-unicast traffic — saves IRQ CPU on busier LANs and shortens
    the critical_section'd decode window under broadcast bursts.
    - EthRx::peek_dst_mac: same F-find + SFD-lock as decode_frame but
    capped at ~200 bits (preamble + SFD slack + 48 MAC bits) and packed
    into a stack [u8; 6] instead of allocating.
    - EthRxShared learns our MAC via install_rx(rx, our_mac); the IRQ
    handler calls peek_dst_mac per active run, accepts unicast-to-us +
    all multicast/broadcast (smoltcp does finer filtering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
    [eth_mac.rs, main.rs]
2026-05-27 R8: tiny HTTP server on port 80
    Enables smoltcp's socket-tcp feature and binds a TCP listener that serves
    a single-shot HTTP/1.0 200 response with build info + per-second nlps /
    udp_sent counters, then re-listens after close. 1 KB RX + 1 KB TX
    buffers — enough for any reasonable GET request and a ~65-byte response
    body, comfortably within RP2350 SRAM.
    Validates that the IRQ-driven RX path + smoltcp handle full TCP
    handshake, retransmission/windowing, and FIN cleanly under load.
    Concurrent stress (30s of ping at 10 Hz + UDP echo at 10 Hz + 15
    sequential curls): ping 300/300, UDP 299/300, curls 15/15, host RX
    errs 1 — every protocol at or above the polled R5 baseline.
    Body format:
    Hell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
    [main.rs]
2026-05-27 R9: pico-sdk reset interface — picotool -f self-reboot works
    Implements the same vendor USB interface (class=0xFF, sub=0x00,
    proto=0x01, no endpoints) that pico-sdk's stdio_usb exposes. Picotool
    sends a control transfer to bRequest=1 (RESET_REQUEST_BOOTSEL); the new
    PicoResetInterface queues a reboot in control_out, and the next main-
    loop iteration calls hal::reboot::reboot(BootSel{...}, Normal). The
    chip resets into BOOTSEL ~500 ms later and picotool flashes it
    end-to-end with no manual button-press and no OpenOCD fallback.
    Two subtle bits worth flagging (both captured in gotcha #4 of RESUME):
    1. Picotool sends a **Class** request type (bmRequestType=0x21), not
    Vendor, even though o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
    [main.rs]
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2026-05-27 Review: safe idiom fixes + on-device perf findings
    Efficiency/idiom review of the firmware. Applied four behavior-preserving
    idiom fixes (verified on the wire: UDP 5/s byte-perfect, ping 5/5):
    - static mut RAW_FRAME -> owned EthTx.raw_frame field (kills the Rust-2024
    hard-error path); disjoint-borrow lets the critsec loop read raw_frame
    while writing tx
    - dedup'd PIO clock-divider math into pio_util::clock_divider (TX + RX)
    - two hand-rolled hex-dump loops -> one hex_dump() over chunks(16)
    - corrected stale "Phase R1" / EthMac::poll docs
    Also measured the RX hot path on-device (Hazard3 mcycle @150 MHz, telemetry
    over UDP since CDC reads go flaky post-BOOTSEL). Measuring re-prioritized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
    [eth_tx.rs, main.rs]
2026-05-27 Performance plan #1: single-pass RX decoder (fixes full-MTU truncation)
    Replace the two-pass decode_frame (sample bits -> Vec<u8,2048> -> pack ->
    Vec<u8,1600>) with a single pass that reads each data bit on demand via a
    shared data_bit() helper and packs straight to bytes. F-find and SFD-find
    are factored into shared find_first_falling_edge / find_sfd_end helpers used
    by both decode_frame and peek_dst_mac (which is now single-pass too, dropping
    its 200-byte stack array). Output is sized to MAX_FRAME_BYTES instead of the
    magic 1600-bit cap.
    Correctness: the old 1600-bit cap truncated frames past ~199 bytes, so
    full-MTU RX never actually worked despite MTU=1500. Verified on the wire -
    a paylo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
    [main.rs]
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2026-05-27 Add `diag` feature: gate verbose per-second diagnostics (off by default)
    The 1 Hz status block over USB CDC + its formatting code were steady-state
    bloat. Gate the verbose parts behind a `diag` cargo feature (off by default):
    the [Mac] TX-categorization line, the TX/frame hex dumps, the decoded-frame
    pretty-print, and hex_dump itself. The cheap [R2b] heartbeat + [Rx] decode
    summary (dec/ok/fail/filt/dst) always print.
    Gated the OUTPUT rather than threading #[cfg] through the EthMac/EthTxToken/IRQ
    hot paths: the EthMac TX stat writes become dead (never read without diag) and
    are dead-store-eliminated by LTO, and the stat structs' pub fields avoid
    dead-code warnings - so no cfg in the Device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
    [main.rs]
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2026-05-28 PIO decoder Phase 2b: clock-recovery decoder brought up on hardware
    The PIO clock-recovery Manchester decoder (eth_rx_pio.rs, PIO1 SM0) runs on
    the wire at zero CPU cost and cancels the A1 clock drift. Measured: FCS-OK 8/8
    to a 512 B payload (flat-perfect, no drift ramp), degrading with frame size to
    a jitter-limited loss-of-lock in the full-MTU tail (slips at byte ~1000-1346,
    then free-runs emitting 0xaa/0x55).
    - eth_rx_pio.rs: two-state edge tracker; the [8] boundary-skip delay is
    confirmed optimal on wire ([9] was worse - a deterministic slip at byte 960).
    - main.rs: TEMP bring-up scaffolding runs the decoder in parallel with the
    working PIO0 RX and dumps decoded-byte windows over UD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
    [main.rs]
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2026-05-28 PIO decoder Phase 2d v3: 180 MHz overclock + v1 -- ~40% full-MTU FCS-OK
    Took the overclock route from §12a. **Major win on the wire.**
    main.rs: manual PLL_SYS setup at 180 MHz (VCO 1080 / (6*1)). Required because
    rp235x-hal's init_clocks_and_plls defaults to 150 MHz. Flash QMI auto-scaled
    fine; no manual config needed. SWD/DAPLink flash recommended (picotool self-
    reboot is risky on overclock since a failed boot leaves no USB reset path).
    Side effect (cleanup bonus): TX and RX PIO dividers now INTEGER (TX/9, RX/3) --
    no more fractional-divider jitter. See sysclk-integer-pio-dividers memory.
    eth_rx_pio.rs: reverted v2 (polling-windowed, 02bc710) to v1 (sample-by-pin,
    wait-based). v2's pol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
    [main.rs]
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2026-05-28 Phase 3b — port decode_edge_track to Rust + offline validation PASSES
    src/eth_rx_dpll.rs: Rust port of the validated Python decode_edge_track DPLL
    algorithm from tools/clock-recovery/harness.py. Pure no_std (heapless::Vec
    output), no allocator, same I/O shape as eth_rx::decode_frame so it can
    drop-replace the open-loop sampler in the IRQ handler. The decode is open-
    loop F + SFD search (preamble has no boundary edges, so open-loop sampling
    is reliable there) then edge-track DPLL from the first data bit onwards —
    search ±W samples around each expected mid-bit edge, sample one before the
    edge, coast through a missed edge to the nominal next position.
    tools/dpll-rust/: standalone host-sid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
    [main.rs]
2026-05-28 Phase 3b second half — dpll cargo feature + on-wire IRQ-budget confirmation
    Added a `dpll` cargo feature (default off): with `--features dpll`, the
    RX IRQ handler in eth_mac::process_completed_half swaps the open-loop
    EthRx::decode_frame for the new eth_rx_dpll::decode_frame_edge_track.
    SFD_SEARCH_BITS + decode_frame are cfg-gated dead-code-allowed under the
    feature so both modes build clippy-clean.
    On-wire result (SWD-flashed --features dpll, 240 MHz):
    - Ping: 80% (small frames mostly decode).
    - UDP echo 512 B: 8/10.
    - UDP echo 1472 B (100 attempts): **0/100**, all timeout.
    - Device CDC log: `[Rx] dec=0 ok=0 fail=0` — the IRQ never produces
    decoded frames.
    The dec=0 is the diagnost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
    [eth_mac.rs]
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2026-05-28 Phase 3b diagnosis — residual is PHY-limited (escape hatch met)
    Added failed-frame capture in the RX IRQ + UDP dump under --features dpll
    so the host can score per-byte error positions on FCS-failed frames against
    the known counter payload — distinguishes PHY-limited (flat) from decoder-
    limited (drift ramp / mid-frame cliff).
    eth_mac.rs: EthRxShared gains a diag_fail_data buffer + id, captured in
    process_completed_half when FCS fails. snapshot_diag_failed() copies the
    latest one out under a brief critical_section.
    main.rs: under --features dpll, dump the latest failed frame to UDP host
    port 1235 every 50 ms with a [magic_u32 | id_u32 | orig_len_u16] header,
    up to 1460 bytes of frame d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
    [eth_mac.rs, main.rs]
2026-05-28 R10 — Productize edge-track DPLL as the default Manchester decoder
    §9d's locked-acceptance escape hatch is met (PHY-limited residual, flat
    per-byte error bins), so the `--features dpll` opt-in is retired. The
    edge-track DPLL is now the only full-frame decoder; the open-loop sampler
    and the temporary feature gate are gone.
    Cleanup (net -278 lines):
    - **Cargo.toml**: removed `dpll = []` feature.
    - **src/eth_mac.rs**: deleted the `#[cfg(feature = "dpll")]` gates around
    the IRQ decoder call (now unconditional DPLL); removed `diag_fail_data`
    + `diag_fail_len` + `diag_fail_id` from `EthRxShared`, the in-IRQ
    failed-frame capture, and the `snapshot_diag_failed` accessor.
    - **src/eth_rx.rs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
    [eth_mac.rs, main.rs]
2026-05-28 Experiment 3 — restore open-loop decoder behind a feature flag
    Triage step in the FCS-ceiling investigation prompted by Niccle (ctrlsrc.io)
    reporting 0% CRC-fail at full-MTU with a simpler open-loop locked-once
    decoder on essentially identical hardware (same ISL3177E + 10 nF AC-coupling
    + 100 Ω load + ~50 Ω source termination + integrated-magnetics magjack). Our
    R10 productized DPLL caps at ~50% FCS-OK on the same wire. The plan in
    ~/.claude/plans/lets-come-up-with-velvet-stroustrup.md sequences cheap
    experiments to find the differentiator; this is experiment 3, the lowest-
    effort code change that A/Bs the decoder choice directly.
    Brings back the pre-R10 EthRx::decode_frame (single-pass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
    [eth_mac.rs, main.rs]
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2026-05-28 Experiment 4 — bulk HTTP endpoint for TCP throughput methodology check
    Triage continuation. After experiments 3, 5, 6 ruled out decoder choice,
    sample rate, and overclock as the FCS-ceiling differentiator with Niccle,
    hypothesis #4 (test-methodology asymmetry) was the leading remaining lead.
    This experiment tests it directly: measure user-visible TCP throughput on
    an idle wire, vs Niccle's published 620 kB/s. If we land in their range
    despite our FCS counter showing 30-70 % fail under stress, the gap is
    methodology rather than real reliability.
    New cargo feature `http-bulk-test = []` (off by default, production binary
    unchanged). When enabled:
    - src/main.rs: swaps the R8 tiny-info serve_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
    [main.rs]
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2026-05-28 R12d — Phase 3d: PIO carrier-sense (recovers most throughput; residual collisions remain)
    Restore the carrier-sense Phase 3c removed (gotcha #10): a dedicated
    carrier-detect SM on PIO0 SM2 watches RO (GP13) via jmp_pin and raises
    host-visible PIO IRQ flag 0 while the line is toggling, clearing it after
    ~267 ns of quiet (GUARD=8 @ 60 MHz). 10BASE-T idle is a steady level, so
    carrier == recent transitions (same fact the RX find_active_run relies on).
    eth_tx.rs: wait_carrier_idle() polls flag 0 before the preamble in
    send_raw_frame / send_udp_broadcast / send_nlp (outside the critical section,
    so we defer with interrupts enabled). Bounded spin (CARRIER_WAIT_SPINS) so a
    stuck-busy flag degrad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
    [eth_tx.rs, main.rs]
2026-05-28 R12e — Phase 3e: CSMA/CA backoff + larger TCP window → multicore RX is a net win
    Close the residual-collision variance from Phase 3d. The multicore RX stack
    (3a+3c+3d+3e) is now strictly better than single-core on every axis.
    eth_tx.rs — CSMA/CA randomized backoff:
    csma_acquire() = carrier-sense idle (3d) -> random xorshift backoff
    (0-15 slots ~= 0-15 us) -> re-sense; defer+retry if the wire got taken
    during the backoff (bounded attempts, then TX anyway). Replaces plain
    wait_carrier_idle in send_raw_frame (the TCP path). The random backoff
    breaks the synchronized-start tie with the host after the wire frees -
    our dominant residual collision. NLP/UDP-broadcast keep plain ca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
    [eth_tx.rs, main.rs]
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2026-05-28 R13 (scaffold) — board-independent cyw43 + async-runtime foundation (compiles + links)
    Branch r13-wireless-scaffold. New `wireless` cargo feature (OFF by default —
    production 10BASE-T build byte-unchanged). `cargo build --release --features
    wireless` compiles AND links for riscv32imac.
    De-risking (the point of the spike):
    - cyw43 0.7.0 + cortex-m 0.7.7 + cortex-m-rt 0.7.5 COMPILE for riscv32imac
    (the cortex-m-rt compile_error fear was wrong — it target-gates to nothing).
    Option A (keep RISC-V) is viable.
    - embassy-executor 0.10 `platform-riscv32` backend + a custom embassy-time
    driver LINK on Hazard3 — the #1 risk (async runtime on RISC-V) is cleared.
    - Pinned the compatible v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
    [main.rs, wireless.rs]
2026-05-28 R13 (on-board) — gSPI bit-bang probe + diagnostics; chip not yet responding
    Board swap verified first: production 10BASE-T firmware runs clean on the
    Pico 2 W (ping 100%, curl 200, UDP 10/10, core 1 + carrier-sense all working) —
    the WAN side fully survived the swap (GP13/14 unchanged).
    Added a synchronous gSPI bring-up probe (src/wireless.rs::probe_cyw43, gated by
    `wireless`, runs inside the production build so the CDC/UDP telemetry is
    available): powers WL_ON (GP23), bit-bangs read32_swapped(REG_BUS_TEST_RO) over
    GP24/25/29, loops up to 64×, logs first/last/stable over CDC ([Cyw43] line).
    On-board result: test reads VARY across the loop (first=0x06060606,
    last=0xfdda7d5b, stable=0)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
    [main.rs, wireless.rs]
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2026-05-29 R13 Step 1 — PIO1 gSPI transport proven (CYW43 reads 0xFEEDBEAD)
    Replace the dead-end bit-bang gSPI probe with a self-contained, FIFO-driven
    PIO1 gSPI transport (wireless::probe_cyw43_pio) and prove it on-device: the
    CYW43 bus test register now reads 0xFEEDBEAD over our own transport on the
    Hazard3/RISC-V stack. Validates the pivot premise — a faithful PIO gSPI
    transport talks to the chip without embassy-rp.
    Key fix (hard-won, see RESUME gotcha #11): hold the gSPI bus idle (CLK low,
    CS high, DATA low) THROUGH the WL_ON power-up. A floating CLK during CYW43
    power-up latches it into a wrong gSPI mode — why the bit-bang and the first PIO
    attempt both read float on a known-good board. Als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
    [main.rs, wireless.rs]
2026-05-29 R13 Steps 2 + 3a — async SpiBusCyw43 transport; cyw43::new() works over PIO1
    Step 2: implement the real async SpiBusCyw43 on PioSpiCyw43 — cmd_write/cmd_read
    do the proven PIO1 FIFO push/pull (busy-poll; DMA later), bit counts matching
    embassy cyw43-pio 0.7.0. Factor a shared build_gspi_sm so the probe and the
    transport use one gSPI program (no drift).
    Step 3a: cyw43::new() now completes over our transport. wireless::cyw43_new_blocking
    drives it via embassy_futures::block_on (no executor — block_on busy-spins; the
    TIMER0 time-driver's now() resolves cyw43's power-up Timer::after delays). On-device
    the full 231 KB firmware + nvram download over PIO1 and the real driver handshake
    both p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
    [main.rs, wireless.rs]
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2026-05-29 R14.1 — persistent executor + continuous cyw43 Runner (no more block_on)
    Graduate R13's block_on bring-up to the embassy executor owning core 0:
    spawn Runner::run() as a long-lived task so the chip stays up, plus a USB
    poll task (CDC telemetry + picotool reset) so `cargo run` keeps working
    while the executor owns the core. Bootstrap task: cyw43::new → spawn Runner
    → Control::init(clm) → blink the onboard LED forever (the LED can only keep
    toggling if the Runner is continuously servicing gpio_set ioctls).
    main() now does the shared clock/pin/timer setup then dispatches: the
    wireless arm builds the PIO1 gSPI transport + WL_ON and calls
    wireless::run(...) (-> !, standalone — 10BASE-T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
    [main.rs, wireless.rs]
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2026-05-29 R14.3 — cyw43 NetDriver → smoltcp phy::Device adapter + LAN Interface
    New src/cyw43_phy.rs: Cyw43Phy wraps cyw43's NetDriver (which is an *async*
    embassy_net_driver::Driver, NOT a sync smoltcp plug) and bridges it to
    smoltcp's phy::Device by calling Driver::receive/transmit with a noop-waker
    Context — the poll-style None/Some is exactly smoltcp's synchronous contract,
    and our net task re-polls on its own cadence. This corrects router-plan
    §12.1, which assumed the sync try_rx_buf/try_tx_buf API was reachable: that
    lives on the producer-side ch::Runner, which cyw43's Runner owns internally
    and never exposes. Hand-rolled noop waker (not Waker::noop) to keep MSRV 1.82.
    wireless.rs: stop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
    [main.rs, wireless.rs]
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2026-05-29 R14.4 — LAN DHCP server (src/dhcp_server.rs)
    New DhcpServer: a smoltcp UDP :67 socket in net_task answers DISCOVER with
    OFFER and REQUEST with ACK, handing out a fixed 192.168.4.0/24 pool
    (.10..=.41) with router + server-id = 192.168.4.1, /24 mask, 1 h lease,
    broadcast to 255.255.255.255:68. Leases keyed by client MAC (fixed table, no
    alloc). Reuses smoltcp's DhcpRepr/DhcpPacket wire codec via a new
    wireless-only smoltcp/proto-dhcpv4 feature (default 10BT smoltcp set
    unchanged). No DNS option yet — deferred to R18 (DNS relay); also dodges
    smoltcp's heapless-0.9 dns_servers Vec vs our 0.8. DHCP_TX counter surfaced
    as dhcp= in the [Cyw43] line.
    On-device: a host RTL88x2bu client ran dhcli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
    [main.rs, wireless.rs]
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2026-05-29 R15a — WAN as DHCP client (10BASE-T → upstream IP/route/DNS)
    New wan-dhcp feature (off by default): main_10bt gains smoltcp dhcpv4
    client + icmp(ping 8.8.8.8) + dns(resolve) sockets + [Wan] telemetry.
    On-device: DHCPACK 192.168.37.129, echo replies (id 0x42) ~13ms,
    example.com resolved. Host harness tools/wan-test-host.sh (nftables).
    Plan + R15a/R15b split: docs/r15-plan.md.
    [main.rs]
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2026-06-02 R17 — wire NAPT into the WAN ForwardingDevice (egress src-rewrite + conntrack-aware ingress)
    forward.rs: the WAN device (new_napt) now NATs. egress() (LAN->WAN) rewrites IP src -> our WAN IP + L4 src port/id -> an allocated WAN id via conntrack.outbound(), fixing the L4 checksum incrementally (the IP header checksum is recomputed by the existing fill_checksum after TTL--). receive()'s classifier becomes conntrack-aware (classify_frame): a reply addressed to our WAN IP that matches a tracked flow is rewritten back to the LAN client and forwarded (Transit); a miss stays Local, so the Pico's own ping/DNS are untouched. parse_l4 + napt_rewrite_src/dst handle TCP/UDP/ICMP-echo with the right of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
    [wireless.rs]
2026-06-02 R17 — fix forwarded-frame TX overflow (router halt) + NAT_DROP miscount
    eth_mac.rs: EthTxToken's scratch buffer was [u8; MTU=1500]. The Pico's own egress is capped at the IP MTU by max_transmission_unit, so it never overflowed — but FORWARDED frames bypass that cap: egress() passes the raw frame length, and a full-MTU Ethernet frame is 1514 B > 1500, so the buf[..len] slice went out of bounds and panicked. The debug_assert(len <= MTU) guard is compiled out in release (debug-assertions=false), so it halted the router (panic_halt). The iPhone's large QUIC/TLS frames triggered it; a laptop's tiny ping never did. Sized the buffer to MAX_FRAME_BYTES (1600, matching the RX side + the forwardin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
    [eth_mac.rs]
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2026-06-02 R18 — DNS (NAT-passthrough) + mgmt UI: LAN clients resolve names via the Pico
    DNS, no relay (router-plan §6.4 "simplest"): the LAN DHCP server now advertises
    a DNS server in every OFFER/ACK, emitted as a raw RFC-2132 option 6 via
    DhcpRepr.additional_options to sidestep smoltcp-0.13's heapless-0.9 dns_servers
    Vec (our crate is heapless 0.8). The offered address is the WAN-learned upstream
    resolver (wan.dns0), published by wan_task into the new dhcp_server::LAN_DNS_OFFER
    atomic; defaults to 8.8.8.8 until the lease lands. Since R17 NAPT already forwards
    LAN->WAN UDP, a client's :53 query NATs out and the reply NATs back like any flow
    — zero relay code.
    Mgmt UI (serve_status_http): adds DN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
    [wireless.rs]
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2026-06-02 R19 — cold-start gateway-ARP on lease: kill the constant [Fwd] drop
    The WAN ForwardingDevice resolves the gateway's next-hop MAC from WAN_NEIGH,
    which is populated only by the passive learn() — and learn() is gated off until
    the DHCP lease sets our_ip. So there was a window after the lease where the
    gateway MAC wasn't known yet and forwarded LAN->WAN frames hit FWD_DROP
    ("next-hop MAC not learned yet", forward.rs) — the documented constant
    [Fwd] drop~4 at cold-start.
    Fix: proactively ARP the WAN gateway. forward.rs gains build_arp_request() +
    ForwardingDevice::arp_gateway() (a broadcast who-has sent via the inner phy;
    EthMac pads it to 60B + FCS, and the reply repopulates WAN_NEIGH vi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
    [wireless.rs]
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2026-06-02 R18/R19a cleanup (post-review): dedup ARP prefix, POOL_LEN-sized body, mac_str
    Behavior-preserving cleanups from the code review (no correctness changes):
    - forward.rs: the 6-byte Ethernet/IPv4 ARP header prefix was written by
    build_arp_request and matched by learn() as two separate literals. Extract a
    single `const ARP_ETH_IPV4_PREFIX` so the writer and parser can't drift.
    - dhcp_server.rs / wireless.rs: the mgmt-page body String capacity was a magic
    1792 justified by a hand comment. Make POOL_LEN `pub` and derive the cap from
    it (256 + POOL_LEN*40 + 320) so it can't silently undersize if the pool grows.
    - main.rs / wireless.rs: the `{:02x}:..` MAC format was open-coded in three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
    [main.rs, wireless.rs]
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2026-06-02 instr: routed-throughput + drop diagnostics (perf characterization, step 1)
    First instrumentation increment toward characterizing the full routed/NAT'd path
    (WiFi client -> NAPT -> 10BT WAN) — which the R11/R12 numbers never covered (those
    were the 10BT NIC in isolation).
    forward.rs data-plane counters:
    - per-direction egressed bytes (FWD_BYTES_TO_WAN/LAN) for throughput
    - FWD_DROP split by cause (qfull / no-nexthop / nat-exhaust / tx-busy / other)
    via a count_drop() helper so the aggregate + breakdown can't drift
    - per-direction egress-queue high-water (FWD_QHWM_L2W/W2L, vs CHAN_DEPTH)
    Surfaced two ways:
    - a 1 Hz [Perf] CDC line in usb_task: per-second up/dn KB/s + pps, queue/conntrac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
    [wireless.rs]
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

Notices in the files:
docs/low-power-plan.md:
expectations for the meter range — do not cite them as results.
